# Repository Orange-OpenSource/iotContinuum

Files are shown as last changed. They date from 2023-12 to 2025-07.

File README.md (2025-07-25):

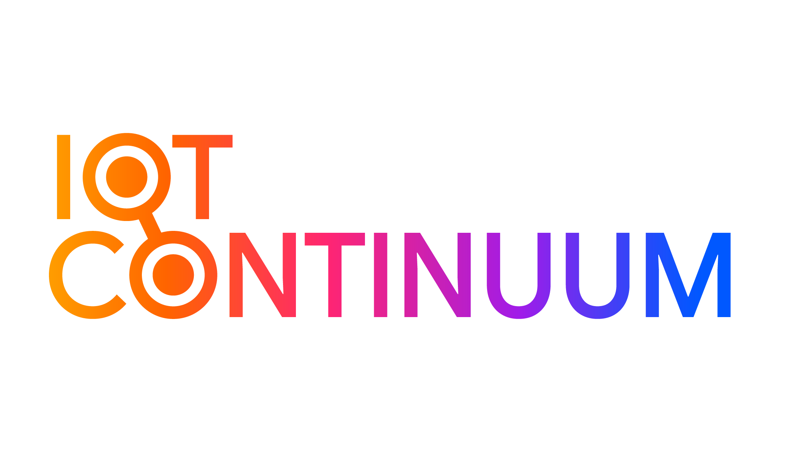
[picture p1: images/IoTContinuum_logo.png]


# IoT Continuum Development Kit




<picture>
 <source media="(prefers-color-scheme: dark)" srcset="images/devkit_general-white.png">
 <source media="(prefers-color-scheme: light)" srcset="images/devkit_general-black.png">
 IoT Continuum Dev Kit
</picture>

## Why IoT Continuum

With IoT Continuum, gain in efficiency by capitalizing on everything that has been achieved in your project's previous development cycles. Thus, the components and the design used from the start-up phase (PoC – Proof of Concept) are scalable and compatible with the industrial deployment phase. A new design will therefore no longer be necessary either during the next phase of Proof Of Value (convincing) or in the final phase of deployment and industrial scale-up.

There are two models of Development Kit. 

One is based on an HL7812 LTE-M/NB-IoT cellular connectivity module and the next is based on an RC7620 LTE-Cat 1 module. Both of these modules are from SEMTECH.
This development kit is provided by IoT Continuum to developers who are willing to start from scratch with a development kit approved by IoT Continuum.

Read more on [IoT Continuum Website](https://iotjourney.orange.com/fr-FR/iotcontinuum)

## List of available Devkits. 

•	DEVKIT HL7812
All documentation and source code for the HL7812 Devkit are available from the IoT Continuum [HL7812 Devkit link](DevKit-HL7812/README.md).

•	DEVKIT RC7620
For the RC7620-based DevKit, the components are available from the IoT Continuum [RC7620 Devkit link](DevKit-RC7620).

# License

The content of this repository is provided by Orange SA under the [MIT license](/LICENSE).

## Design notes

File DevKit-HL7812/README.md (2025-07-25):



# IoT Continuum Development Kit




<picture>
 <source media="(prefers-color-scheme: dark)" srcset="images/DevKit_face1-black.jpg">
 <source media="(prefers-color-scheme: light)" srcset="images/DevKit_face1-white.jpg">
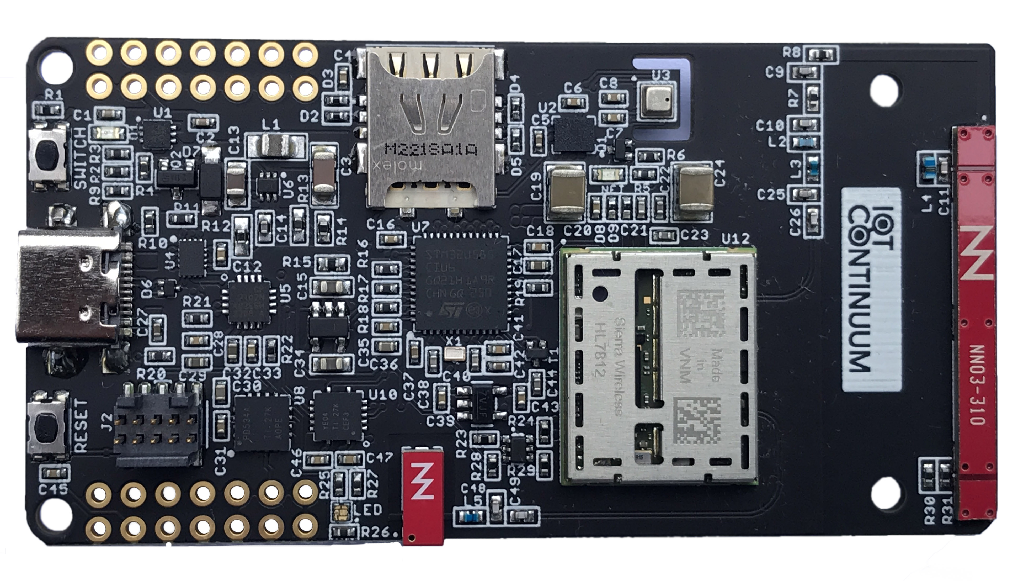
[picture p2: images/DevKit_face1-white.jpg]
IoT Continuum Dev Kit
 
</picture>

## Arduino IDE or STM32 Cube IDE?

2 Getting Started experiences are provided: one using the Arduino IDE (simpler) and the other one using the STM32 Cube IDE (recommended for proper engineering).

If you are discovering this development kit and are not familiar with STM32 Cube environment, we recommend you to [get started with the Arduino IDE](Arduino/README.md). Otherwise, the [STM32 Cube IDE](STM32Cube/) is the recommended way, especially because of its debug capabilities that are not available on Arduino environment.

## Specifications

<picture>
 <source media="(prefers-color-scheme: dark)" srcset="images/DevKit_face1-black-annotated.png">
 <source media="(prefers-color-scheme: light)" srcset="images/DevKit_face1-white-annotated.png">
 IoT Continuum Dev Kit
</picture>

|  |  |
| --- | --- |
| **Microcontroller** | STM32U585CIU6 (STM32U5 series)  |
| Architecture | Ultra-low-power ARM Cortex-M33 32bits with FPU, DSP, MPU |
| Flash Memory | 2MBytes |
| SRAM | 786 KB |
| Clock Speed | 160 MHz |
| Compatibility | Arduino, STM32 |
|  |  |
| **Board** size | 72.66 x 38.1 mm |
| Operating Voltage | 3.3V |
| I/O Pins | 24 |
| Analog Output Pin | 12-bit DAC |
| External Interrupts | Available on all pins |
| DC Current per I/O pin | 5 mA |
| Power | 5V USB power and/or 3.7 LiPo battery |
| Charging | Charge controller, up to 500mA charge current with battery meter |
|  |  |
| **Sensors** |  |
| BME280 | Humidity, Pressure, Temperature sensors |
| LSM6DSOX | Accelerometer, Gyroscope |
| LED | RGB LED |
|  |  |
| **Connectivity** |  |
| Cellular Module | Sierra Wireless HL7812 |
| Cellular | LTE-M, 2G |
| Positioning | GNSS |
| USB | USB-C Port |

## Pinout

### Outer PINs

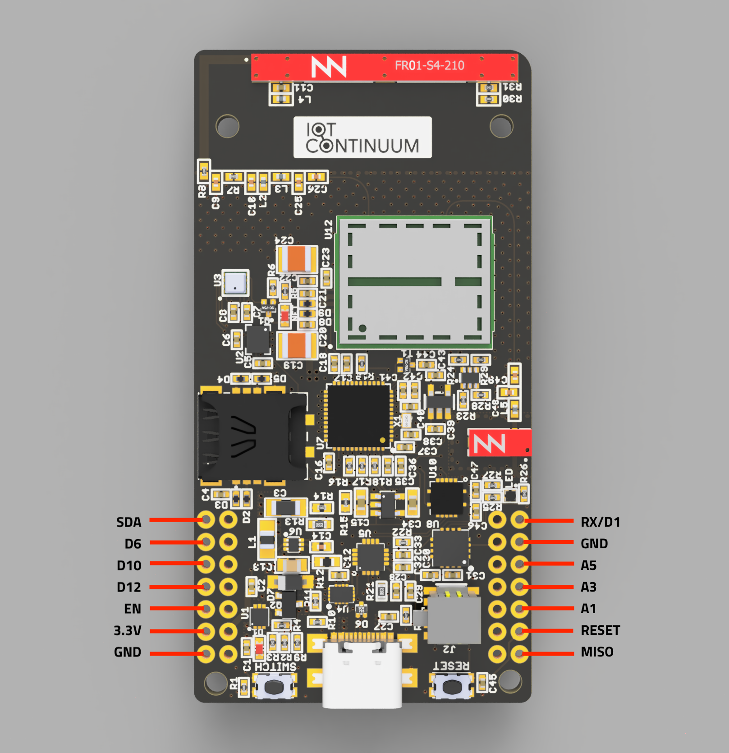
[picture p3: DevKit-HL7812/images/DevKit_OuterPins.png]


| I/O Pins | Arduino | STM32U585 |
| --- | --- | --- |
| 13 | IO13 | GPIO6 Expander |
| 12 | D12 | PB13 |
| 11 | D11 | PA11 |
| 10 | D10 | PA8 |
| 9 | D9 | PB15 |
| 6 | D6 | PB14 |
| 5 | D5 | PB10 |
| 4 | IO4 | GPIO1 Expander |
| SCL | D17 | PB6 |
| SDA | D18 | PB7 |
| RX/D1 | D1 | PA3 |
| TX/D0 | D0 | PA2 |
| A0 | A0/D2 | PA0 |
| A1 | A1/D3 | PA1 |
| A2 | A2/D4 | PA6 |
| A3 | A3/D7 | PB0 |
| A4 | A4/D8 | PB1 |
| A5 | A5/D13 | PB2 |
| SCK | D14 | PB3 |
| MISO | D15 | PB4 |
| MOSI | D16 | PB5 |

### Inner PINs

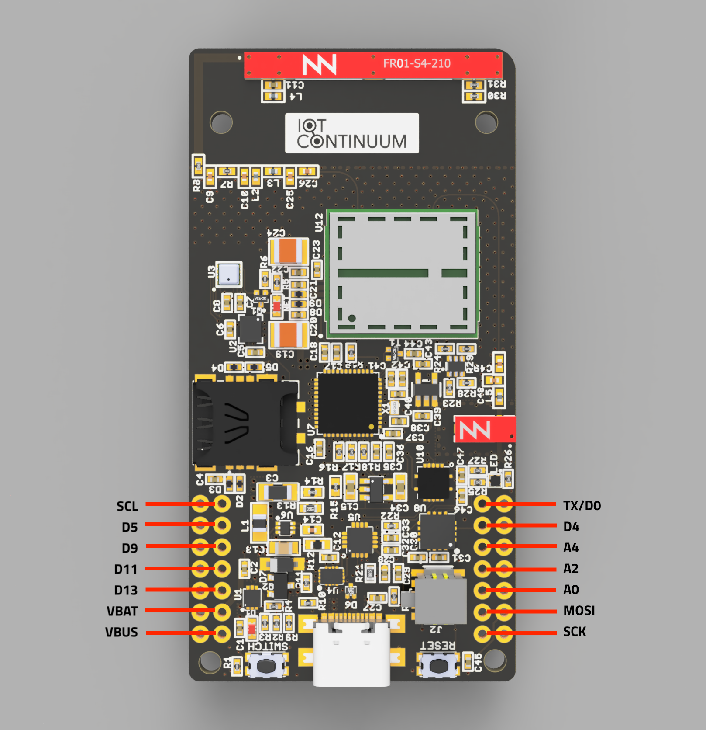
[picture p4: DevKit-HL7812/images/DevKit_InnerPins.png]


| I/O Pins | Arduino | STM32U585 | Comment |
| --- | --- | --- | --- |
| BAT_LEVEL | BAT_LEVEL | PA4 | Battery level |
| USB_UART_RX | PIN_SERIAL_RX | PA5 | RX to USB |
| USB_UART_TX | PIN_SERIAL_TX | PA7 | TX to USB |
| MODULE_TX | PIN_SERIAL3_TX | PA9 | TX to HL7812 |
| MODULE_RX | PIN_SERIAL3_RX | PA10 | RX to HL7812 |
| BUTTON | USER_BTN | PA12 | Push button status |
| SWDIO | NC | PA13 | J-TAG Programming |
| SWCLK | NC | PA14 | J-TAG Programming |
| WAKE_UP | WAKE_UP_HL7812 | PA15 | Module wake up on sleep |
| VGPIO | VGPIO | PC13 | Module state (active/on sleep) |
| SEL_MODE_UART | SWITCH_TO_HL7812 | PB8 | UART mode activation (STM32 or HL7812) |
| RESET MODULE | RESET_HL7812 | PB12 | Module Reset |
| INT2_ACCEL | INT_ACCEL | PB9 | LSM6DSOX interrupt state |
| LED RGB | RED_LED, GREEN_LED, BLUE_LED | NC | Led R=GPIO3, G=GPIO4, B=GPIO5 Expander |

# Development Environments

The IoT Continuum Development Kit is compatible with the following development environments:
* Arduino IDE: [Get started](Arduino/) -- recommended for a quick and easy start up
* STM32Cube IDE: [Get started](STM32Cube/) -- recommended for proper engineering (debug capabilities available)

# Firmware Upgrade

Check out the [Firmware Upgrade](Firmware_upgrade.md) section for upgrading the firmware of the various components of the Development Kit.

# Hardware Schematics

Hardware schematics are provided in [schematics](../schematics).

# License

The content of this repository is provided by Orange SA under the [MIT license](/LICENSE).

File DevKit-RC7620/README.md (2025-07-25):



# IoT Continuum Development Kit




<picture>
 <source media="(prefers-color-scheme: dark)" srcset="images/card-top-white.png">
 <source media="(prefers-color-scheme: light)" srcset="images/card-top-black.png">
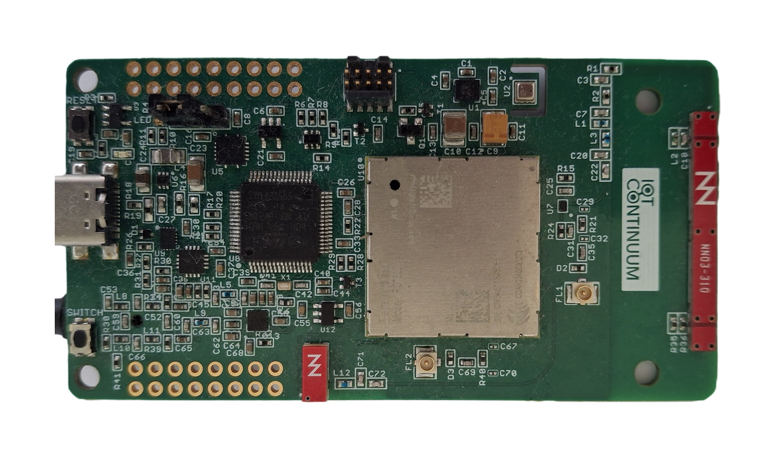
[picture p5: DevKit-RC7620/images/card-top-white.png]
 
</picture>

## Specifications

<picture>
 <source media="(prefers-color-scheme: dark)" srcset="images/card-legend-tb-white.png">
 <source media="(prefers-color-scheme: light)" srcset="images/card-legend-tb-black.png">
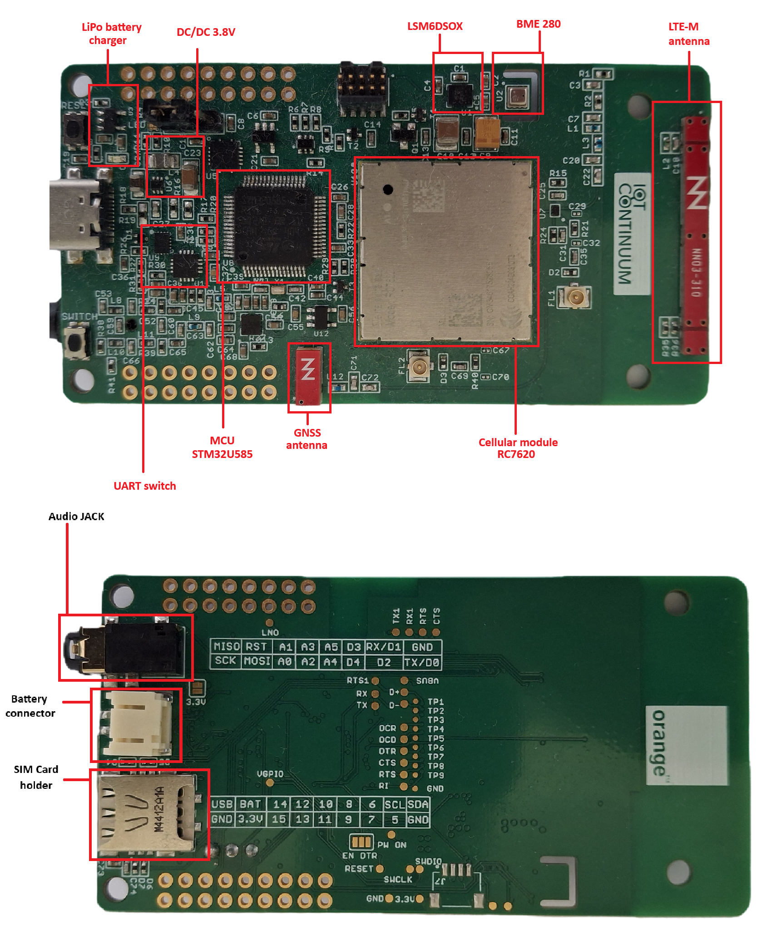
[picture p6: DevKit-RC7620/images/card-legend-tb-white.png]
 
</picture>

|  |  |
| --- | --- |
| **Microcontroller** | STM32U585RIT6 (STM32U5 series)  |
| Architecture | Ultra-low-power ARM Cortex-M33 32bits with FPU, DSP, MPU |
| Flash Memory | 2MBytes |
| SRAM | 786 KB |
| Clock Speed | 160 MHz |
| Compatibility | Arduino, STM32 |
|  |  |
| **Board** size | 83.25 x 43.54 mm |
| Operating Voltage | 3.3V |
| I/O Pins | 27 |
| Analog Output Pin | 12-bit DAC |
| External Interrupts | Available on all pins |
| DC Current per I/O pin | 5 mA |
| Power | 5V USB power and/or 3.7 LiPo battery |
| Charging | Charge controller, up to 500mA charge current with battery meter |
|  |  |
| **Sensors** |  |
| BME280 | Humidity, Pressure, Temperature sensors |
| LSM6DSOX | Accelerometer, Gyroscope |
| LED | RGB LED |
|  |  |
| **Connectivity** |  |
| Cellular Module | Semtech RC7620 |
| Cellular | 4G LTE Cat-1 3G and 2G fallback<br>VoLTE compatible |
| Positioning | GNSS |
| USB | USB-C Port |

## Pinout

### Outer PINs

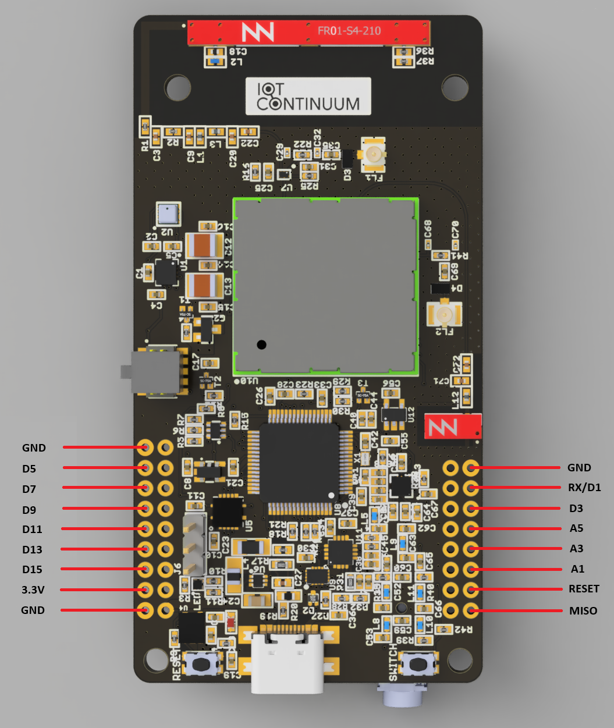
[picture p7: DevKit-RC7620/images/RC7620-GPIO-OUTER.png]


| I/O Pins | Arduino | STM32U585 |
| --- | --- | --- |
| 15 | D15 | PB8 |
| 14 | D14 | PA15 |
| 13 | D13 | PA12 |
| 12 | D12 | PB9 |
| 11 | D11 | PA8 |
| 10 | D10 | P11 |
| 9 | D9 | PB15 |
| 8 | D8 | PB10 |
| 7 | D7 | PB13 |
| 6 | D6| PB14 |
| 5 | D5 | PB12 |
| 4 | D4 | PB2 |
| 3 | D3 | PB1 |
| 2 | D2 | PB0 |
| RX/D1 | D1 | PA3 |
| TX/D0 | D0 |PA2 |
| SCL | D16 | PB6 |
| SDA | D17 | PB7 |
| A0 | A0 | PA0 |
| A1 | A1 | PA1 |
| A2 | A2 | PA4 |
| A3 | A3 | PA5 |
| A4 | A4 | PA6 |
| A5 | A5 | PA7 |
| SCK | D18 | PB3 |
| MISO | D19 | PB4|
| MOSI | D20 | PB5 |

### Inner PINs

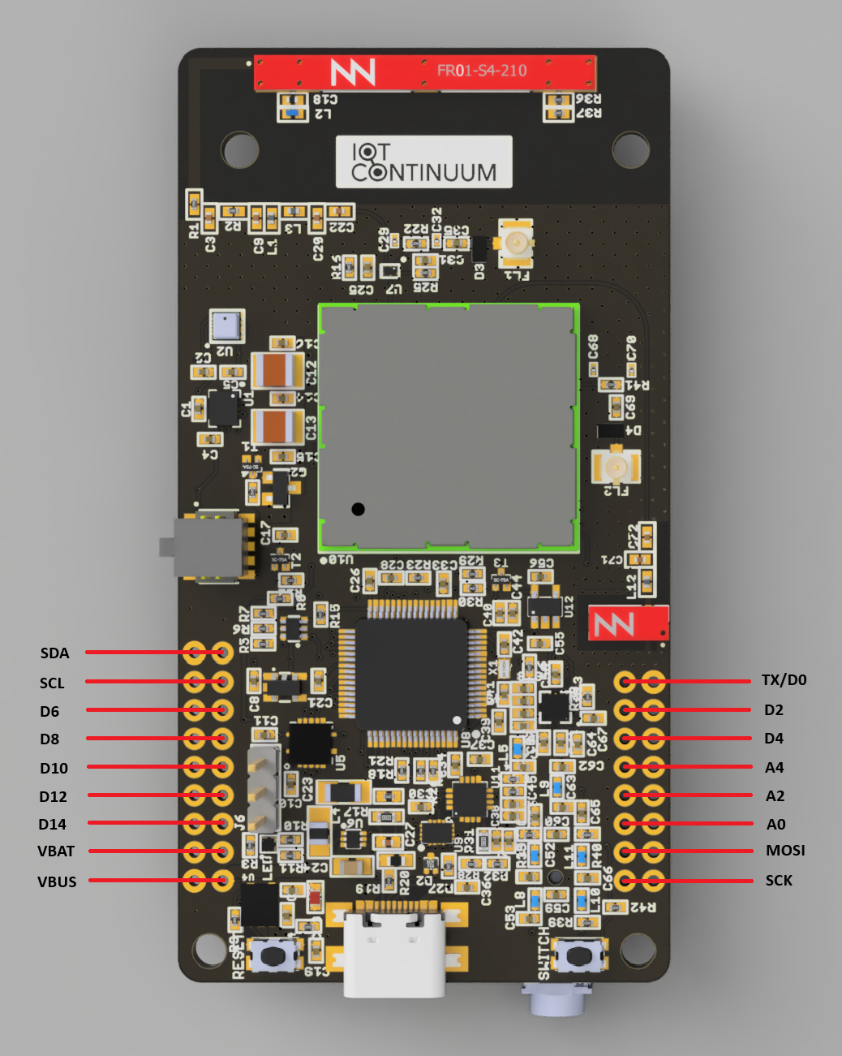
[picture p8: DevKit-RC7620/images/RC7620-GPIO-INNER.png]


| I/O Pins | Arduino | STM32U585 | Comment |
| --- | --- | --- | --- |
| BAT_LEVEL | BAT_LEVEL | PC3 | Battery level |
| USB_UART_RX | PIN_SERIAL_RX | PC11 | RX to USB |
| USB_UART_TX | PIN_SERIAL_TX | PC10 | TX to USB |
| MODULE_TX | PIN_SERIAL3_TX | PA9 | TX to HL7812 |
| MODULE_RX | PIN_SERIAL3_RX | PA10 | RX to HL7812 |
| BUTTON | USER_BTN | PC5 | Push button status |
| SWDIO | NC | PA13 | J-TAG Programming |
| SWCLK | NC | PA14 | J-TAG Programming |
| WAKE_UP | WAKE_UP_HL7812 | PD2 | Module wake up on sleep |
| VGPIO | VGPIO | PC13 | Module state (active/on sleep) |
| SEL_MODE_UART | SWITCH_TO_HL7812 | PC6 | UART mode activation (STM32 or HL7812) |
| RESET MODULE | RESET_HL7812 | PC9 | Module Reset |
| INT2_ACCEL | INT_ACCEL | PH1 | LSM6DSOX interrupt state |
| RF_CTRL | RF_CTRL | PC4 | Switch RF mode internal antenna=Low, uFL=High |
| RING_INDICATOR | RING_INDICATOR | PC8 | Ring indicator |
| POWER_MODULE | POWER_MODULE | PC7 | Power module off=Low, on=High |
| LED RGB | RED_LED | PC0 | Led Red of RGB LED |
| LED RGB | GREEN_LED | PC2 | Green Led of RGB LED |
| LED RGB | BLUE_LED | PC1 | Red Led of RGB LED |

# Development Environments

The IoT Continuum Development Kit is compatible with the following development environments:
* Arduino IDE: [Get started](Arduino/) -- recommended for a quick and easy start up
* STM32Cube IDE: [Get started](STM32Cube/) -- recommended for proper engineering (debug capabilities available)

# Firmware Upgrade

Check out the [Firmware Upgrade](Firmware_upgrade.md) section for upgrading the firmware of the various components of the Development Kit.

# Hardware Schematics

Hardware schematics are provided in [schematics](schematics).

# License

The content of this repository is provided by Orange SA under the [MIT license](/LICENSE).

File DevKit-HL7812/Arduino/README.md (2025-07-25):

# IoT Continuum

This page is part of the [IoT Continuum Dev Kit](/)

<picture>
 <source media="(prefers-color-scheme: dark)" srcset="../images/DevKit_face1-black.jpg">
 <source media="(prefers-color-scheme: light)" srcset="../images/DevKit_face1-white.jpg">
 IoT Continuum Dev Kit
</picture>

# Getting Started (Arduino IDE)

To run this getting started tutorial, you need the following hardware:
* 1 IoT Continuum Dev Kit
* 1 ST-LINK V3 Programmer (J-TAG)
* 1 Orange SIM card already activated and inserted in the SIM holder

## Arduino Environment Setup

This development environment is compatible with Windows, Mac & Linux.
If the Arduino IDE environment is not installed yet, install the latest version from [Arduino website](https://www.arduino.cc/en/software) -- would you encounter any issue with the latest version, note that we have succesfully tested the following versions: `1.8.19`, `2.1.1`, `2.2.1`

## Add support for STM32 in Arduino IDE

1. In the Arduino IDE, open the "Preferences" menu and add `https://github.com/stm32duino/BoardManagerFiles/raw/main/package_stmicroelectronics_index.json` to the "Additional boards manager URLs". Note: you may need to configure a proxy in the network tab to access Internet if you get a connection error at this point.

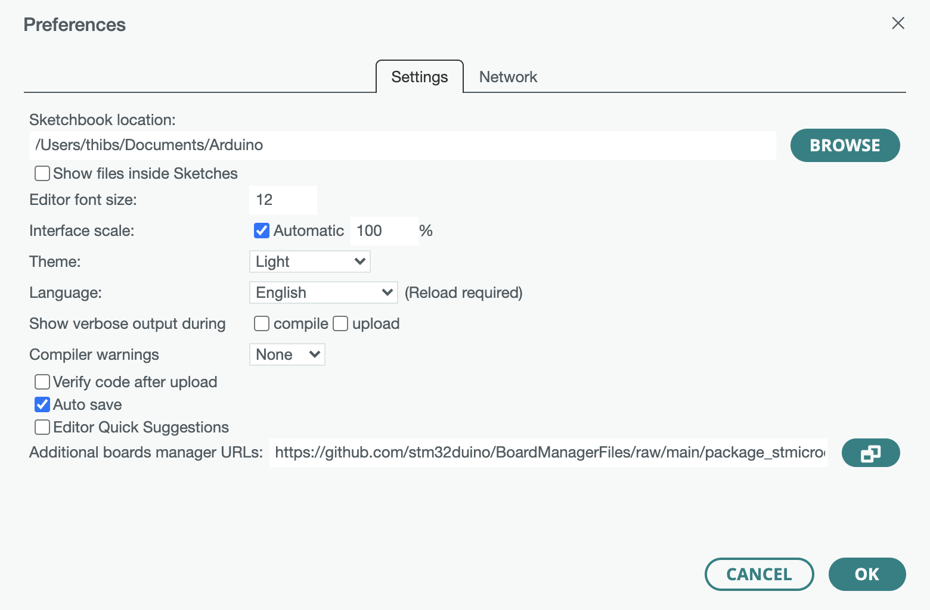
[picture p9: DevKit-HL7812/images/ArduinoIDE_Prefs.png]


2. In the "Tools" menu, select "Board" > "Boards Manager" submenu. Search for "STM32" using the search field at the top and click on ""STM32 by STMicroelectronics". Install the version `2.7.0`

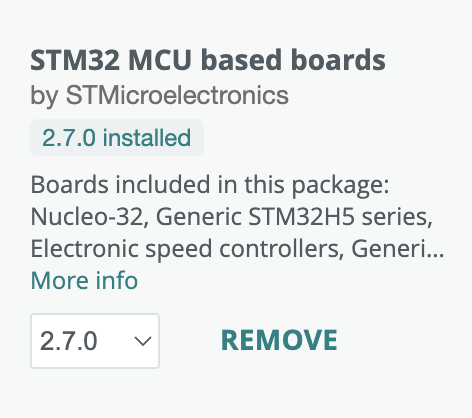
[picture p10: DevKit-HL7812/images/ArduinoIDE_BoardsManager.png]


## Select the STM32 hardware in Arduino IDE

For each new project opened in the Arduino IDE, you must select the board to use for compiling, and select the port the board is connected to to upload the program:
1. Make sure the board and the ST-LINK programmer are both connected to your computer with each a USB cable (use data cables, not power-only usb cables)
2. In the Arduino IDE, open the menu "Tools"
    1. In the submenu "Board" select the `STM32 MCU based board` and then `IoT continuum boards`
    2. In the submenu "Board part number" select `IoT continuum Dev Kit`
    3. Make sure that the “Upload method” is `STM32CubeProgrammer (SWD)`
    4. In the submenu "Port" select the Silicon Labs CP210x USB to UART (depending on your PC it may appear as "SLAB USB to UART"). If no such port appears, you may want to check that the USB port is showing up: look for "Silicon Labs CP210x USB to UART Bridge"
        * on Windows: open the Device Manager and look up in the "Port (COM & LPT)" section
        * on Mac and Linux: open a terminal and run `lsusb -v` command.
        * If it does not show up, install the driver from [here](https://www.silabs.com/developers/usb-to-uart-bridge-vcp-drivers?tab=downloads) and try again.
    5. Open the Serial Monitor and make sure the configuration is `115200 bauds`, `No Line Ending`

## Compile & Upload a first code

1. Unless STM32Cube environment is already installed on your development machine, you'll need to download the STM32CubeProgrammer first. Download it and install it from [here](https://www.st.com/en/development-tools/stm32cubeprog.html) using the default options -- Note: on MacOS, if the installer execution does nothing (bug), run it from the terminal with the command `./SetupSTM32CubeProgrammer-2.14.0.app/Contents/MacOs/SetupSTM32CubeProgrammer-2_14_0_macos` (the name of the file may change with a newer version)

3. With an empty project or using the [HelloWorld code sample](examples/HelloWorld), use the right arrow button in the Arduino IDE to compile and upload your program into the IoTContinuum Dev Kit.



You should get the following output:
```
-------------------------------------------------------------------
STM32CubeProgrammer v2.14.0
-------------------------------------------------------------------
ST-LINK SN : 001800363137511133333639 ST-LINK FW : V3J11M3
Board : STLINK-V3MINI
Voltage : 3.25V
SWD freq : 8000 KHz
Connect mode: Under Reset
Reset mode : Hardware reset
Device ID : 0x482
Revision ID : Rev X
Device name : STM32U575/STM32U585 Flash size : 2 MBytes
Device type : MCU
Device CPU : Cortex-M33
BL Version : 0x92
Debug in Low Power mode enabled
-------------------------------------------------------------------
Choose flashing speed for Cortex M33 series.(default speed=Reliable)
-------------------------------------------------------------------
Memory Programming ...
Opening and parsing file: Test_devkit.ino.bin
File
Size Address
: HelloWorld.ino.bin : 39.65 KB
: 0x08000000
Erasing memory corresponding to segment 0:
Erasing internal memory sectors [0 4] Download in Progress:
File download complete
Time elapsed during download operation: 00:00:00.425 RUNNING Program ...
Address: : 0x8000000
Application is running, Please Hold on...
Start operation achieved successfully
```

## Adding mandatory libraries to Arduino IDE

The following libraries must be installed in the Arduino IDE:
* The IoTcontinuum devkit library (which includes the following libs: PCA9534 GPIO Expander, HL7812, MQTT):
    1. Download [lib/iotcontinuum_devkit.zip](lib/iotcontinuum_devkit.zip) (sources are available in [src](src/))
    2. Open the menu "Sketch" > "Include Library" > "Add .ZIP Library" and select the .zip file downloaded
* BME280 humidity/pressure/temperature sensor: select and install the BME280 library by Tyler Glenn (3.0.0 or above) from the Arduino IDE library
* LSM6DSOX accelerometer/gyroscope sensor: select and install the LSM6DSOX library by SRA (2.3.3 or above) from the Arduino IDE library
* MQTT: select and install the MQTT library by Joel Gaehwiler (2.5.1 or above) from the Arduino IDE library

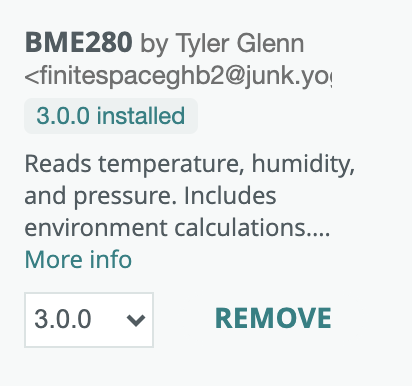
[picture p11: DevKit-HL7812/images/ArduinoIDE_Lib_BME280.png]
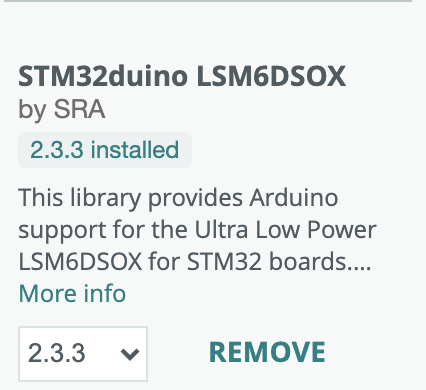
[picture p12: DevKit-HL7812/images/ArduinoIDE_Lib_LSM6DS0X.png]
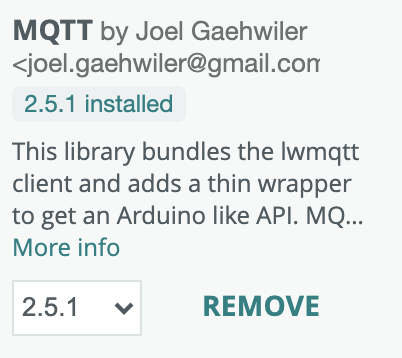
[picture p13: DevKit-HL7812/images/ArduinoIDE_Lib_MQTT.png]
 &nbsp;  &nbsp; 

## Code Samples

You are now ready to check out few code samples! We suggest that you start by the following examples:

1. [Hello World](examples/HelloWorld) -- always start with the simplest code possible: let's make a LED blink!
1. [Monitor onboard sensors](examples/Sensors) -- now, let's learn how to read all onboard sensors
1. [Send AT Commands to the HL7812 cellular module](examples/ATCommands_HL7812) -- let's learn how to communicate with the cellular module
1. [Send data to Orange Live Objects using MQTT on LTE-M cellular network](examples/LiveObjects)

If you made it until there, you are now ready to explore more code samples by yourself from the [examples folder](examples) -- Enjoy!

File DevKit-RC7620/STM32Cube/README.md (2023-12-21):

# IoT Continuum

This page is part of the [IoT Continuum Dev Kit](/)

> [!IMPORTANT]
> This section is under construction:
> Only the installation of the IDE is covered for now. In particular, **NO code examples are provided** for now.
> Stay tuned!

<picture>
 <source media="(prefers-color-scheme: dark)" srcset="/images/DevKit_face1-black.jpg">
 <source media="(prefers-color-scheme: light)" srcset="/images/DevKit_face1-white.jpg">
 IoT Continuum Dev Kit
</picture>

# Getting Started (STM32CubeIDE)

To run this getting started tutorial, you need the following hardware:
* 1 IoT Continuum Dev Kit
* 1 ST-LINK V3 Programmer (J-TAG)
* 1 Orange SIM card already activated and inserted in the SIM holder

## Install STM32CubeIDE

This development environment is compatible with Windows, Mac & Linux.
If the STM32CubeIDE environment is not installed yet, install the latest version from [ST website](https://www.st.com/en/development-tools/stm32cubeide.html)

## Project Setup

1. Launch STM32CubeIDE
2. Create a new STM32 Project: Menu "File" > "New" > "STM32 Project"
3. In the left panel, use the "Commercial Part Number" field and enter "STM32U585CIU6" in order the filter the list of boards on the bottom right

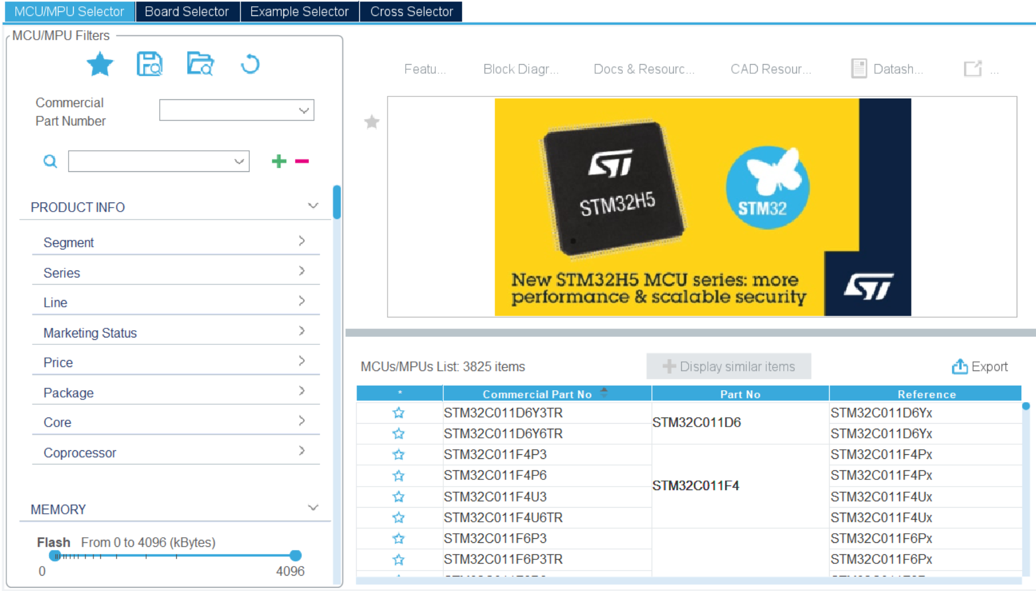
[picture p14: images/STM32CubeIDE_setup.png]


5. Then, select the STM32U585CIU6 board in the list (bottom right panel), and click on the "Next" button
6. Give a name to your project like "HelloWorld" and then click on "Finish"

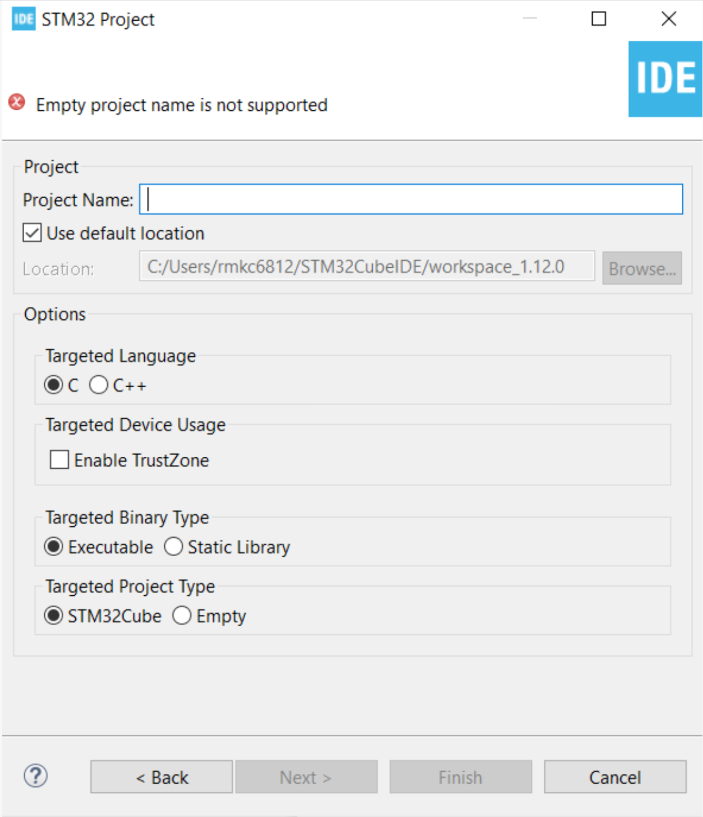
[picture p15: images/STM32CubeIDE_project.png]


## Hardware Setup

STM32Cube provides a graphical user interface to help with setting up the microcontroller and its peripherals from the main window of the IDE, and generate the code: use the menu on the left to activate and setup each different feature.

Open "System Core" then "ICACHE" and click the "Memory address remap" 

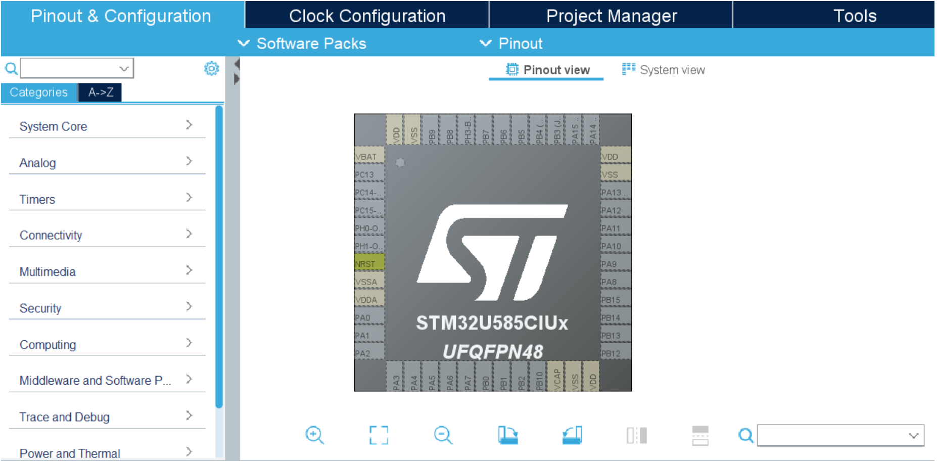
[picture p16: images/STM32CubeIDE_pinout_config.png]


Before using the code generation, you need to log in "My ST" profile or create a new account from the "My ST" upper menu (last one on the right).

To generate the code, just save the configuration with `Ctrl-S` or from the menu: "File" > "Save"

**Note**: STM32CubeIDE is based on EclipseIDE engine which allows different "perspectives" (aka layouts/views). When generating the code, the IDE suggests to switch to the code perspective. Accept it. You will always be able to change perspective using the top right corner icons.

## Code writing

Open the generated `Core/Src/main.c` file. Note the comments `USER CODE BEGIN...` and `USER CODE END...` and take care to add your code in between those tags so that if you change the configuration and regenerate the code, your code will stay safe.

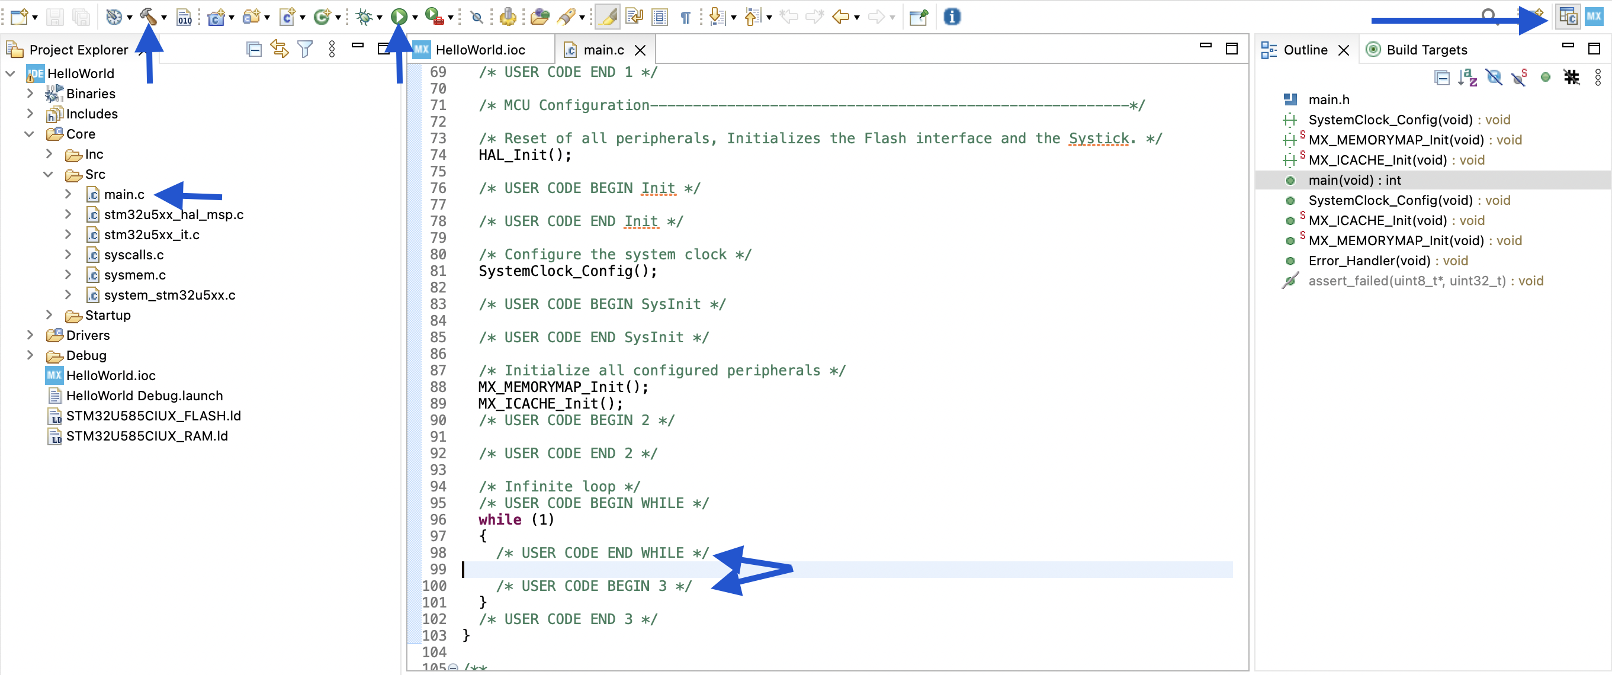
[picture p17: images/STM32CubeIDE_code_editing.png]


## Compilation and upload

1. To build your code, use the hammer button ("Build")
2. Make sure the board and the ST-LINK programmer are both connected to your computer with each a USB cable (use data cables, not power-only usb cables). In case of doubt, you can check that both `Silicon Laboratories, Inc. CP2102N USB to UART Bridge Controller` and `STMicroelectronics STLINK-V3` are showing up on the USB:
  * on Windows: open the Device Manager and look in the USB section
  * on Mac and Linux: open a terminal and run `lsusb -v` command.
  * If it does not show up, install the driver from [here](https://www.silabs.com/developers/usb-to-uart-bridge-vcp-drivers?tab=downloads) and try again. 
3. Upload your program onto the device and run it using the arrow button ("Run")

## Learn more about STM32CubeIDE

To learn more about the STM32CubeIDE features, we recommend you to check out these [how-to & tutorial videos](https://wiki.st.com/stm32mcu/wiki/CubeIDE:Introduction_to_STM32CubeIDE#Videos_related_to_STM32CubeIDE)

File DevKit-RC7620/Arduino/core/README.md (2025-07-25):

## How to install Arduino IoT Continuum Core

After installing stm32duino, place the U575R(G-I)T_U585RIT folder in the packages\framework-arduinoststm32\variants\STM32U5xx directory. Answer "overwrite files" if the directory already exists.

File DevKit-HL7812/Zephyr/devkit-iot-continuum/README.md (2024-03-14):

# DevKit Iot continuum Application

This repository contains a DevKit Iot continuum example application and the devkit_iot_continuum BSP. The main purpose of this
repository is to serve as a reference on how to structure Zephyr-based applications on DevKit Iot continuum board.

## Getting Started

Before getting started, make sure you have a proper Zephyr development environment. 
WARNING : During the zephyr starting guide, you may experienced some issues:

    - Take care if your OS is windows to be in the "Windows" -> "install globally" section during the chapter "Get Zephyr and install Python dependencie"
    - For Chocolatey installation, we recommend to use Windows powershell prompt with admin rights.
    - Globally, even is they tell you that you can go to non-admin cmd prompt, stay in admin cmd prompt.
    - While installing python dependencies, you can face problem with "west". in that case, you may uninstall and install again.

Follow the official [Zephyr Getting Started Guide] (https://docs.zephyrproject.org/latest/getting_started/index.html) for your OS until you reach the chapter "Build the Blinky Sample".

In order to check that you have working environnement, you can use the board "nucleo_u575zi_q" for the "<your-board-name>" in the chapter "Build the Blinky Sample" of the zephyr getting started guide.

### Initialization

Create a folder which will be your workspace (for example : ``my-workspace``).

WARNING: 

    - For the following command (west init), please make sure to have your github credentials.
    - You can either use https or ssh connetion for cloning the repositorie.

The first step is to initialize the workspace folder (``my-workspace``) where
the ``devkit_iot_continuum`` application and all Zephyr modules will be cloned. Open a cmd prompt in ``my-workspace`` folder and run the following
command:

```shell or command prompt
# initialize my-workspace for the devkit_iot_continuum application (main branch)
cd ..
west init -m https://github.com/lacroix-group/Orange-Zephyr-devkit.git --mr main my-workspace
# update Zephyr modules
cd my-workspace
cd devkit-iot-continuum
west update
```
### STM32Cube programmer installation

In order to flash devkit_iot_continuum board, we recommend to use STM32CubeProgrammer.
You can find STM32CubeProgrammer software on STM32 website [here](https://www.st.com/en/development-tools/stm32cubeprog.html)

### Building and running

To build the application, run the following command:

```shell
cd <my-workspace>/devkit-iot-continuum/demo_devkit_iot_continuum/<demo>
west build -b devkit_iot_continuum -p
```

Before running, you have to :

    (1) : Connect USB-C cable between devkit_iot_continuum board and your computer.

    (2) : Connect STLINK/V2 device on the board(connector J2) and your computer. (you have have to install [STLINK/V2 device driver](https://www.st.com/en/development-tools/stsw-link009.html))

    (3) : Insert a SIM Card into the device (only for Modem demo or it will failled).

Once you have built the application, run the following command to flash it :

```shell
west flash
```
In case of an error with STM32CubeProgrammer, you may want to add STM32_Programmer_CLI to your PATH.

In order to see logs, you have to install USB Uart driver [install link](https://www.silabs.com/developers/usb-to-uart-bridge-vcp-drivers) and a UART communication programm like TeraTerm or Minicom.

Once the board is flashed, use one of the previous UART Communication program and listen to the COM port called (Silicon Labs CP210x USB to UART Bridge) with a baudrate of 115200.

Reset the board to see the log from the beggining.

In case of succesfull manipulation, you should see something like this with the devkit_iot_continuum demo application:
```shell
[00:00:00.004,000] <inf> pca953x: pca953x@38 init ok
[00:00:00.005,000] <inf> modem_hl7812: Modem Run
[00:00:00.015,000] <inf> modem_hl7812: Modem Reset
[00:00:00.065,000] <inf> modem_hl7812: Sleep State: UNINITIALIZED
[00:00:00.065,000] <inf> modem_hl7812: Network State: 0 NOT_REGISTERED
[00:00:00.065,000] <inf> modem_hl7812: Startup State: UNKNOWN
[00:00:00.065,000] <inf> modem_hl7812: Modem Run
[00:00:05.580,000] <inf> modem_hl7812: Network State: 2 SEARCHING
[00:00:06.199,000] <inf> modem_hl7812: Startup State: READY
[00:00:06.199,000] <inf> modem_hl7812: Sleep State: AWAKE
[00:00:06.199,000] <inf> modem_hl7812: Modem booted!
[00:00:07.355,000] <inf> modem_hl7812: Revision: HL7812.5.4.10.0
[00:00:07.358,000] <inf> modem_hl7812: +KSRAT: 0 (0:CAT-M1, 1:NB-IoT and 2:GSM)
[00:00:07.378,000] <inf> modem_hl7812: Current band configuration: 0000 00000000 00080818
[00:00:07.383,000] <inf> modem_hl7812: Bottom band mismatch, want 0808189f got 00080818
[00:00:07.430,000] <inf> modem_hl7812: Current band configuration: 0000 00000000 0808189f
[00:00:14.148,000] <inf> modem_hl7812: Network State: 2 SEARCHING
[00:00:14.839,000] <inf> modem_hl7812: Startup State: READY
[00:00:14.839,000] <inf> modem_hl7812: Sleep State: AWAKE
[00:00:14.840,000] <inf> modem_hl7812: Modem booted!
[00:00:15.167,000] <inf> modem_hl7812: Manufacturer: Sierra Wireless
[00:00:15.220,000] <inf> modem_hl7812: Model: HL7812
[00:00:15.273,000] <inf> modem_hl7812: IMEI: 351144440344308
[00:00:15.277,000] <inf> modem_hl7812: Serial #: AN3021324101B1
[00:00:15.354,000] <inf> modem_hl7812: ICCID: 89330123107805289340
[00:00:15.407,000] <inf> modem_hl7812: IMSI: 208012402781283
[00:00:15.640,000] <inf> modem_hl7812: Network State: 2 SEARCHING
[00:00:15.664,000] <inf> modem_hl7812: Modem ready!
[00:00:15.669,000] <inf> LSM6DSO: Initialize device lsm6dso@6a
[00:00:15.670,000] <inf> LSM6DSO: chip id 0x6c
*** Booting Zephyr OS build zephyr-v3.4.0-1907-g168de28b40a4 ***
[00:00:15.675,000] <dbg> demo_devkit:
[00:00:15.675,000] <dbg> demo_devkit: **************************************
[00:00:15.675,000] <dbg> demo_devkit: ***** DevKit Iot Continuuum Demo *****
[00:00:15.675,000] <dbg> demo_devkit: **************************************

[00:00:15.676,000] <dbg> demo_devkit: Led example

[00:00:15.676,000] <dbg> demo_devkit: -> Red LED for 3 seconds
[00:00:16.143,000] <inf> modem_hl7812: Operator: 0
[00:00:18.677,000] <dbg> demo_devkit: -> Green LED for 3 seconds
[00:00:21.677,000] <dbg> demo_devkit: -> Blue LED for 3 seconds

[00:00:24.678,000] <dbg> demo_devkit: BME280 example

[00:00:24.688,000] <dbg> demo_devkit:  Fetch BME280 n°1
[00:00:24.688,000] <dbg> demo_devkit:  Temperature BME280 305
[00:00:24.688,000] <dbg> demo_devkit:  Pression BME280 1016
[00:00:24.688,000] <dbg> demo_devkit:  Humidity BME280 27

[00:00:26.699,000] <dbg> demo_devkit:  Fetch BME280 n°2
[00:00:26.699,000] <dbg> demo_devkit:  Temperature BME280 305
[00:00:26.699,000] <dbg> demo_devkit:  Pression BME280 1016
[00:00:26.699,000] <dbg> demo_devkit:  Humidity BME280 27

[00:00:28.710,000] <dbg> demo_devkit:  Fetch BME280 n°3
[00:00:28.710,000] <dbg> demo_devkit:  Temperature BME280 305
[00:00:28.710,000] <dbg> demo_devkit:  Pression BME280 1016
[00:00:28.710,000] <dbg> demo_devkit:  Humidity BME280 27

[00:00:30.720,000] <dbg> demo_devkit:  Fetch BME280 n°4
[00:00:30.720,000] <dbg> demo_devkit:  Temperature BME280 305
[00:00:30.720,000] <dbg> demo_devkit:  Pression BME280 1016
[00:00:30.720,000] <dbg> demo_devkit:  Humidity BME280 26

[00:00:32.731,000] <dbg> demo_devkit:  Fetch BME280 n°5
[00:00:32.731,000] <dbg> demo_devkit:  Temperature BME280 306
[00:00:32.731,000] <dbg> demo_devkit:  Pression BME280 1016
[00:00:32.731,000] <dbg> demo_devkit:  Humidity BME280 26

[00:00:34.731,000] <dbg> demo_devkit: LSM6DSO example

[00:00:34.734,000] <dbg> demo_devkit:  Fetch LSM6DSO n°1
[00:00:34.734,000] <dbg> demo_devkit:  Acceleration X:2763, Acceleration Y:7102 , Acceleration Z:6578
[00:00:34.734,000] <dbg> demo_devkit:  Rotation X:2, Rotation Y:-5 , Rotation Z:-1

[00:00:36.734,000] <dbg> demo_devkit:  Fetch LSM6DSO n°2
[00:00:36.734,000] <dbg> demo_devkit:  Acceleration X:2768, Acceleration Y:7135 , Acceleration Z:6525
[00:00:36.734,000] <dbg> demo_devkit:  Rotation X:3, Rotation Y:-6 , Rotation Z:-1

[00:00:38.735,000] <dbg> demo_devkit:  Fetch LSM6DSO n°3
[00:00:38.735,000] <dbg> demo_devkit:  Acceleration X:2768, Acceleration Y:7142 , Acceleration Z:6528
[00:00:38.735,000] <dbg> demo_devkit:  Rotation X:3, Rotation Y:-6 , Rotation Z:-1

[00:00:40.736,000] <dbg> demo_devkit:  Fetch LSM6DSO n°4
[00:00:40.736,000] <dbg> demo_devkit:  Acceleration X:2771, Acceleration Y:7140 , Acceleration Z:6524
[00:00:40.736,000] <dbg> demo_devkit:  Rotation X:4, Rotation Y:-6 , Rotation Z:-1

[00:00:42.737,000] <dbg> demo_devkit:  Fetch LSM6DSO n°5
[00:00:42.737,000] <dbg> demo_devkit:  Acceleration X:2771, Acceleration Y:7138 , Acceleration Z:6530
[00:00:42.737,000] <dbg> demo_devkit:  Rotation X:3, Rotation Y:-6 , Rotation Z:-1

[00:00:44.737,000] <dbg> demo_devkit: Modem example

[00:00:45.125,000] <dbg> bsp_modem_sierra: Writing APN: OK
[00:00:45.125,000] <dbg> bsp_modem_sierra: Initialization of Sierra LTE Module HL7812 success
[00:01:00.126,000] <dbg> demo_devkit: Modem try to connect
[00:01:00.126,000] <dbg> bsp_modem_sierra: Waiting Connection of Sierra LTE Module HL7812
[00:01:15.126,000] <dbg> demo_devkit: Modem try to connect
[00:01:15.126,000] <dbg> bsp_modem_sierra: Waiting Connection of Sierra LTE Module HL7812
[00:01:30.126,000] <dbg> demo_devkit: Modem try to connect
[00:01:30.126,000] <dbg> bsp_modem_sierra: Waiting Connection of Sierra LTE Module HL7812
[00:01:33.207,000] <inf> modem_hl7812: Network State: 0 NOT_REGISTERED
[00:01:33.216,000] <inf> modem_hl7812: Network State: 2 SEARCHING
[00:01:33.961,000] <inf> modem_hl7812: Operator: 0,0,"Orange F",7
[00:01:33.965,000] <inf> modem_hl7812: Network State: 1 HOME_NETWORK
[00:01:34.470,000] <inf> modem_hl7812: Operator: 0,0,"Orange F",7
[00:01:45.126,000] <dbg> demo_devkit: Modem try to connect
[00:01:45.126,000] <dbg> bsp_modem_sierra: Connected to HOME NETWORK
[00:01:45.183,000] <dbg> bsp_modem_sierra: Set HTTP config: OK
[00:01:45.183,000] <dbg> bsp_modem_sierra: HTTP Connection of Sierra LTE Module HL7812 success
[00:01:45.841,000] <inf> modem_hl7812: Received message:  200 OK
[00:01:50.448,000] <dbg> bsp_modem_sierra: Get data success
```

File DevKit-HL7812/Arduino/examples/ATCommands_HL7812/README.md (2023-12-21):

# IoT Continuum

This page is part of the [IoT Continuum Dev Kit](/) / [Arduino](/Arduino) section

<picture>
 <source media="(prefers-color-scheme: dark)" srcset="/images/DevKit_face1-black.jpg">
 <source media="(prefers-color-scheme: light)" srcset="/images/DevKit_face1-white.jpg">
 IoT Continuum Dev Kit
</picture>

# Send AT Commands to the HL7812 cellular module

[This sample code](ATCommands_HL7812.ino) reads AT command inputs from the Arduino IDE's Serial Monitor, sends it to the HL7812, read the response back and display it in the Serial Monitor.

You can use this program as a convenient AT command console to the HL7812 from your Arduino IDE.

AT Commands documentation for HL7812 can be found [here](https://source.sierrawireless.com/resources/airprime/software/hl78xx_at_commands_interface_guide/).

Here are few useful commands you may want to test:
* `ATI3` (gives back the firmware version of the HL7812 module)
* `AT+CCID` (gives back the ICCID)
* `AT+CGSN=1` (gives back the EMEI of the module)
* `AT+CREG?` (gives back the registration status to the cellular network)
* `AT+CSQ` (gives back the quality of the cellular signal)
* ...

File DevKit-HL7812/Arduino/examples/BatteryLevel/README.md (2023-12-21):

# IoT Continuum

This page is part of the [IoT Continuum Dev Kit](/) / [Arduino](/Arduino) section

<picture>
 <source media="(prefers-color-scheme: dark)" srcset="/images/DevKit_face1-black.jpg">
 <source media="(prefers-color-scheme: light)" srcset="/images/DevKit_face1-white.jpg">
 IoT Continuum Dev Kit
</picture>

# Monitor the battery level

[This sample code](BatteryLevel.ino) reads the battery level and displays it in the Serial Monitor. You can use the Arduino IDE's Serial Ploter too to graph the result.

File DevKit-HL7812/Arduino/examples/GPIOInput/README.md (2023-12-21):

# IoT Continuum

This page is part of the [IoT Continuum Dev Kit](/) / [Arduino](/Arduino) section

<picture>
 <source media="(prefers-color-scheme: dark)" srcset="/images/DevKit_face1-black.jpg">
 <source media="(prefers-color-scheme: light)" srcset="/images/DevKit_face1-white.jpg">
 IoT Continuum Dev Kit
</picture>

# Controling GPIOs managed by the GPIO Expander

[This sample code](GPIOInput.ino) shows you how to control GPIOs 4 and 13 which are managed by the GPIO expander PCA9534

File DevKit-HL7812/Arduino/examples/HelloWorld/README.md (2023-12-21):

# IoT Continuum

This page is part of the [IoT Continuum Dev Kit](/) / [Arduino](/Arduino) section

<picture>
 <source media="(prefers-color-scheme: dark)" srcset="/images/DevKit_face1-black.jpg">
 <source media="(prefers-color-scheme: light)" srcset="/images/DevKit_face1-white.jpg">
 IoT Continuum Dev Kit
</picture>

# Arduino HelloWorld code sample

This simple code displays "Hello World" in the Serial Monitor of the Arduino IDE, and repeatedly blinks the LED in red.
Make sure you have followed the [Getting Started](/Arduino) instructions first before running this code sample.

```c
#include <Wire.h>
#include "PCA9534.h"

PCA9534 gpio;

void setup() { 
  Serial.begin(115200);
  gpio.begin();
  Wire.begin();
  gpio.pinMode(GPIO_PIN_LED_RED, OUTPUT);
  delay(2000);
  Serial.println("Hello world");
}

void loop() {
  // put your main code here, to run repeatedly:
  gpio.digitalWrite(GPIO_PIN_LED_RED, LOW); // LED On
  delay(500);
  gpio.digitalWrite(GPIO_PIN_LED_RED, HIGH); // LED Off
  delay(500);
}
```

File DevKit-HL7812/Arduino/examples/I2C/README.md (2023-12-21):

# IoT Continuum

This page is part of the [IoT Continuum Dev Kit](/) / [Arduino](/Arduino) section

<picture>
 <source media="(prefers-color-scheme: dark)" srcset="/images/DevKit_face1-black.jpg">
 <source media="(prefers-color-scheme: light)" srcset="/images/DevKit_face1-white.jpg">
 IoT Continuum Dev Kit
</picture>

# I2C Scan

[This sample code](I2C.ino) performs a scan of all I2C devices onboard or connected to the board

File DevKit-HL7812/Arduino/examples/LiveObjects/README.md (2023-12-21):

# IoT Continuum

This page is part of the [IoT Continuum Dev Kit](/) / [Arduino](/Arduino) section

<picture>
 <source media="(prefers-color-scheme: dark)" srcset="/images/DevKit_face1-black.jpg">
 <source media="(prefers-color-scheme: light)" srcset="/images/DevKit_face1-white.jpg">
 IoT Continuum Dev Kit
</picture>

# LiveObjects MQTT

[This sample code](LiveObjects.ino) shows how to send sensors data using MQTT protocol with the HL7812 to LiveObjects servers.
NOTE: LiveObjects credentials must be replaced in [ConfigLiveObjects.h](ConfigLiveObjects.h) file first:

Replace the term "KeyBox" in the following strings with your device name on LiveObject:
```c
#define DEVICE_NAME             "KeyBox"
#define STREAM_ID_CONFIG        "urn:lo:nsid:KeyBoxConfig"
#define STREAM_ID_DATA          "urn:lo:nsid:KeyBoxData"
#define STREAM_ID_EVENT         "urn:lo:nsid:KeyBoxEvent"
```
and put your LiveObjects API key in:
```c
#define MQTT_PASSWORD           "<liveobjects key>"
```

All done! Connect to [Live Objects](https://liveobjects.orange-business.com/) to access your data feed:
 
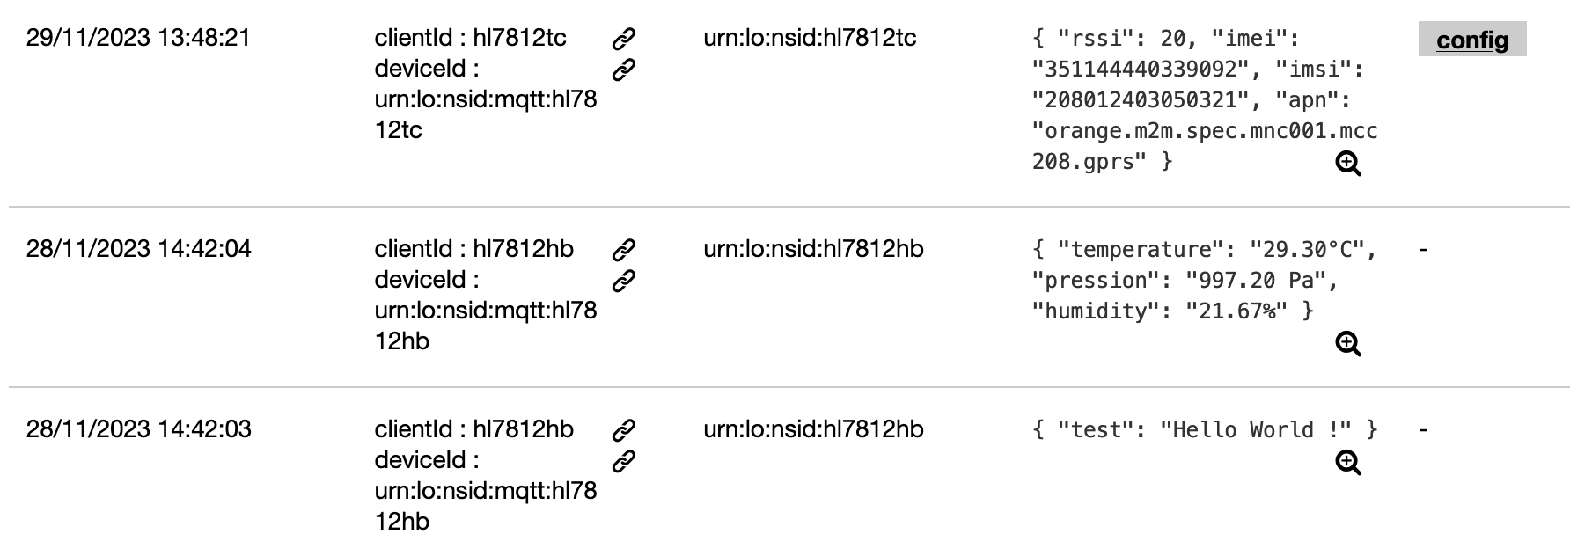
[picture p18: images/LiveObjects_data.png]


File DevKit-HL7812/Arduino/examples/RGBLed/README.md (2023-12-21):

# IoT Continuum

This page is part of the [IoT Continuum Dev Kit](/) / [Arduino](/Arduino) section

<picture>
 <source media="(prefers-color-scheme: dark)" srcset="/images/DevKit_face1-black.jpg">
 <source media="(prefers-color-scheme: light)" srcset="/images/DevKit_face1-white.jpg">
 IoT Continuum Dev Kit
</picture>

# RGB LED

[This sample code](RGBLed.ino) shows how to control the RGB LED which is managed by the PCA9534 GPIO expander

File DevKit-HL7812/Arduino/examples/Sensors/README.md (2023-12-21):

# IoT Continuum

This page is part of the [IoT Continuum Dev Kit](/) / [Arduino](/Arduino) section

<picture>
 <source media="(prefers-color-scheme: dark)" srcset="/images/DevKit_face1-black.jpg">
 <source media="(prefers-color-scheme: light)" srcset="/images/DevKit_face1-white.jpg">
 IoT Continuum Dev Kit
</picture>

# Read onboard sensors data and plot them in the Serial Plotter

This [code sample](Sensors.ino) reads the following sensors and sends them to the Serial Monitor in the Arduino IDE in a format that is plottable with the Serial Plotter of the Arduino IDE:
* From BME280 (I2C): temperature, humidity, sensor
* From LSM6DSOX (I2C): Accelerometer, Gyroscope

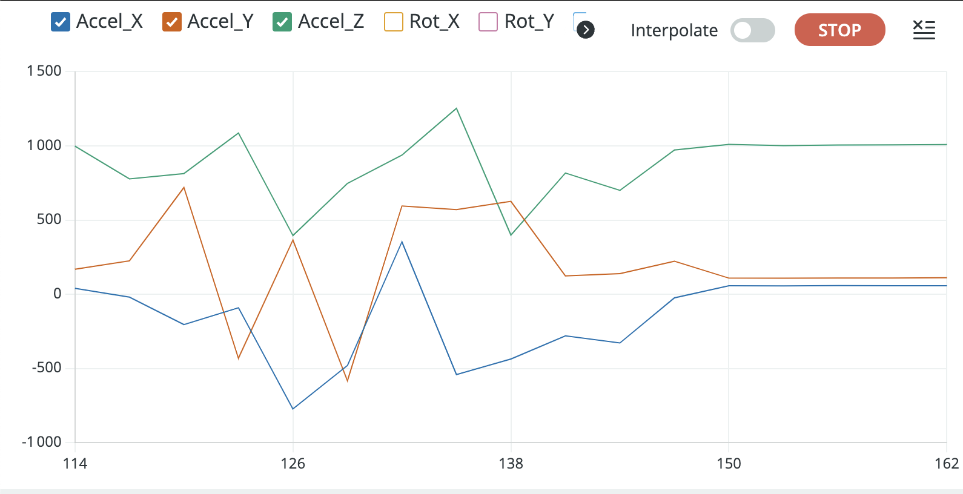
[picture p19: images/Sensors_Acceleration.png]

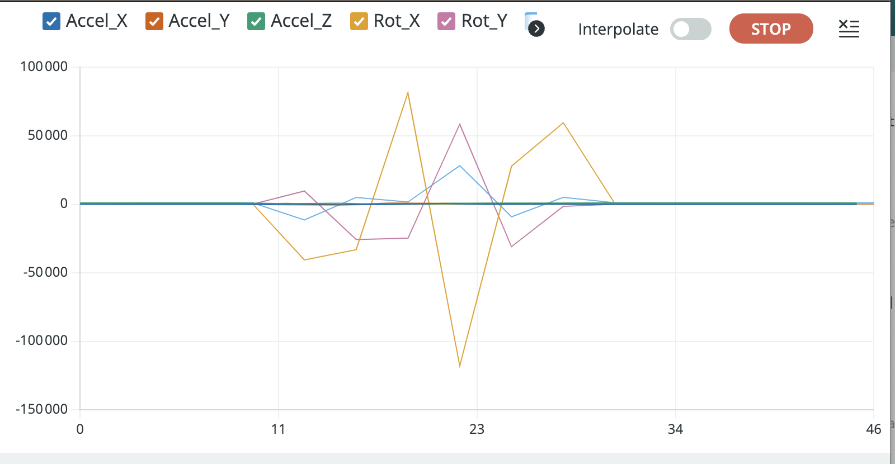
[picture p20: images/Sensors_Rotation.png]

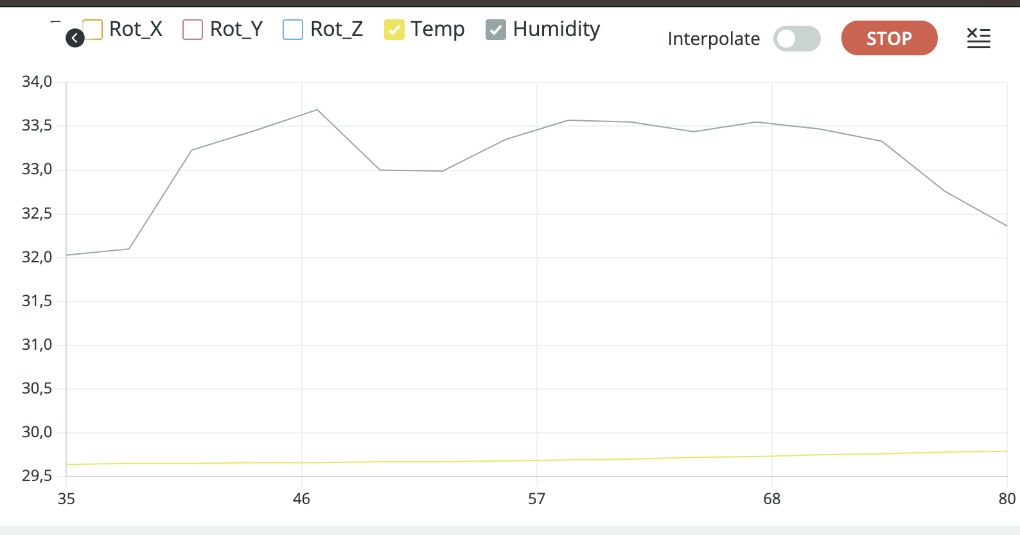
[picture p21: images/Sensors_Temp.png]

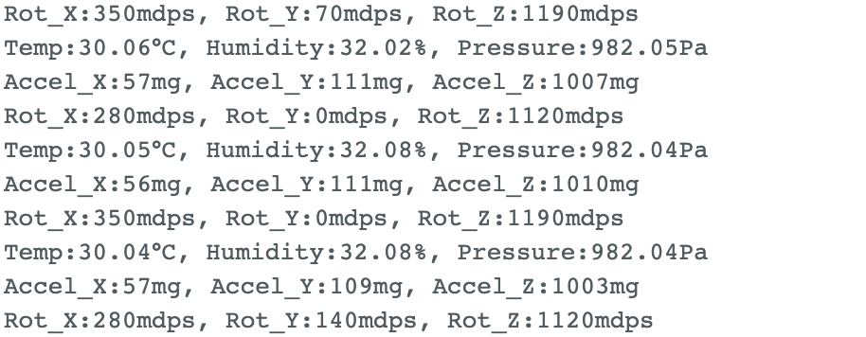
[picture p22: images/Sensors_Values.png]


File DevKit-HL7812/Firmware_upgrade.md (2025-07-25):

# IoT Continuum

This page is part of the [IoT Continuum Dev Kit](/)

<picture>
 <source media="(prefers-color-scheme: dark)" srcset="images/DevKit_face1-black.jpg">
 <source media="(prefers-color-scheme: light)" srcset="images/DevKit_face1-white.jpg">
 IoT Continuum Dev Kit
</picture>

# Firmware Upgrade

This section contains the firmware upgrade procedures for the various components of the development kit.
You may want to ensure your firmware is up to date before proceeding with the Getting Started instructions.

## Sierra Wireless HL7812 module

This devkit has been validated with the HL7812 firmware `5.4.12.1`.
The firmware can be downloaded from [Sierra Wireless Source website](https://source.sierrawireless.com/resources/airprime/software/hl781x-and-hl7845-firmware/hl781x-and-hl7845-firmware-5,-d-,4,-d-,12,-d-,1/#sthash.fwWxnRTe.adE3QaLa.dpbs)

Note: In the following steps we'll detail the procedure for Windows, but Sierra Wireless provides a way to do it on Linux too.

1. Click on "download" as shown below to download the file named `HL7812.5.4.12.1.exe`:

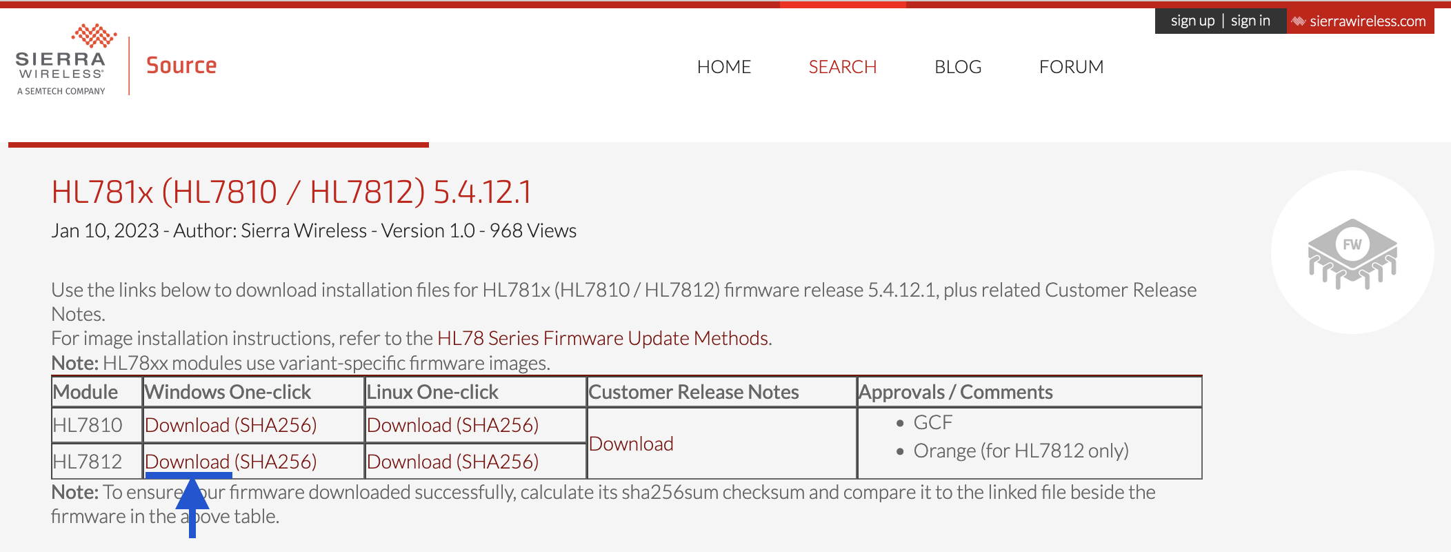
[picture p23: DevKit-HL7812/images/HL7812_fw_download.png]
firmware download website


2. Connect the devkit to your Windows PC using a USB data cable.

3. Open the Windows Device Manager, and look for the Silicon Labs CP210x USB to UART showing up in the "Port (COM & LPT)" section. If it does not show up, install the driver from [here](https://www.silabs.com/developers/usb-to-uart-bridge-vcp-drivers?tab=downloads) and try again.

4. Create a `HL78xx_download.ini` in `C:\Users\[...]\AppData\Roaming` directory with the following text (you may need to "display hidden files" in the explorer to see the `AppData` directory within the user directory) :
```
[Download]
Port=
ComBaud=115200
```
*Note*: the Port number must be the one showing up in Windows Device Manager at the previous step.

4. Launch `HL7812.5.4.12.1.exe` and wait for the execution to finish

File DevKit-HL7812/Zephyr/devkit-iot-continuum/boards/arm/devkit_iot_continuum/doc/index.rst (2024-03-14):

.. _devkit_iotcontinuum_board:

Orange Iot Continuum DevKit
###########################

Overview
********
If you want to develop your own IoT project, you will soon be able to do so with the help of our Continuum IoT development kit
that we are currently finalising. This kit is based on a STMicroelectronics STM32U585 microcontroller, a Sierra Wireless HL7812
connectivity module, a gyroscope, an accelerometer, a temperature sensor, a humidity sensor and a pressure sensor.

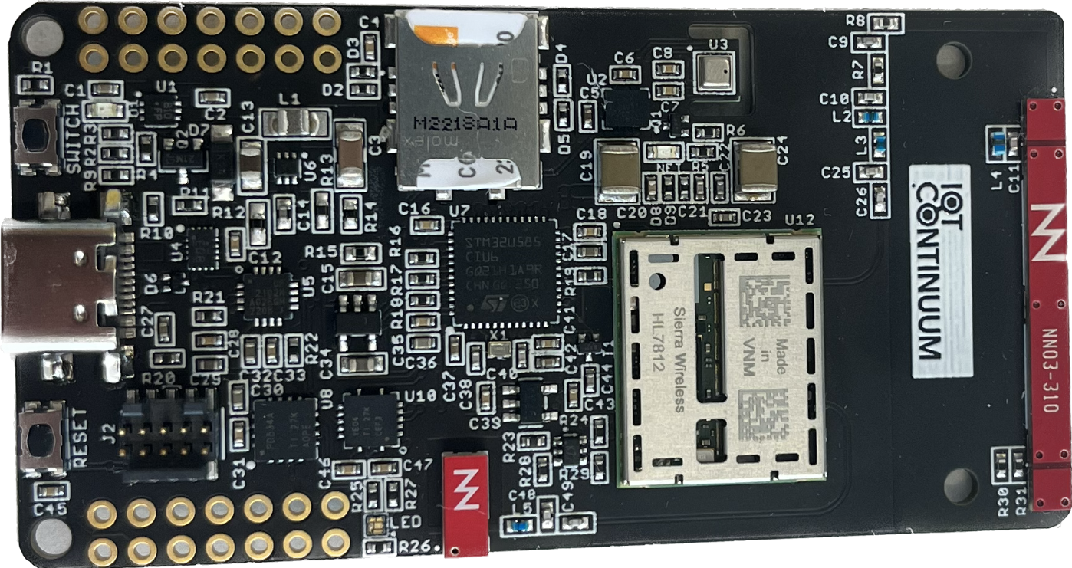
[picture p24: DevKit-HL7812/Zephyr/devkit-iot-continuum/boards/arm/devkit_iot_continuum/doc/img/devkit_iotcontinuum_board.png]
Continuum IoT development kit

   
More information about IoT Continuum can be found at the `IoT Continuum website`_.

Hardware
********
Iot Continuum DevKit provides the following hardware components:

- STM32U585 microcontroller in QFN48 package (2 Mbyte of flash and 786 Kbytes of RAM)
 
- Flexible board power supply:
 
  - USB VBUS or external battery source (3,7/4,2 V Li-Poly battery)
  - Power management access point
 
- A gpio expension device (PCA9534) with three user LEDs:

  - One red LED
  - One green LED
  - One blue LED

- SIM Card support

- One USB/UART Communication module (CP210)

- One UART switch which enable to switch between STM32U585 and HL7812 UART communication
 
- Wireless communication
 
  - LTE-M  (with Sierra HL7812 Modem)
  - GNSS   (with Sierra HL7812 Modem)
  - NB-IoT (with Sierra HL7812 Modem)
  
- Inertial measurement unit (IMU)
   
   - Acceleration (with LSM6DSO module)
   - Rotation (with LSM6DSO module)

- Environmental sensor measurement

   - Temperature (with BME280 module)
   - Pression (with BME280 module)
   - Humidity (with BME280 module)

- Two expension connectors with :

   - Free GPIO to use
   - One SPI free line
   - One COM free line

More information about STM32U585AI can be found here:

- `STM32U585 on www.st.com`_
- `STM32U585 reference manual`_

Supported Features
==================

The STM32U585 microcontroller of the board supports the following hardware features:

+-----------+------------+-------------------------------------+
| Interface | Controller | Driver/Component                    |
+===========+============+=====================================+
| NVIC      | on-chip    | nested vector interrupt controller  |
+-----------+------------+-------------------------------------+
| UART      | on-chip    | serial port-polling;                |
|           |            | serial port-interrupt               |
+-----------+------------+-------------------------------------+
| PINMUX    | on-chip    | pinmux                              |
+-----------+------------+-------------------------------------+
| GPIO      | on-chip    | gpio                                |
+-----------+------------+-------------------------------------+
| RNG       | on-chip    | True Random number generator        |
+-----------+------------+-------------------------------------+
| I2C       | on-chip    | i2c                                 |
+-----------+------------+-------------------------------------+
| SPI       | on-chip    | spi                                 |
+-----------+------------+-------------------------------------+
| DAC       | on-chip    | dac                                 |
+-----------+------------+-------------------------------------+
| ADC       | on-chip    | adc                                 |
+-----------+------------+-------------------------------------+
| WATCHDOG  | on-chip    | independent watchdog                |
+-----------+------------+-------------------------------------+
| USB       | on-chip    | usb_device                          |
+-----------+------------+-------------------------------------+
| BKP SRAM  | on-chip    | Backup SRAM                         |
+-----------+------------+-------------------------------------+
| PWM       | on-chip    | pwm                                 |
| die-temp  | on-chip    | die temperature sensor              |
+-----------+------------+-------------------------------------+
| AES       | on-chip    | crypto                              |
+-----------+------------+-------------------------------------+

The default configuration can be found in the defconfig file:
``boards/arm/devkit_iot_continuum/devkit_iot_continuum_defconfig``

Connections and IOs
===================

DevKit IOT C ontinuum board has 3 GPIO controllers (from A to C). These controllers are responsible for pin muxing, input/output, pull-up, etc.

Each of the GPIO pins can be configured by software as output (push-pull or open-drain), as
input (with or without pull-up or pull-down), or as peripheral alternate function. Most of the
GPIO pins are shared with digital or analog alternate functions. All GPIOs are high current
capable except for analog inputs.

Peripheral Mapping:
----------------------------------

- UART_1 (MODULE) TX/RX   : PA9/PA10 (UART between STM32U585 and HL7812)
- UART_3 (USB_UART) TX/RX : PA7/PA5 
- I2C1 SCL/SDA            : PB6/PB7 
- SPI1 SCK/MISO/MOSI      : PB3/PB4/PB5
- GPIO (SwitchCom)        : PB8 (Enable to switch USB UART output between STM32U585 UART and HL7812 UART)

Serial Port

DevKit IOT Continuum has 2 U(S)ARTs. The Zephyr console output is assigned to USART3. Default settings are 115200 8N1.

For mode details please refer to `STM32 Nucleo-64 board User Manual`_.

Programming and Debugging
*************************

Applications for the ``devkit_iot_continuum`` board configuration can be built and
flashed in the usual way.

Hello world zephyr application example can be build this way:

.. code-block:: bash

   $ west build -b devkit_iot_continuum ../zephyr/samples/hello_world -p 

And for the blinky example:

   .. code-block:: bash

   $ west build -b devkit_iot_continuum ../zephyr/samples/basic/blinky -p 

Flashing
========

Flashing an application to DevKit IOT Continuum board
-----------------------------------------------------

Board is configured to be flashed using west STM32CubeProgrammer runner. Installation of STM32CubeProgrammer is then required to flash the board.

Alternatively, openocd (provided in Zephyr SDK), JLink and pyocd can also be
used to flash and debug the board if west is told to use it as runner,
using ``-r openocd``

Here is an example for the blinky sample zephyr application.

   .. code-block:: bash

   $ west build -b devkit_iot_continuum ../zephyr/samples/basic/blinky -p
   $ west flash 

You will see the LED blinking every second.

Debugging
=========

Default flasher for this board is openocd. It could be used in the usual way (see zephyr documentation)

References
**********

.. target-notes::

.. _IoT Continuum website:
   https://iotjourney.orange.com/en/iotcontinuum

.. _STM32U585 on www.st.com:
   https://www.st.com/en/microcontrollers-microprocessors/stm32u575-585.html

.. _STM32U585 reference manual:
   https://www.st.com/resource/en/reference_manual/rm0456-stm32u575585-armbased-32bit-mcus-stmicroelectronics.pdf

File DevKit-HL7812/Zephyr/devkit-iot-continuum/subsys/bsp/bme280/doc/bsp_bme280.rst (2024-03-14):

.. _iot_continuum_bsp_bme280:

BSP BME280
##########

Overview
========

The **[BSP_BME280]** item provides a simple way to use BME280 module.

API Documentation
=================

.. doxygenfile:: inc/bsp_bme280.h
   :project: orange_iot

The **[BSP_BME280]** goal is to control the BME280 sensor.

It allows to:

* Initialize BME280 module

   It initializes the BME280 sensors.
   It is mandatory to use the API and need to be call first.

   .. code-block:: c

      void BSP_BME280_Init(void)

* Get temperature values (in 0.1 degC) from the BME280 module

   .. code-block:: c

      void BSP_BME280_GetTemperature(int32_t *o_pi32_Temperature_degC)

* Get pression value (in mBar or hPa) from BME280 module

   .. code-block:: c

      void BSP_BME280_GetPression(int32_t *o_pi32_Pression_mBar)

* Get humidity value (percentage) from BME280 module

   .. code-block:: c

      void BSP_BME280_GetHumidity(int32_t *o_pi32_Humidity)

* Deinitialize BME280 module

   .. code-block:: c

      void BSP_BME280_Deinit(void)

You can also remove debug log by setting ``CONFIG_BSP_BME280_LOG_LEVEL_DBG=n``

Shell commands
==============

Activate ``CONFIG_BSP_BME280_SHELL`` to enable the bsp_bme280_shell which proposes the following commands:

* help

   Shows all possible commands.

   Usage: bsp_bme280 help

   Example:

   .. code-block:: bash

      uart:~$ bsp_bme280 help
      bsp_bme280 - bsp_bme280 commands
      Subcommands:
      init              :Initialize BME280 module

      get_temperature  :Get temperature value (in 0.1degC) from BME280 module

      deinit            :Deinitialize BME280 module
      uart:~$

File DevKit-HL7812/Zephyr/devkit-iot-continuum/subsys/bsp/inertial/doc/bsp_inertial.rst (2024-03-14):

.. _devkit_iot_continuum_bsp_inertial:

BSP Inertial
############

Overview
========

The **[BSP_INERTIAL]** item provides a simple way to use LSM6DSO inertial module.

API Documentation
=================

.. doxygenfile:: inc/bsp_inertial.h
   :project: devkit_iot_continuum

The **[BSP_INERTIAL]** goal is to control the LSM6DSO inertial sensor.

It allows to:

* Initialize LSM6DSO inertial module

   It initializes the LSM6DSO inertial sensor.
   It is mandatory to use the API and need to be call first.

   .. code-block:: c

      BSP_ret_e BSP_INERTIAL_Init(void);

* Get acceleration values (in mm/s^2)  on the 3 axis from the LSM6DSO inertial module

   .. code-block:: c

      BSP_ret_e BSP_INERTIAL_GetAcceleration(int32_t *o_pi32_X, int32_t *o_pi32_Y, int32_t *o_pi32_Z)

* Get rotation values (in mrad/s) on the 3 axis from the LSM6DSO inertial module

   .. code-block:: c

      BSP_ret_e BSP_INERTIAL_GetGyroscope(int32_t *o_pi32_X, int32_t *o_pi32_Y, int32_t *o_pi32_Z)

* Deinitialize LSM6DSO inertial module

   .. code-block:: c

      BSP_ret_e BSP_INERTIAL_Deinit(void);

You can also remove debug log by setting ``CONFIG_BSP_INERTIAL_LOG_LEVEL_DBG=n``

Shell commands
==============

Activate ``CONFIG_BSP_INERTIAL_SHELL`` to enable the bsp_inertial_shell which proposes the following commands:

* help

   Shows all possible commands.

   Usage: bsp_inertial help

   Example:

   .. code-block:: bash

      uart:~$ bsp_inertial help
      bsp_inertial - bsp_inertial commands
      Subcommands:
      init              :Initialize LSM6DSO inertial module

      get_acceleration  :Get acceleration values (in mm/s^2) from the accelerometer
                           of LSM6DSO

      get_gyroscope     :Get rotation values (in mrad/s) from the gyroscope of
                           LSM6DSO

      deinit            :Deinitialize LSM6DSO inertial module
      uart:~$

* init

   Example:

   .. code-block:: bash

      uart:~$ bsp_inertial init
      SUCCESS: Inertial module LSM6DSO Init
      uart:~$

* get_acceleration

   Example:

   .. code-block:: bash

      uart:~$ bsp_inertial  get_acceleration
      SUCCESS: Acceleration: X = -7554 mm/s^2, Y = 1170 mm/s^2, Z = 6433 mm/s^2
      uart:~$

* get_gyroscope

   Example:

   .. code-block:: bash

      uart:~$ bsp_inertial  get_gyroscope
      SUCCESS: Rotation: X = 15 mrad/s^2, Y = 7 mrad/s^2, Z = -12 mrad/s^2
      uart:~$

* deinit

   Example:

   .. code-block:: bash

      uart:~$ bsp_inertial deinit
      SUCCESS: Inertial module LSM6DSO Deinit
      uart:~$

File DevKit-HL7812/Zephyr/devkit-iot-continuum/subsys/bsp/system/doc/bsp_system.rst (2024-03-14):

.. _devkit_iot_continuum_bsp_system:

BSP System
##########

Overview
========

The **[BSP_SYSTEM]** item provides a simple way to propose system services.

API Documentation
=================

.. doxygenfile:: inc/bsp_system.h
   :project: devkit_iot_continuum

The **[BSP_SYSTEM]** goal is to control the system (get uptime or reboot the system).

It allows to:

* Get uptime in seconds

   .. code-block:: c

      BSP_Ret_e BSP_SYSTEM_GetUptimeMSec(void);

* Get uptime in milliseconds

   .. code-block:: c

      BSP_Ret_e BSP_SYSTEM_GetUptimeMs(void);

* Reboot system, do software reset

   .. code-block:: c

      BSP_Ret_e BSP_SYSTEM_Reboot();

You can also remove debug log by setting ``CONFIG_BSP_SYSTEM_LOG_LEVEL_DBG=n``

Shell commands
==============

Activate ``CONFIG_BSP_SYSTEM_SHELL`` to enable the bsp_system_shell which proposes following commands:

* help

   Shows all possible commands

   Usage: bsp_system help

   Example:

   .. code-block:: bash

      uart:~$ bsp_system help
      bsp_system - bsp_system commands
      Subcommands:
      uptime_sec  :Get Uptime in seconds

      uptime_ms   :Get Uptime in milliseconds

      reboot      :Do a software reset
                   bsp_system reboot <delay_ms>
      uart:~$

* uptime_sec

   Example:

   .. code-block:: bash

      uart:~$ bsp_system uptime_sec
      SUCCESS: uptime = 161 sec
      uart:~$

* uptime_ms

   Example:

   .. code-block:: bash

      uart:~$ bsp_system uptime_ms
      SUCCESS: uptime = 186557 ms
      uart:~$

* reboot

   Example:

   .. code-block:: bash

      uart:~$ bsp_system reboot 100
      Do a software reset in 100 ms
      *** Booting Zephyr OS build zephyr-v3.2.0-67-g95d7afeb1bbd  ***

Each command returns ``SUCCESS`` in case of a success or ``FAILED`` in case of a failure.

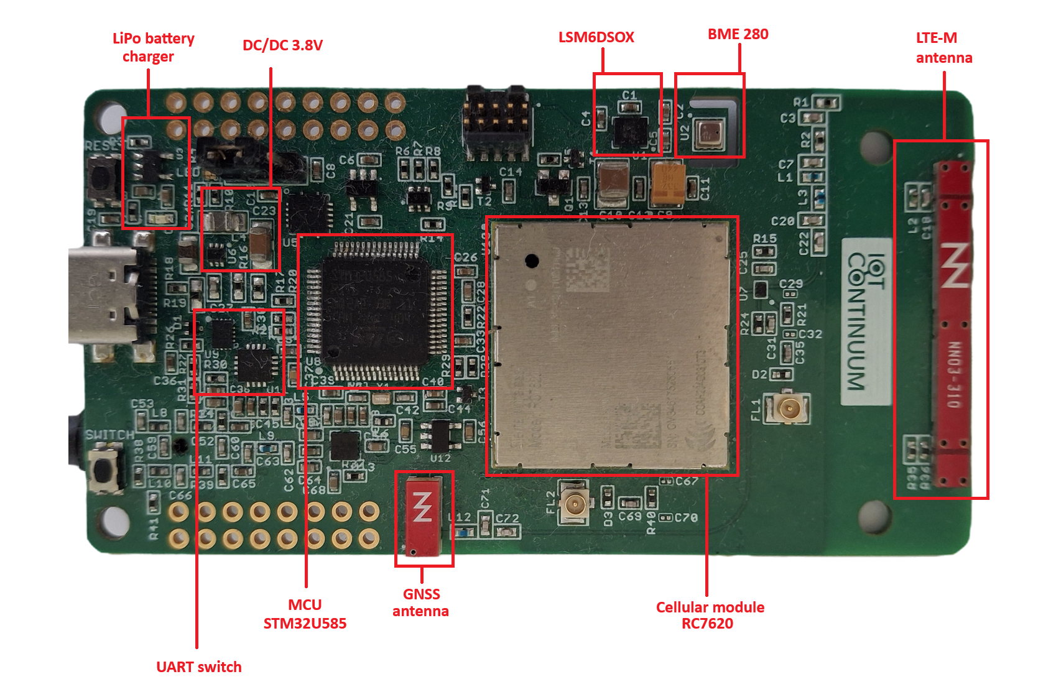
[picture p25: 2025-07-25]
DevKit-RC7620/images/card-legend-black.png

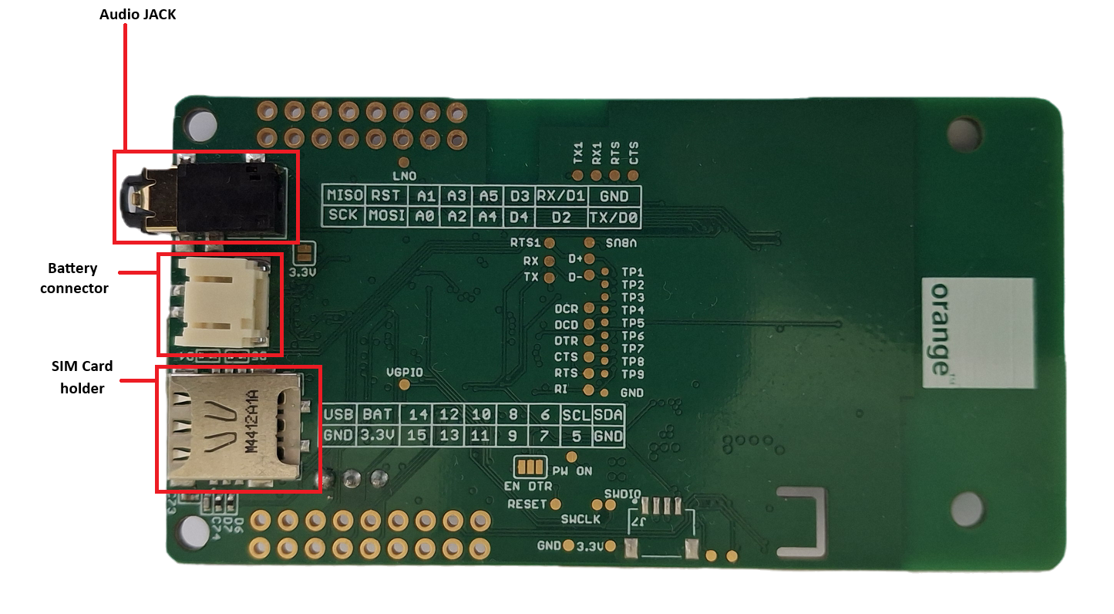
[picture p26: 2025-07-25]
DevKit-RC7620/images/card-legend-bottom-white.png

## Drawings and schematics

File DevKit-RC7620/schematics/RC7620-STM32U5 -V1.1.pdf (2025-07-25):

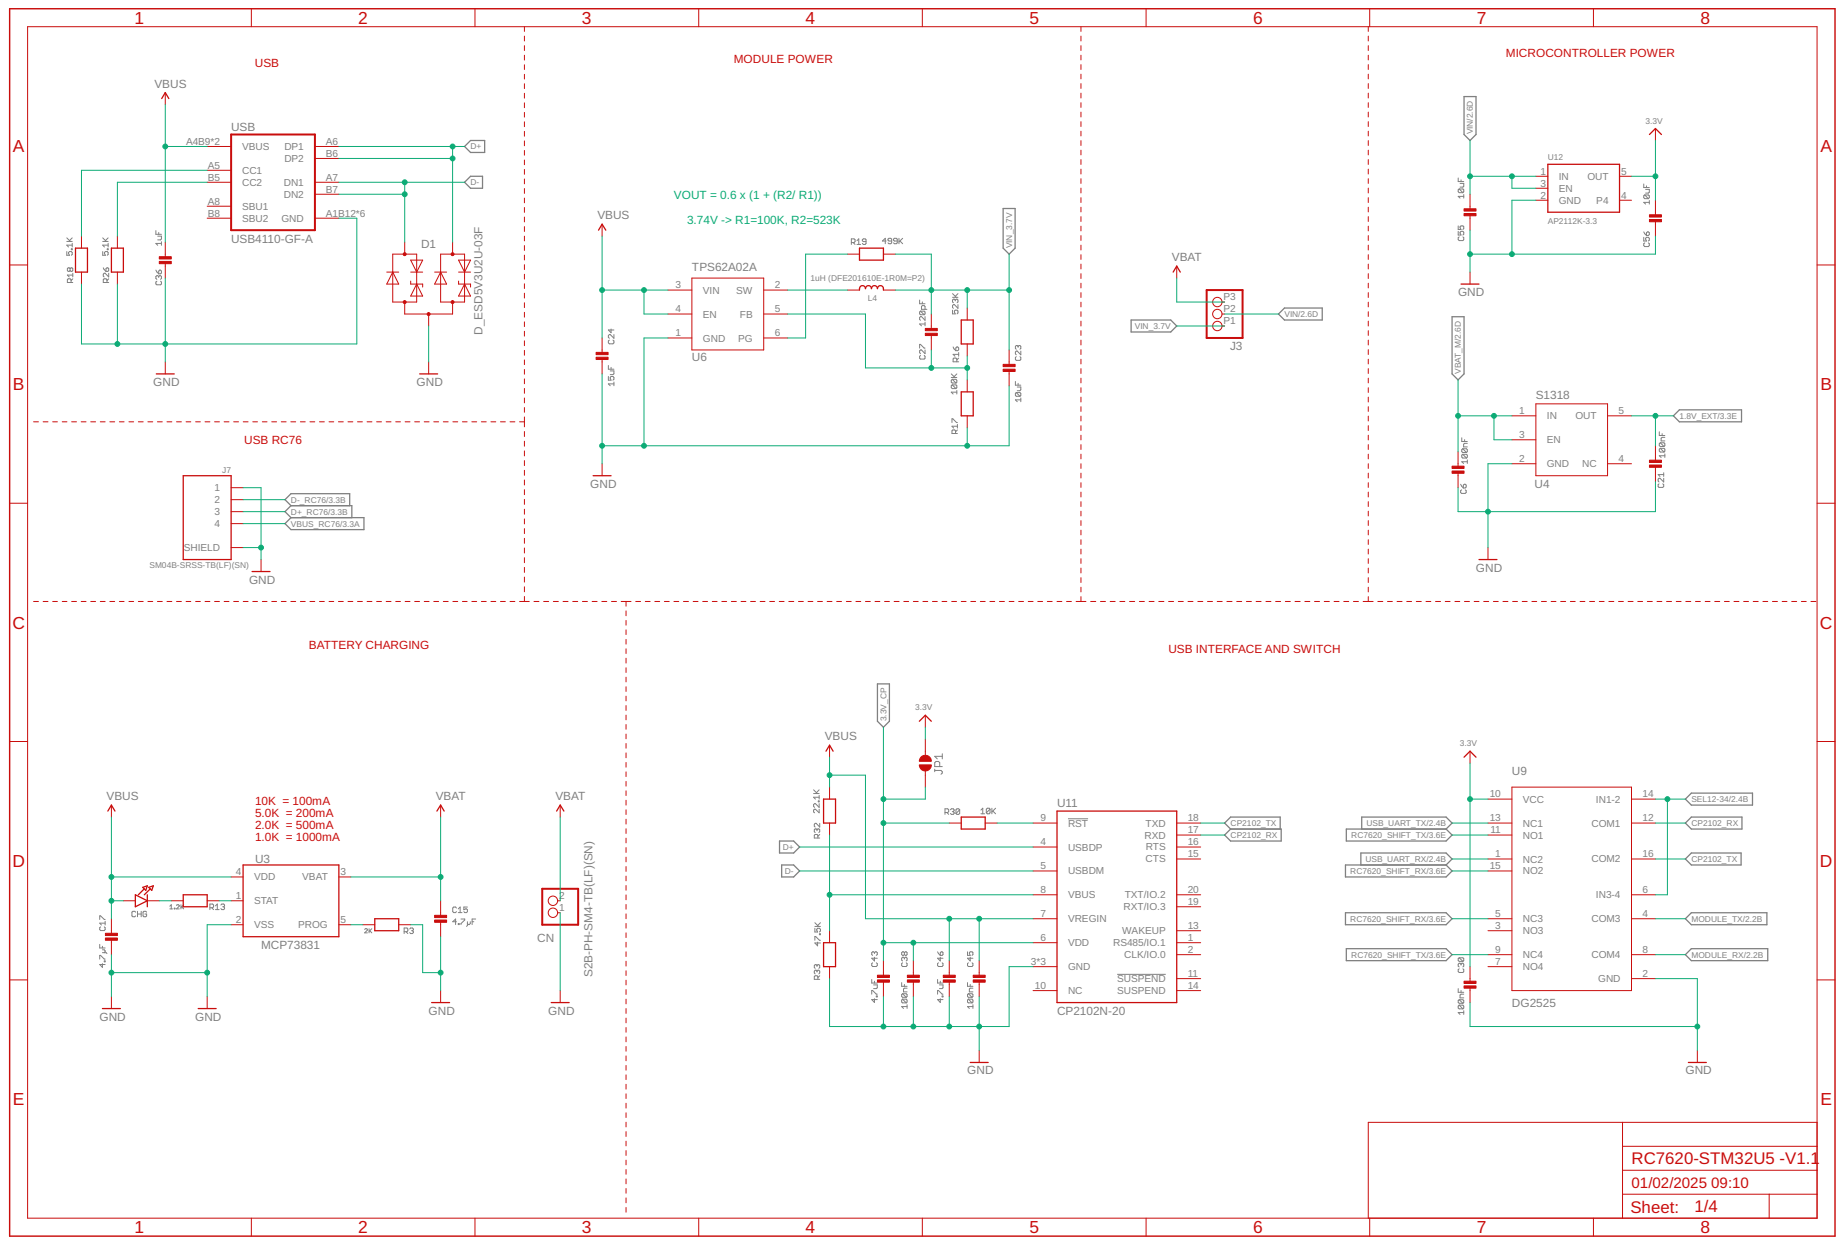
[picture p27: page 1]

SM04B-SRSS-TB(LF)(SN)

USB INTERFACE AND SWITCH

S2B-PH-SM4-TB(LF)(SN) GND

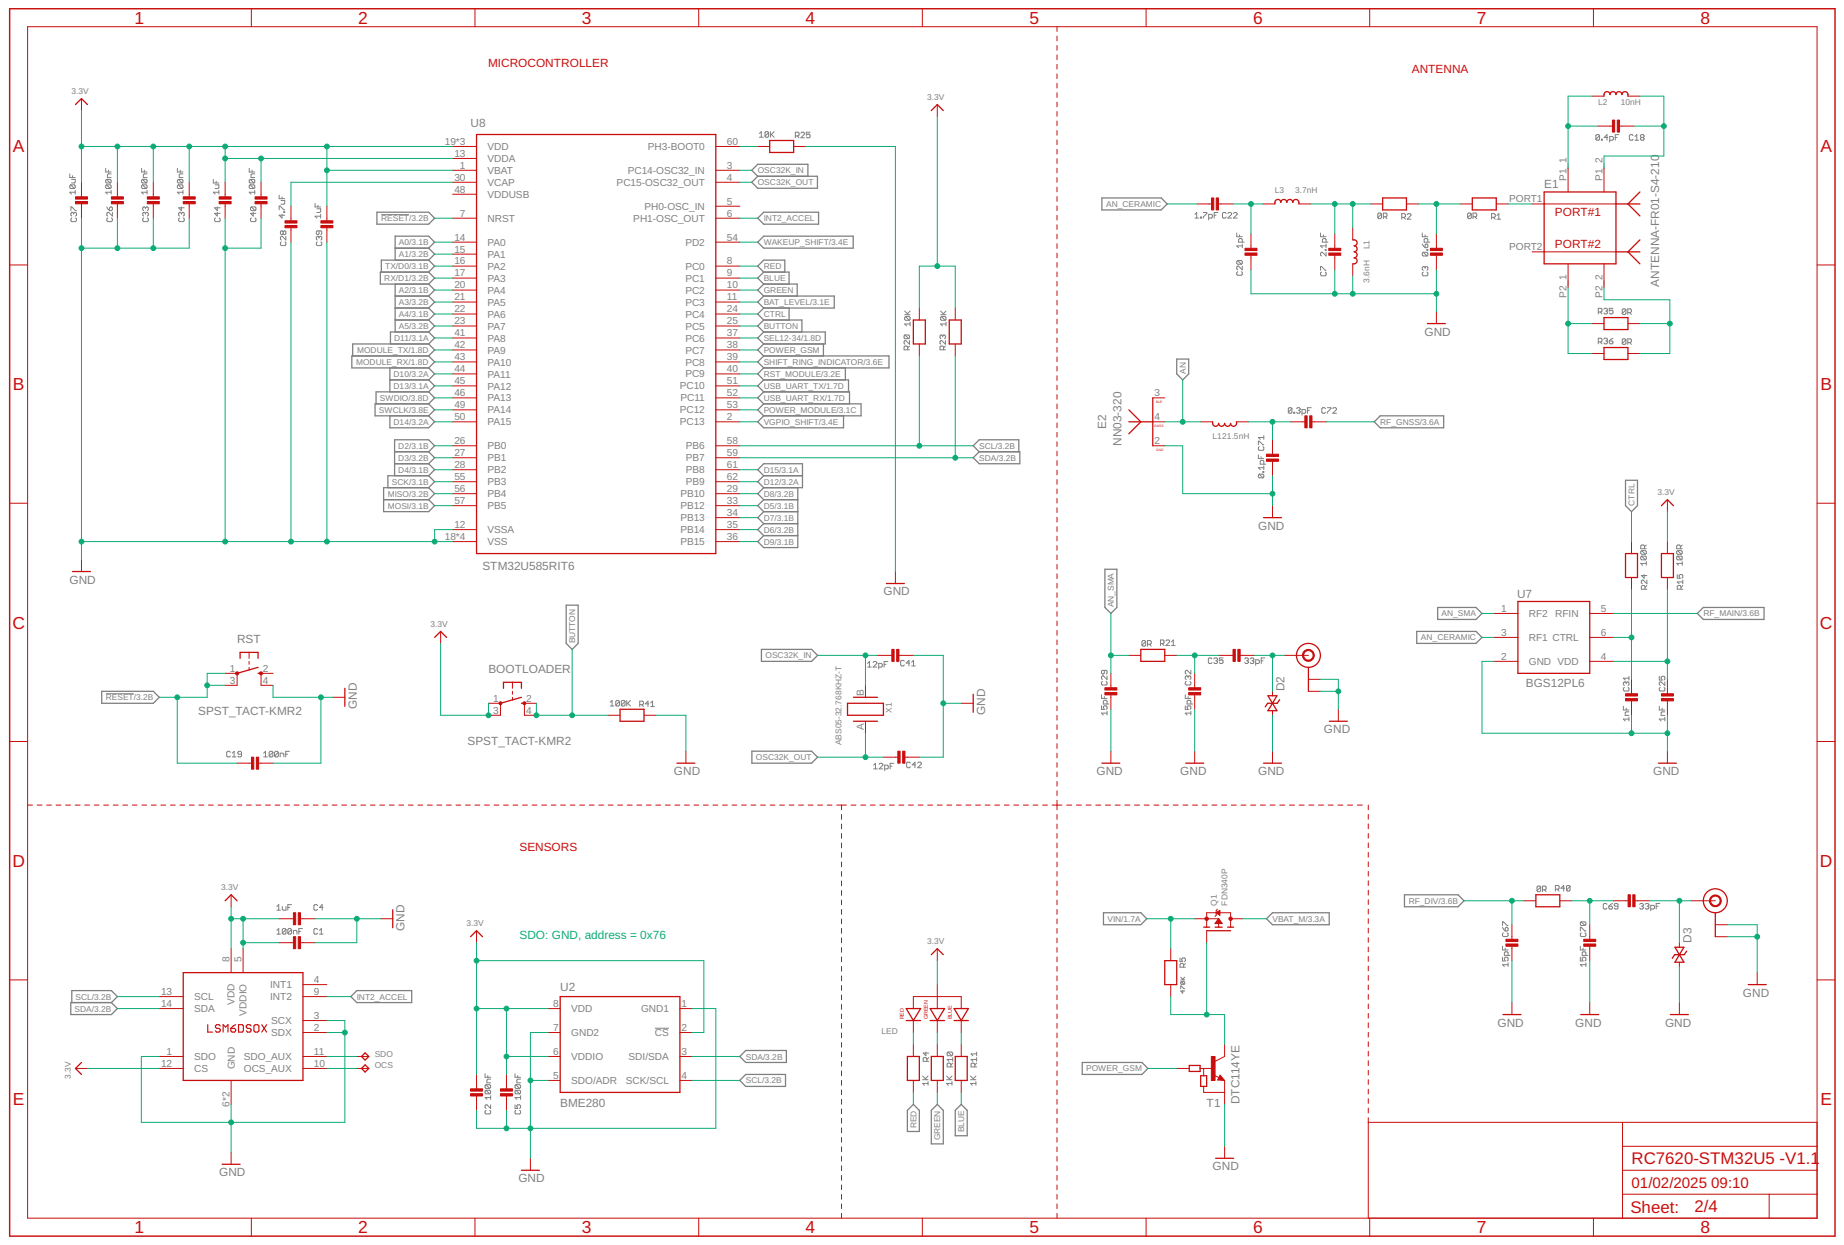
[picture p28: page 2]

13 | 3 PC15-OSC32_OUT
1 | OSC32K_IN
48 | | 4 PH0-OSC_IN 5 PH1-OSC_OUT

RESET/3.2B | | INT2_ACCEL

SWCLK/3.8E 49 | 53 PC11 POWER_MODULE/3.1C

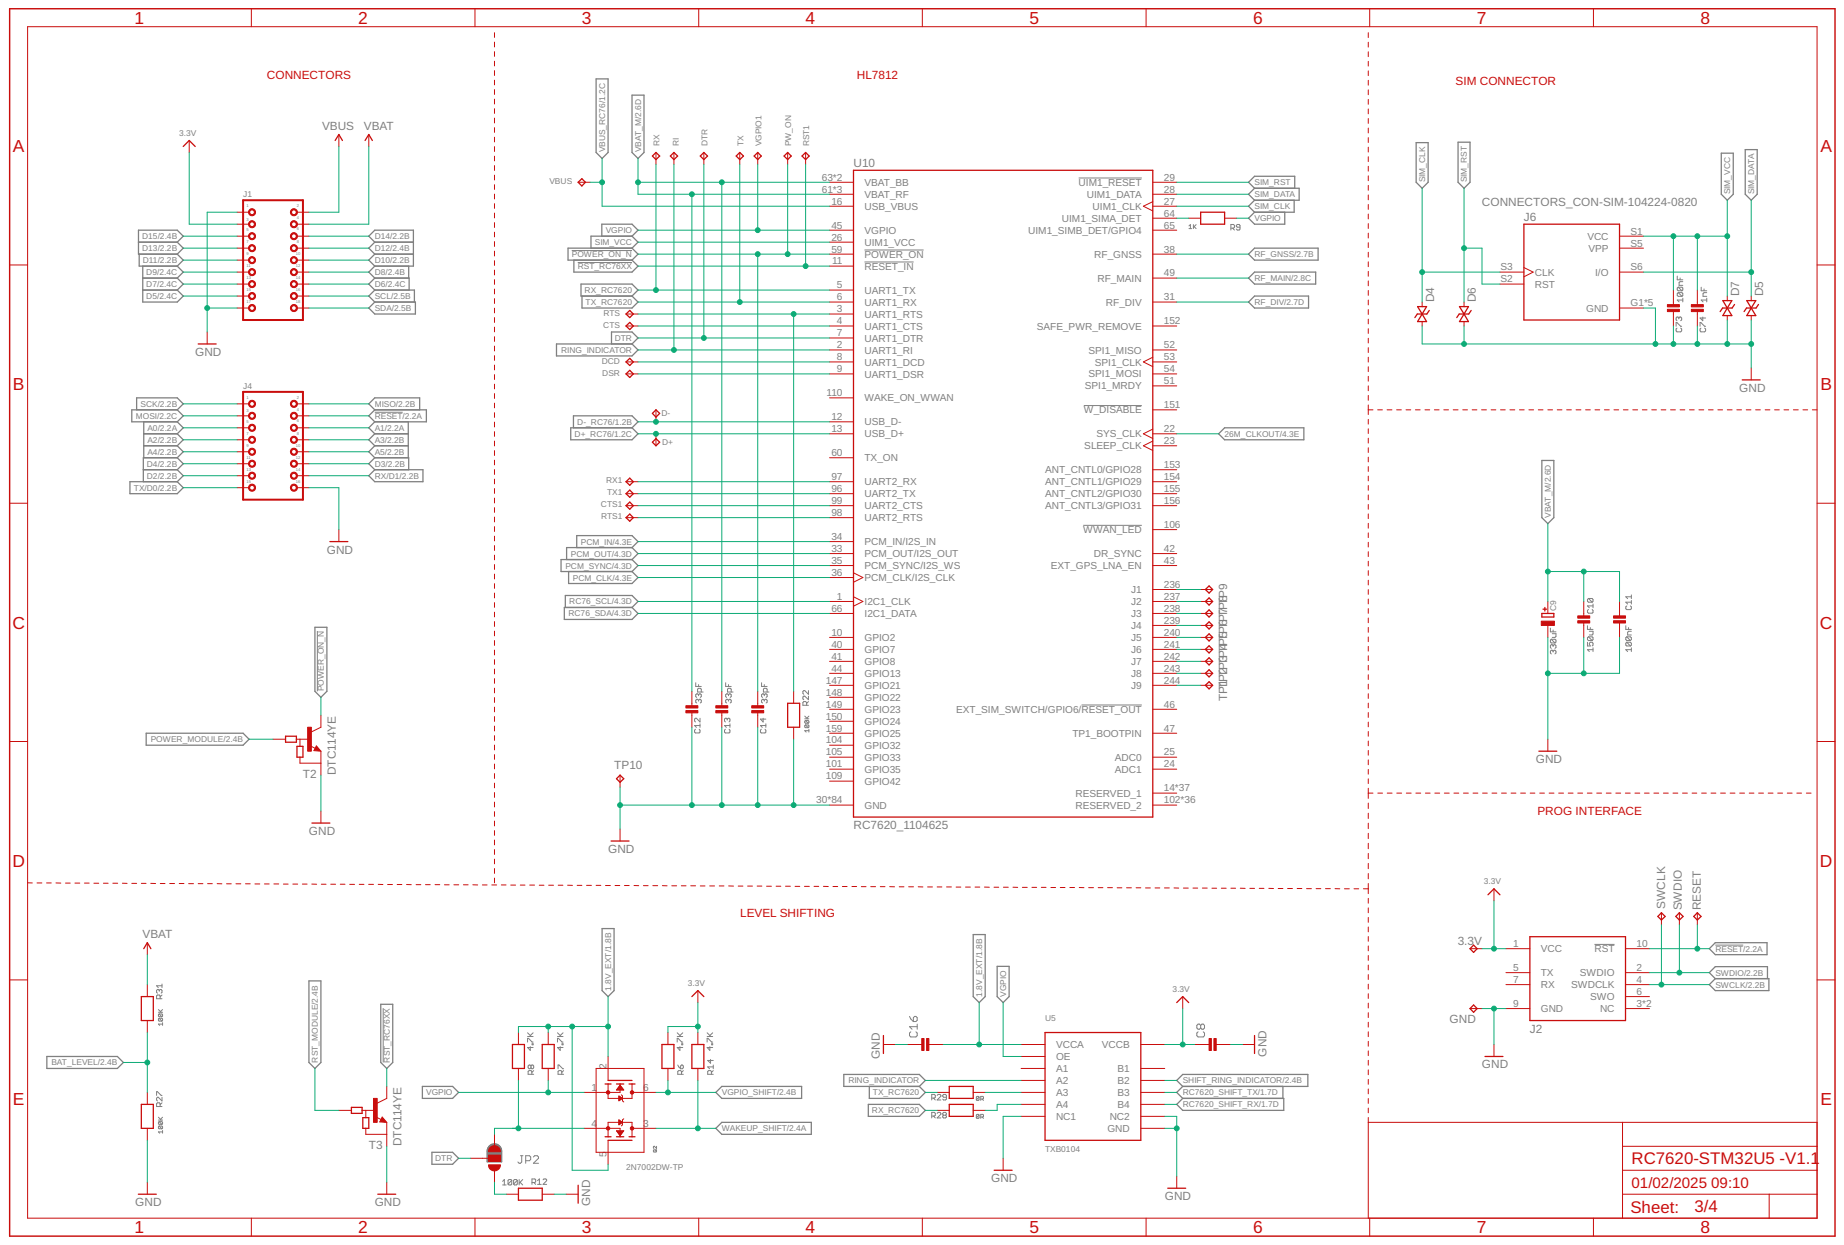
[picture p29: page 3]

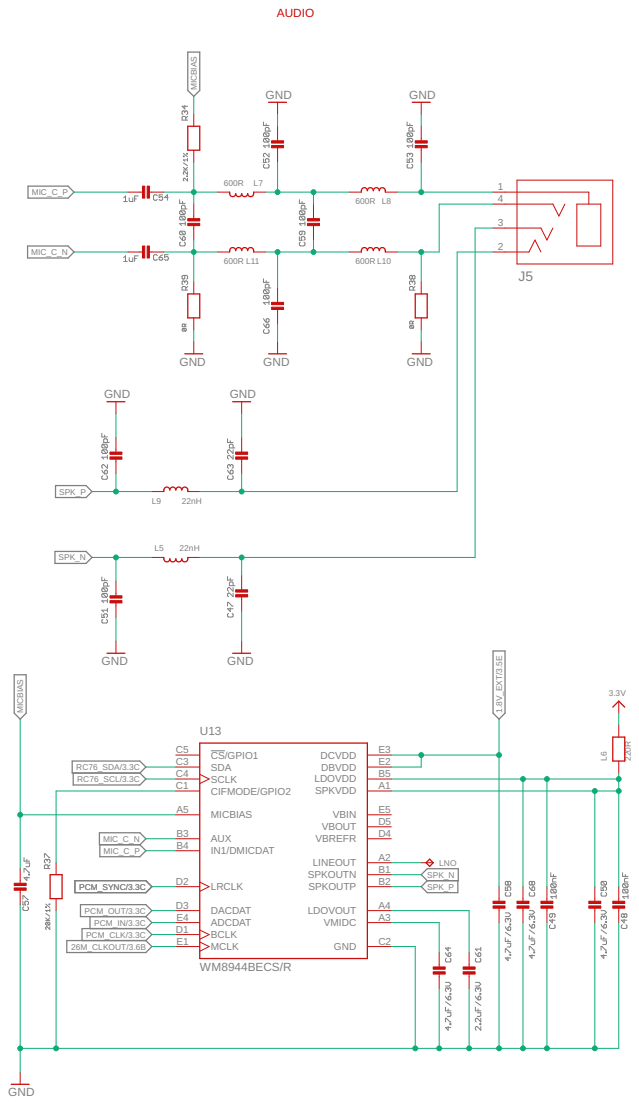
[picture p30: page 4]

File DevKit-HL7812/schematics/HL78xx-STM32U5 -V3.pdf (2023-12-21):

A

A

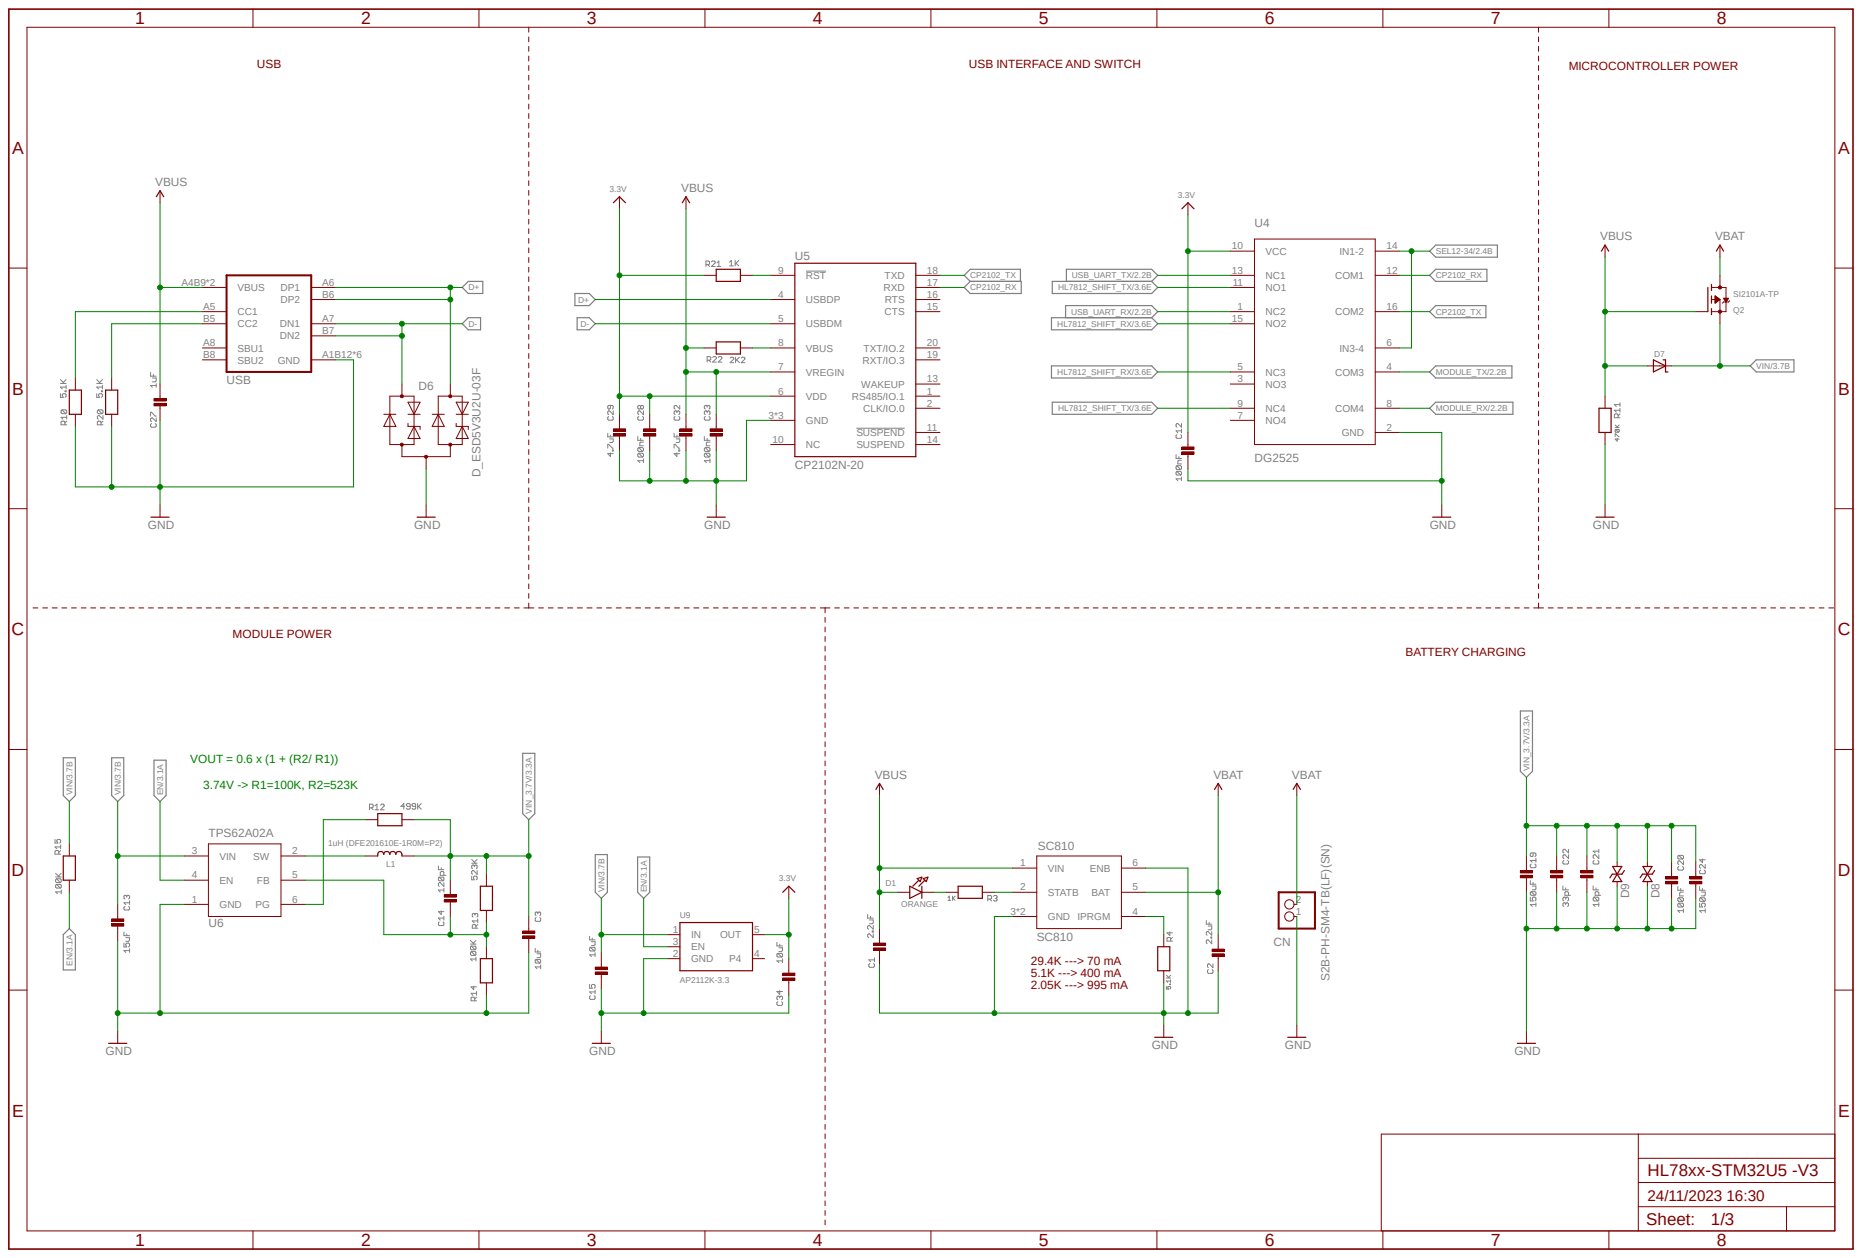
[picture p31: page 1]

A

A

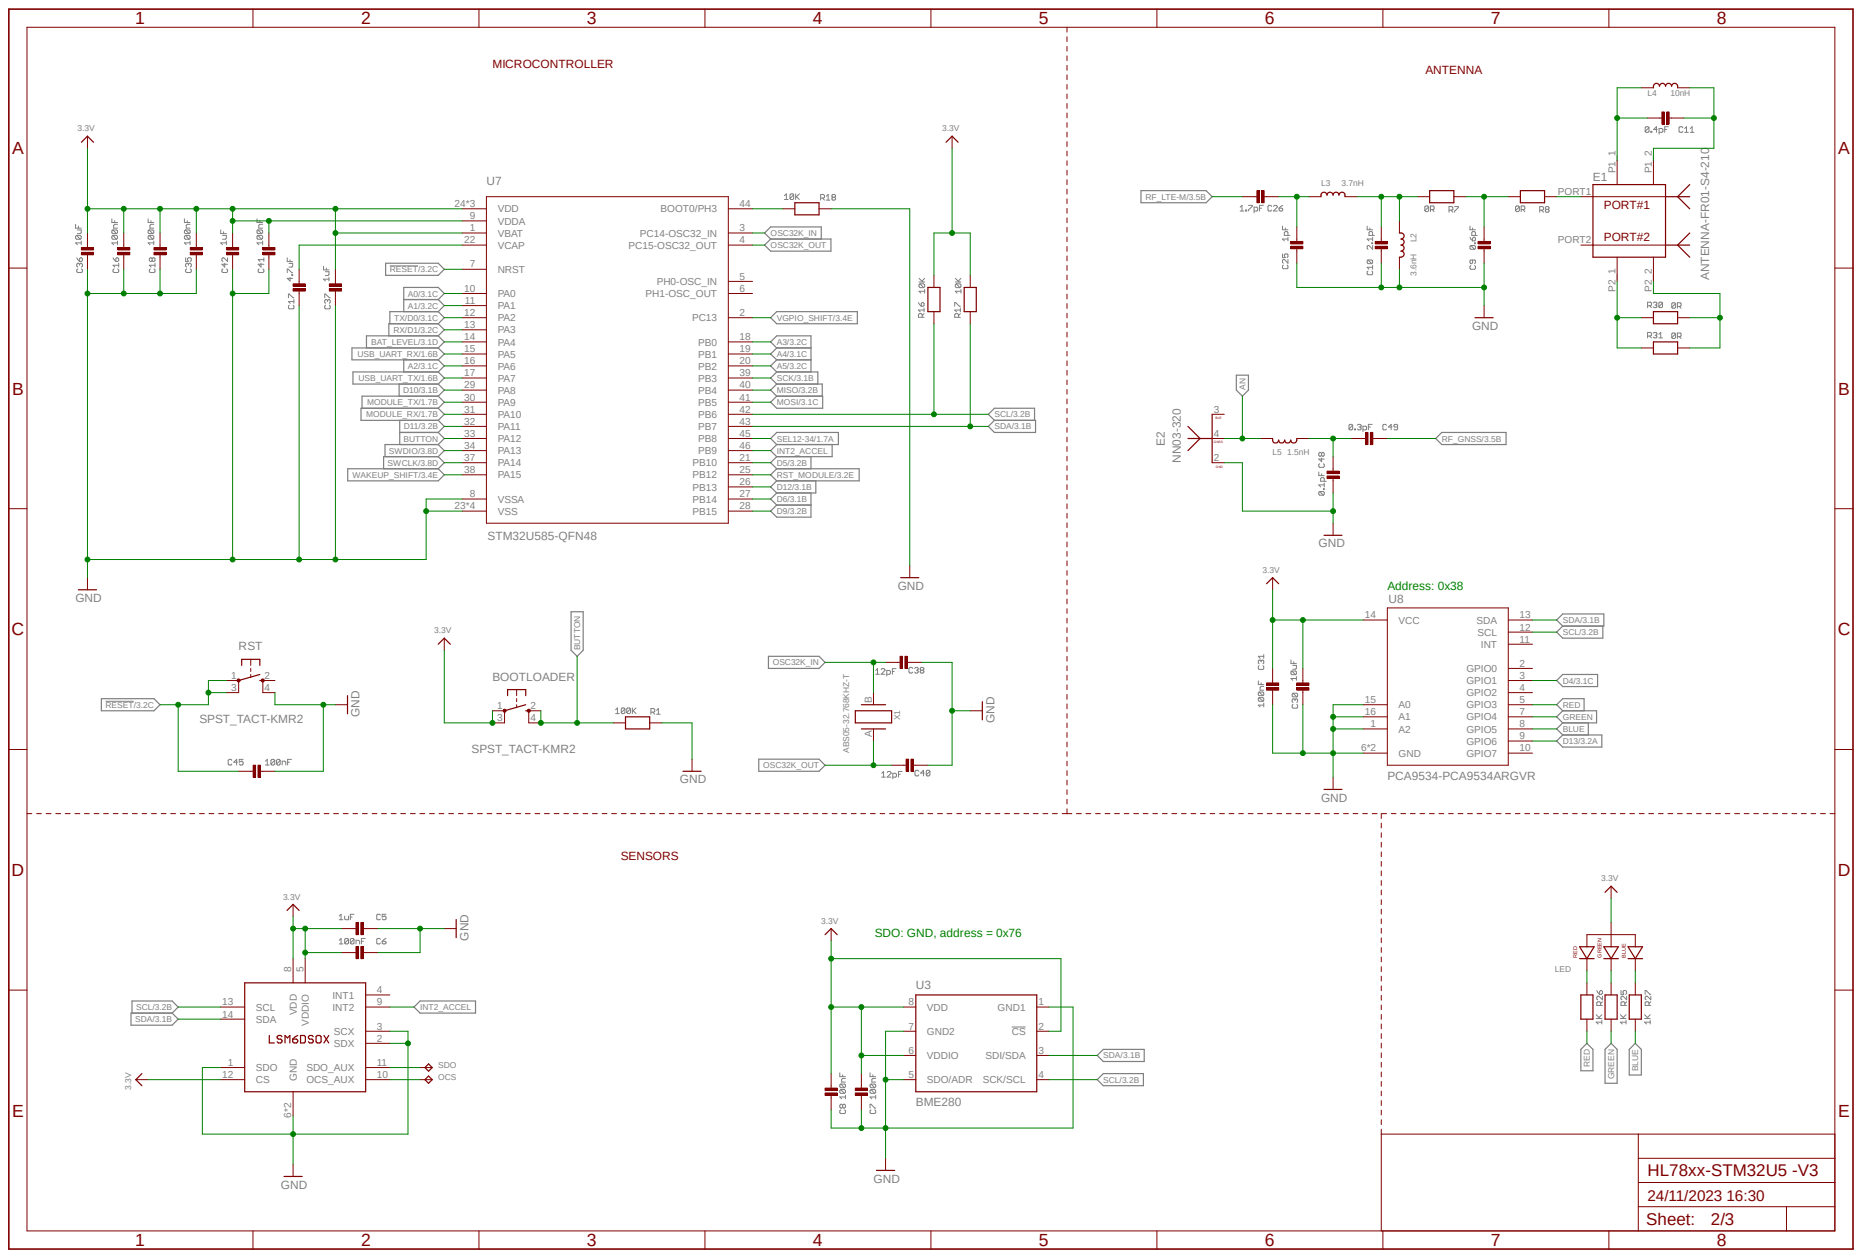
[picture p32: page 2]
STM32U585-QFN48; SPST_TACT-KMR2; GND; ABS⁰⁵⁻³².768KHZ⁻T; GND GND; GND 3.3V; PCA9534-PCA9534ARGVR; 3.3V NN⁰³⁻³²⁰; 1.5nH GND; ANTENNA⁻FR⁰¹⁻S⁴⁻²¹⁰; GND ³.6nH; 3.3V GND; GND 6*2; INT1; INT2; 9 OCS_AUX; 10 SCL 13; SCX; 3 SDA 14; SDO 1; SDO_AUX; 11 SDX; 2 VDD; 8 VDDIO; PC14-OSC32_IN; 3 PC15-OSC32_OUT; 4 VBAT 1; 43 NRST 7; VDDA 9; VDD 24*3; BOOT0/PH3; 44 PH1-OSC_OUT; 6 PH0-OSC_IN; 2 VSS 23*4; VSSA 8; VCAP 22; 3 4 RST; 4 BOOTLOADER; SDO OCS; GPIO0; 2 GPIO1; 3 GPIO2; 4 GPIO3; 5 GPIO4; 7 GPIO5; 8 GPIO6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

SDO: GND, address = 0x76

USB_VBUS C16 | RESET_IN_N C11 | GND CG1*20

A

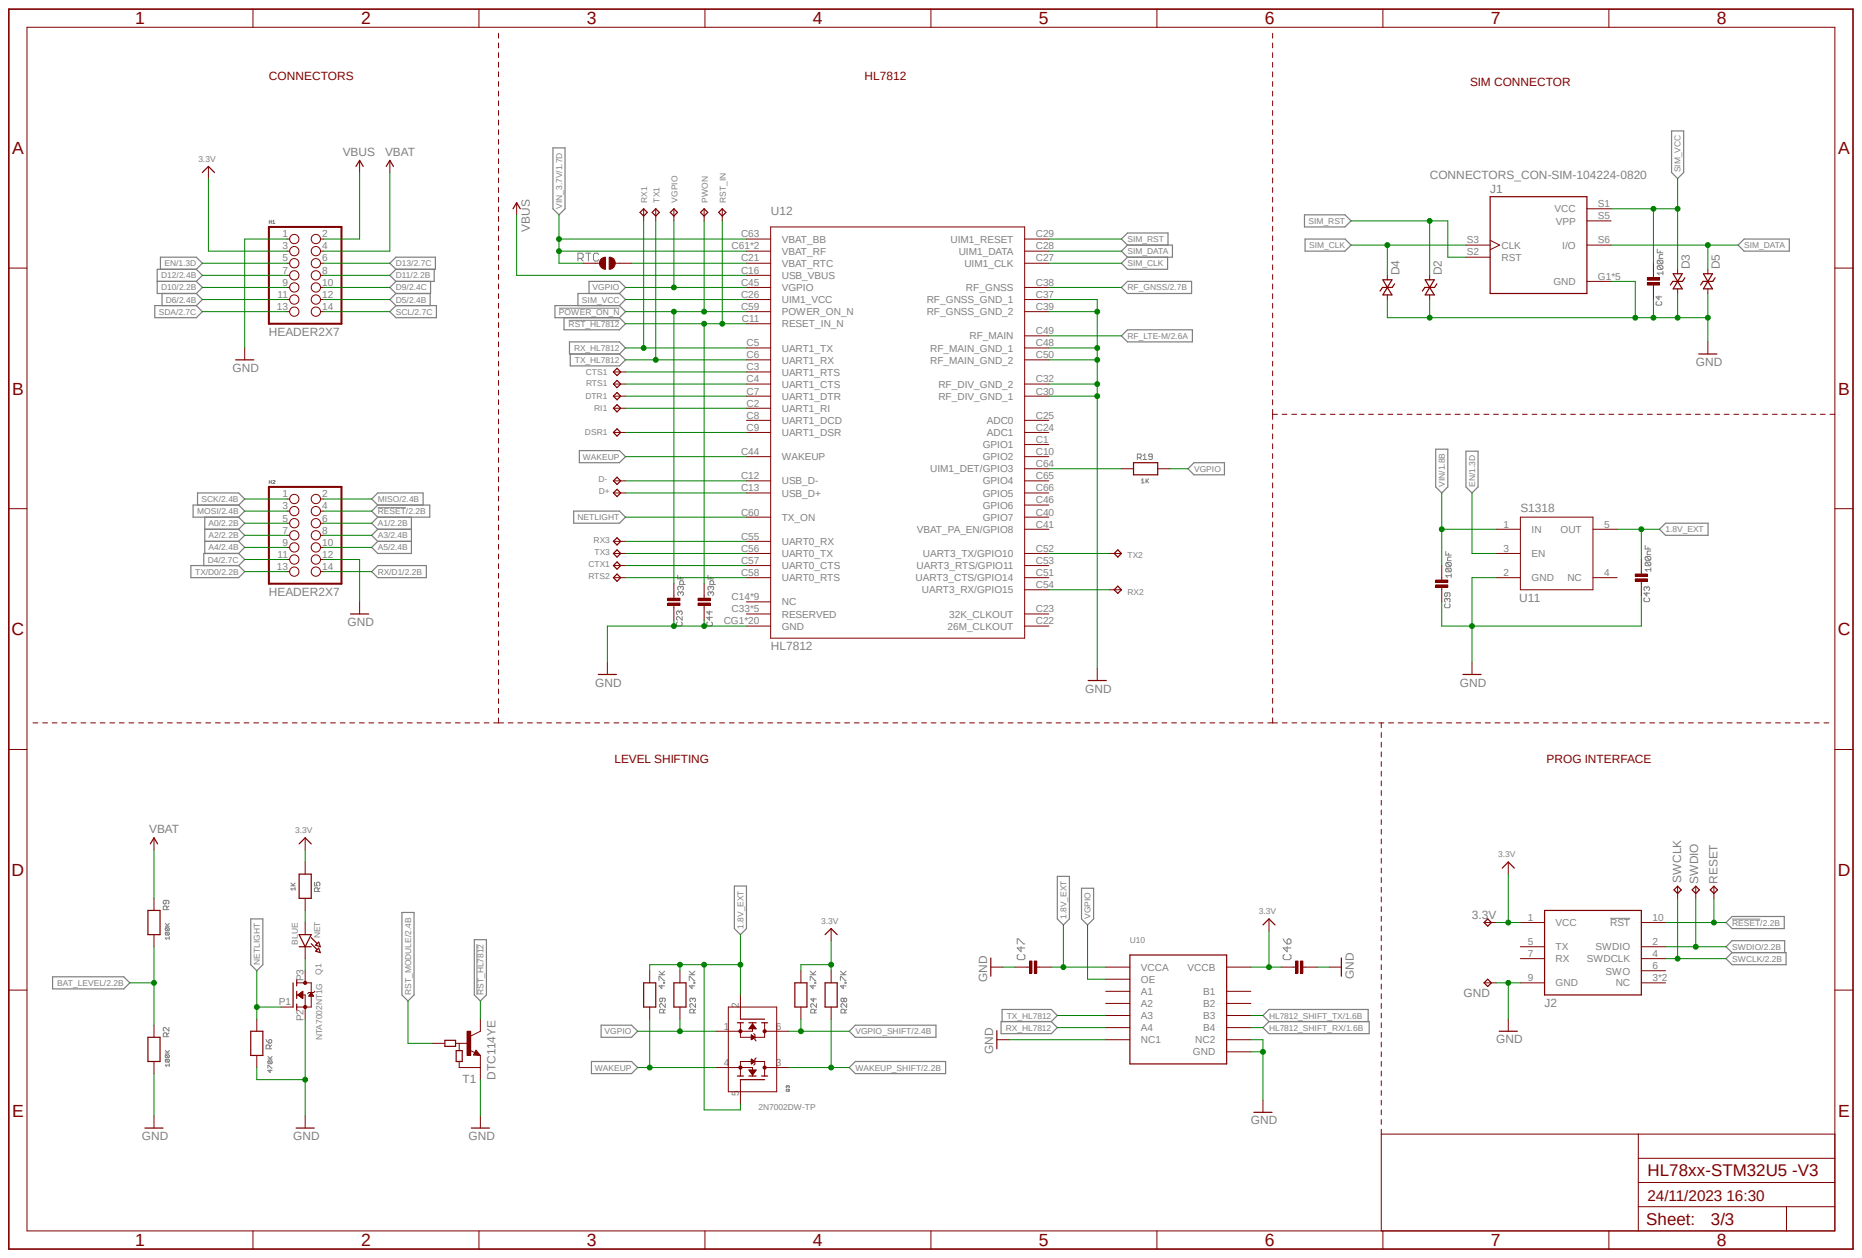
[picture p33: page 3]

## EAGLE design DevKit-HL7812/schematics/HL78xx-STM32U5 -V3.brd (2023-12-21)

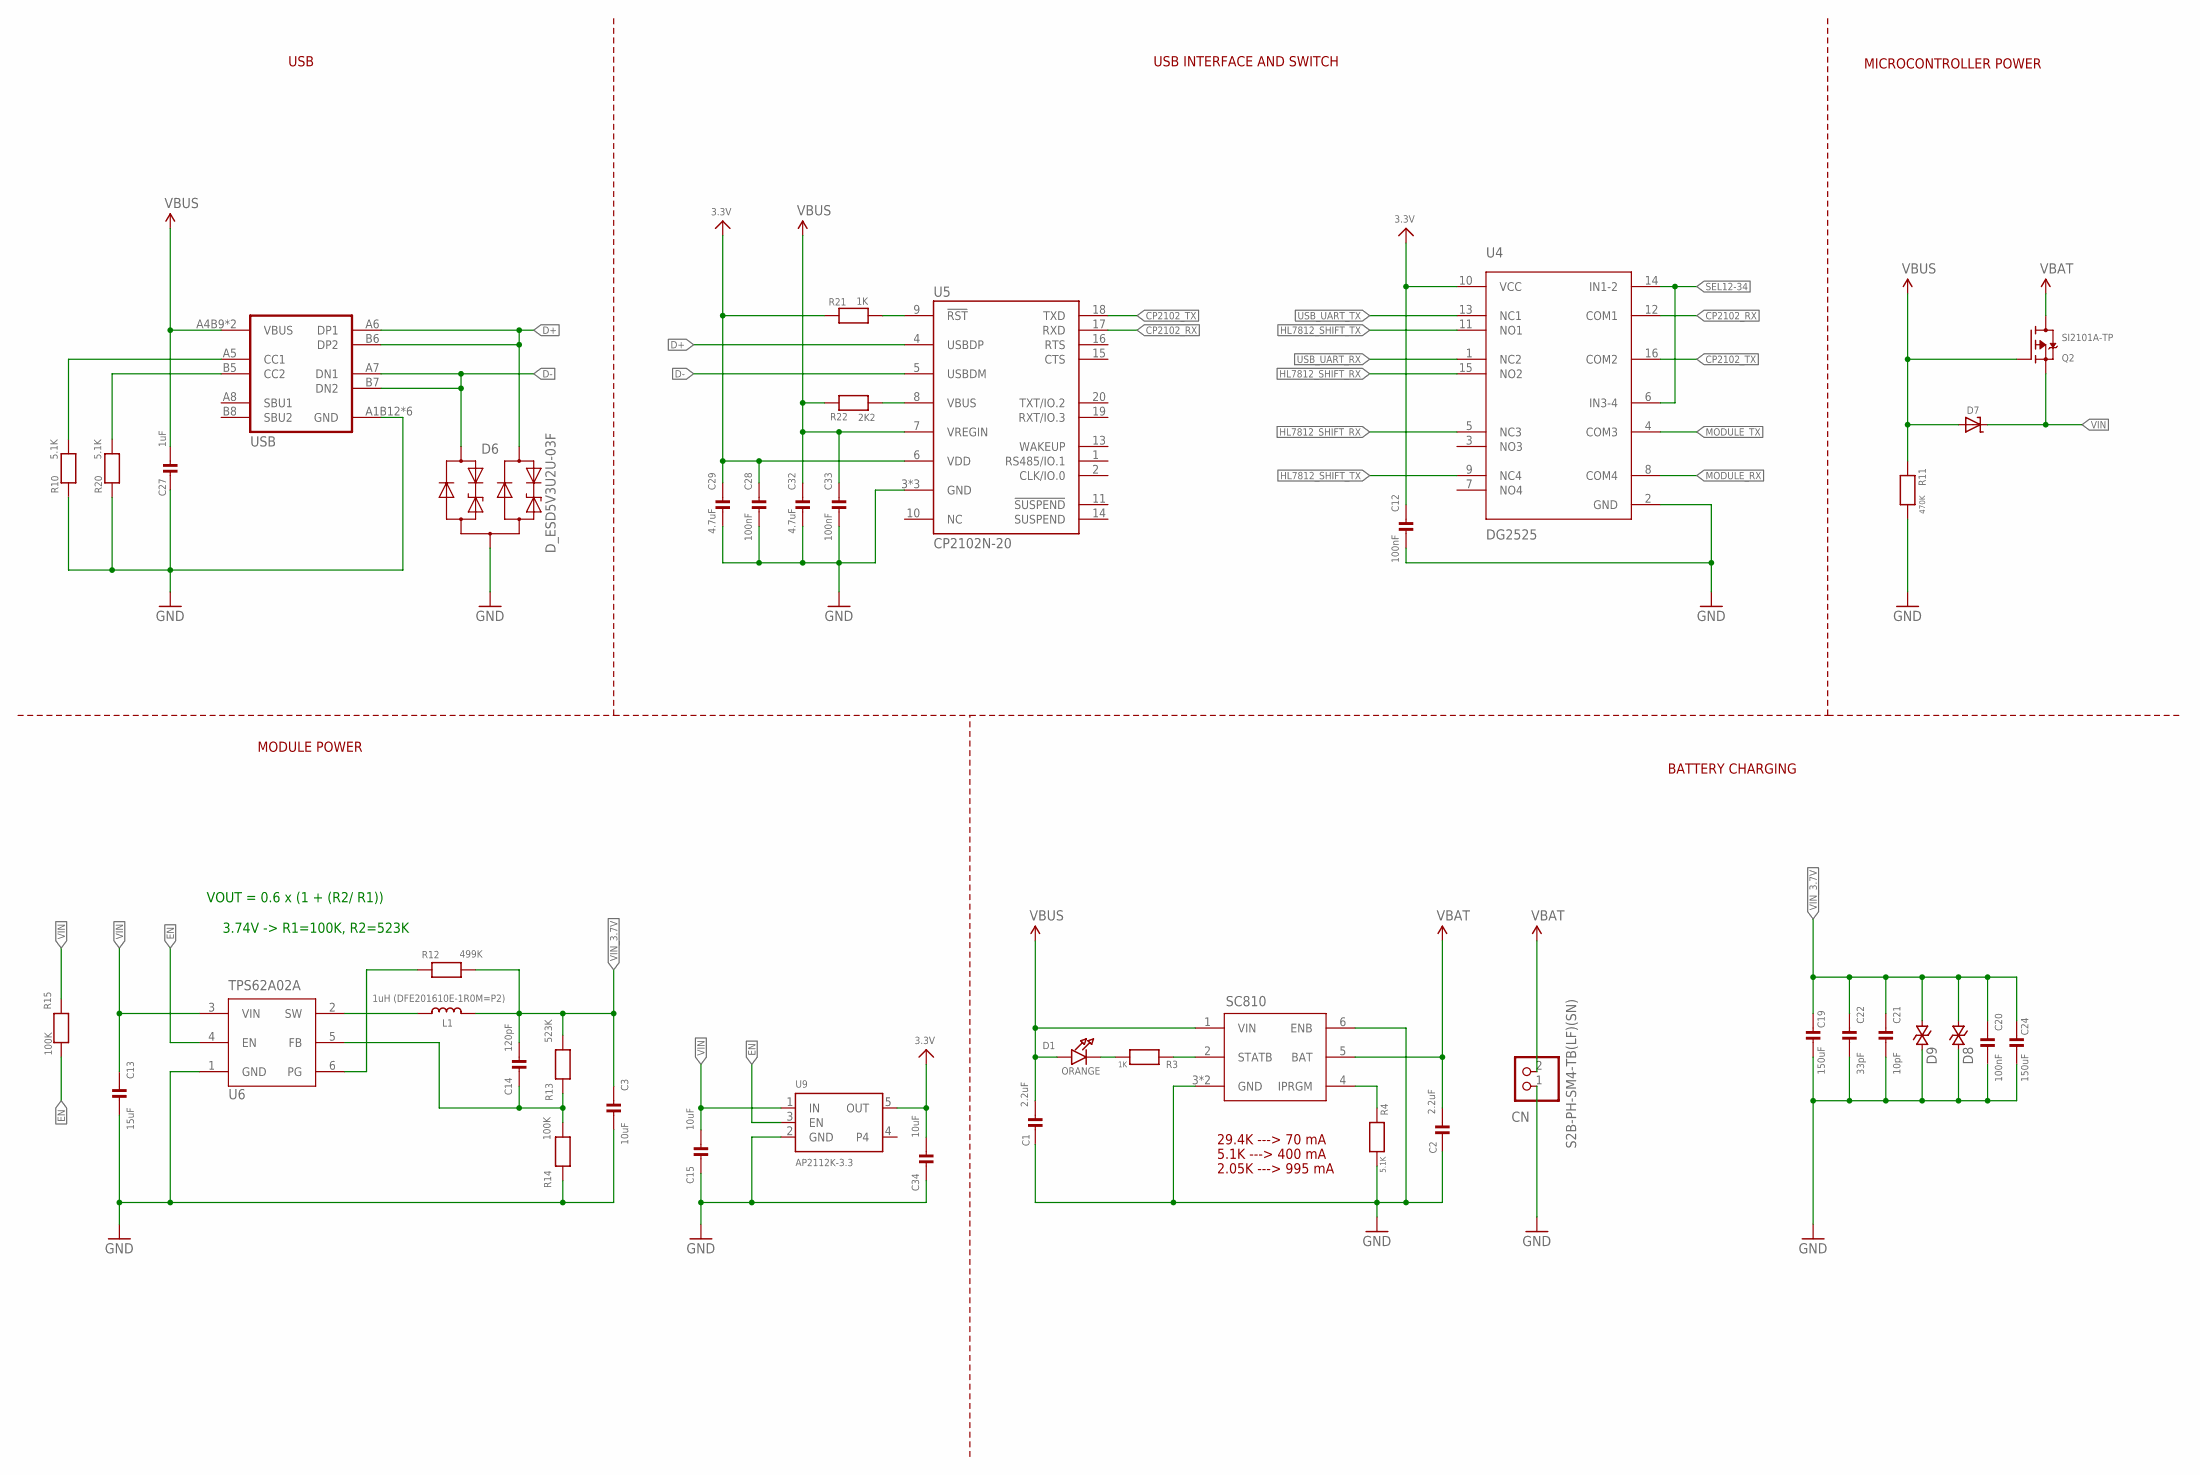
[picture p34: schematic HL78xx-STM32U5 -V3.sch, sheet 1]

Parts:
C1, C2: 2.2uF; _0402
C3: 10uF; 1206
C12, C20, C28, C33: 100nF; _0402
C13: 15uF; _0805
C14: 120pF; 0402
C15, C34: 10uF; 0603
C19, C24: 150uF; 1210-C
C21: 10pF; _0402
C22: 33pF; _0402
C27: 1uF; _0402
C29, C32: 4.7uF; _0402
CN: S2B-PH-SM4-TB(LF)(SN); JSTPH2
D1: ORANGE; CHIPLED_0603
D6: D_ESD5V3U2U-03F; SOT723
D7: DIODE-SCHOTTKYSOD-123; SOD-123
D8, D9: CGA0402MLC-05G; _0402_ESD
L1: 1uH (DFE201610E-1R0M=P2); 0806-IND
Q2: SI2101A-TP; SOT23-3
R3, R21: 1K; 0402-R
R4, R10, R20: 5.1K; 0402-R
R11: 470K; 0402-R
R12: 499K; 0603
R13: 523K; _0603-R
R14, R15: 100K; 0402
R22: 2K2; 0402-R
U1: SC810; MLPD-UT62X2
U4: DG2525; QFN-16L
U5: CP2102N-20; QFN20
U6: TPS62A02A; SOT-563
U9: AP2112K-3.3; SOT23-5@1
USB: USB-4110-CGT; USB4105-CGT

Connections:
3.3V: C12.1, C28.1, C29.1, C34.2, R21.2, U4.10 (VCC), U5.6 (VDD), U9.5 (OUT); also elsewhere on the board
CC1: R10.1, USB.A5 (CC1)
CC2: R20.1, USB.B5 (CC2)
CP2102_RX: U4.12 (COM1), U5.17 (RXD)
CP2102_TX: U4.16 (COM2), U5.18 (TXD)
D+: D6.2 (C2), U5.4 (USBDP), USB.A6 (DP1), USB.B6 (DP2)
D-: D6.1 (C1), U5.5 (USBDM), USB.A7 (DN1), USB.B7 (DN2)
EN: R15.2, U6.4 (EN), U9.3 (EN); also elsewhere on the board
GND: C1.1, C2.1, C3.2, C12.2, C13.2, C15.1, C19.2, C20.2, C21.2, C22.2, C24.2, C27.1, C28.2, C29.2, C32.2, C33.2, C34.1, CN.1, D6.3 (A), D8.1 (A), D9.1 (A), R4.1, R10.2, R11.1, R14.1, R20.2, U1.3 (GND), U1.6 (ENB), U1.THERMAL (GND), U4.2 (GND), U5.3 (GND), U5.12 (GND), U5.TP (GND), U6.1 (GND), U9.2 (GND), USB.A1B12 (GND), USB.B1A12 (GND), USB.N0 (GND), USB.N1 (GND), USB.N2 (GND), USB.N3 (GND); also elsewhere on the board
HL7812_SHIFT_RX: U4.5 (NC3), U4.15 (NO2); also elsewhere on the board
HL7812_SHIFT_TX: U4.9 (NC4), U4.11 (NO1); also elsewhere on the board
MODULE_RX: U4.8 (COM4); also elsewhere on the board
MODULE_TX: U4.4 (COM3); also elsewhere on the board
unnamed: D1.C, R3.1
unnamed: C14.1, R13.1, R14.2, U6.5 (FB)
unnamed: R12.1, U6.6 (PG)
unnamed: L1.1, U6.2 (SW)
unnamed: R22.1, U5.8 (VBUS)
unnamed: R3.2, U1.2 (STATB)
unnamed: R4.2, U1.4 (IPRGM)
NC: U5.10 (NC)
RESET: R21.1, U5.9 (!RST)
SEL12-34: U4.6 (IN3-4), U4.14 (IN1-2); also elsewhere on the board
USB_UART_RX: U4.1 (NC2); also elsewhere on the board
USB_UART_TX: U4.13 (NC1); also elsewhere on the board
VBAT: C2.2, CN.2, Q2.3 (D), U1.5 (BAT); also elsewhere on the board
VBUS: C1.2, C27.2, C32.1, C33.1, D1.A, D7.A, Q2.1 (G), R11.2, R22.2, U1.1 (VIN), U5.7 (VREGIN), USB.A4B9 (VBUS), USB.B4A9 (VBUS); also elsewhere on the board
VIN: C13.1, C15.2, D7.C, Q2.2 (S), R15.1, U6.3 (VIN), U9.1 (IN); also elsewhere on the board
VIN_3.7V: C3.1, C14.2, C19.1, C20.1, C21.1, C22.1, C24.1, D8.2 (C), D9.2 (C), L1.2, R12.2, R13.2; also elsewhere on the board

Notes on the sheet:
BATTERY CHARGING
MODULE POWER
USB
MICROCONTROLLER POWER
USB INTERFACE AND SWITCH
5.1K ---> 400 mA
29.4K ---> 70 mA
2.05K ---> 995 mA
VOUT = 0.6 x (1 + (R2/ R1)) 3.74V -> R1=100K, R2=523K

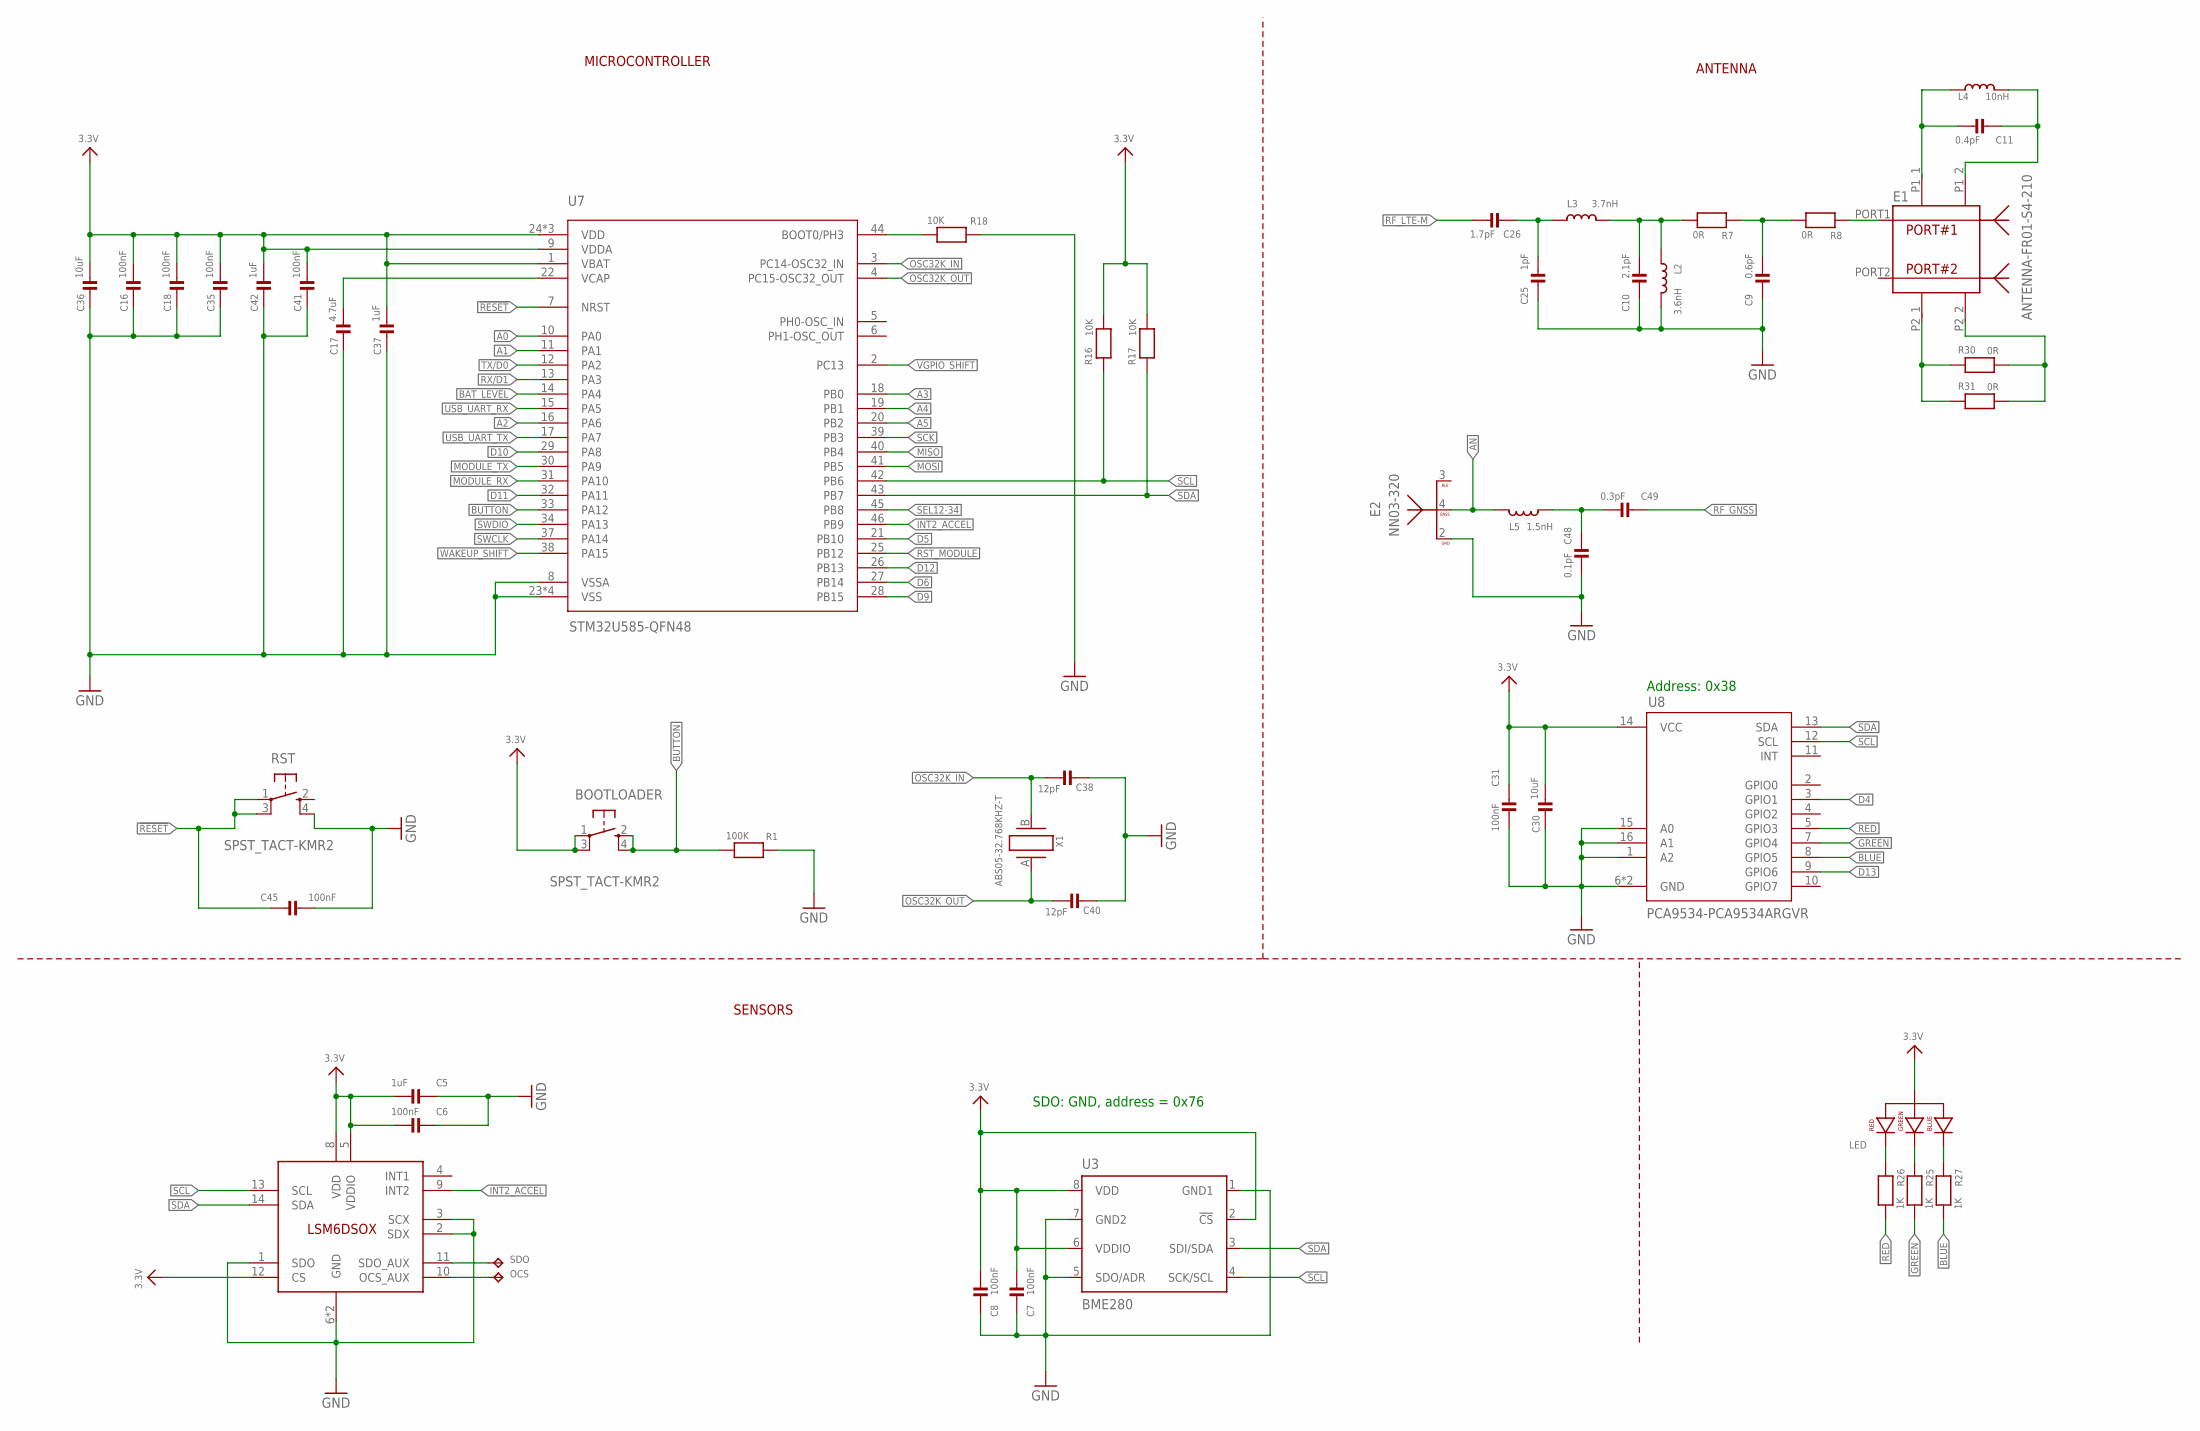
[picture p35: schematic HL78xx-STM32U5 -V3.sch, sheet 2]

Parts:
BOOTLOADER: SPST_TACT-KMR2; KMR2
C5, C37, C42: 1uF; _0402
C6, C7, C8, C16, C18, C31, C35, C41, C45: 100nF; _0402
C9: 0.6pF; C_1MMX1MM-IGNION
C10: 2.1pF; C_1MMX1MM-IGNION
C11: 0.4pF; C_1MMX0.75MM-IGNION
C17: 4.7uF; _0402
C25: 1pF; C_1MMX1MM-IGNION
C26: 1.7pF; C_1MMX1MM-IGNION
C30, C36: 10uF; _0402
C38, C40: 12pF; _0402
C48: 0.1pF; C_1MMX1MM-IGNION
C49: 0.3pF; C_1MMX1MM-IGNION
E1: ANTENNA-FR01-S4-210; XDCR_FR01-S4-210
E2: NN03-320; XCVR_NN03-320
L2: 3.6nH; L_1MMX1MM-IGNION
L3: 3.7nH; L_1MMX1MM-IGNION
L4: 10nH; L_1MMX0.75MM-IGNION
L5: 1.5nH; L_1MMX1MM-IGNION
LED: LED-RGB-ANODE-3.5X2.8-WURTH-150044M155260; LED-WURTH-150044M155260
OCS: TP-1SIDE-1P0; TP-1P0
R1: 100K; 0402-R
R7, R8: 0R; R_1MMX1MM-IGNION
R16, R17, R18: 10K; 0402-R
R25, R26, R27: 1K; 0402-R
R30, R31: 0R; R_1MMX0.75MM-IGNION
RST: SPST_TACT-KMR2; KMR2
SDO: TP-1SIDE-1P0; TP-1P0
U2: LSM6DSOX; LGA-14L
U3: BME280; BME280_LGA
U7: STM32U585-QFN48; TQFN48_7MM
U8: PCA9534-PCA9534ARGVR; QFN16-4X4MM
X1: ABS05-32.768KHZ-T; ABS05

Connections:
3.3V: BOOTLOADER.1, BOOTLOADER.3 (P1), C5.2, C6.2, C7.2, C8.2, C16.1, C18.1, C30.1, C31.1, C35.1, C36.1, C37.1, C41.1, C42.1, LED.1 (ANODE), R16.2, R17.2, U2.5 (VDDIO), U2.8 (VDD), U2.12 (CS), U3.2 (!CS), U3.6 (VDDIO), U3.8 (VDD), U7.1 (VBAT), U7.9 (VDDA), U7.24 (VDD), U7.36 (VDD), U7.48 (VDD), U8.14 (VCC); also elsewhere on the board
!RESET: C45.1, RST.1, RST.3 (P1), U7.7 (NRST); also elsewhere on the board
A0: U7.10 (PA0); also elsewhere on the board
A1: U7.11 (PA1); also elsewhere on the board
A2: U7.16 (PA6); also elsewhere on the board
A3: U7.18 (PB0); also elsewhere on the board
A4: U7.19 (PB1); also elsewhere on the board
A5: U7.20 (PB2); also elsewhere on the board
AN: E2.4 (FEED_GNSS), L5.1
BAT_LEVEL: U7.14 (PA4); also elsewhere on the board
BLUE: R27.2, U8.8 (GPIO5)
BOOT: R18.2, U7.44 (BOOT0/PH3)
BUTTON: BOOTLOADER.2 (S), BOOTLOADER.4 (S1), R1.2, U7.33 (PA12)
D4: U8.3 (GPIO1); also elsewhere on the board
D5: U7.21 (PB10); also elsewhere on the board
D6: U7.27 (PB14); also elsewhere on the board
D9: U7.28 (PB15); also elsewhere on the board
D10: U7.29 (PA8); also elsewhere on the board
D11: U7.32 (PA11); also elsewhere on the board
D12: U7.26 (PB13); also elsewhere on the board
D13: U8.9 (GPIO6); also elsewhere on the board
GND: C5.1, C6.1, C7.1, C8.1, C9.1, C10.1, C16.2, C17.2, C18.2, C25.1, C30.2, C31.2, C35.2, C36.2, C37.2, C38.2, C40.2, C41.2, C42.2, C45.2, C48.2, E2.2 (GROUND), L2.2, R1.1, R18.1, RST.4 (S1), U2.1 (SDO), U2.2 (SDX), U2.3 (SCX), U2.6 (GND), U2.7 (GND), U3.1 (GND1), U3.5 (SDO/ADR), U3.7 (GND2), U7.8 (VSSA), U7.23 (VSS), U7.35 (VSS), U7.47 (VSS), U7.THERMAL (VSS), U8.1 (A2), U8.6 (GND), U8.15 (A0), U8.16 (A1), U8.T (GND); also elsewhere on the board
GREEN: R25.2, U8.7 (GPIO4)
INT2_ACCEL: U2.9 (INT2), U7.46 (PB9)
MISO: U7.40 (PB4); also elsewhere on the board
MODULE_RX: U7.31 (PA10); also elsewhere on the board
MODULE_TX: U7.30 (PA9); also elsewhere on the board
MOSI: U7.41 (PB5); also elsewhere on the board
unnamed: C17.1, U7.22 (VCAP)
unnamed: LED.4 (BLUE_CATHODE), R27.1
unnamed: C48.1, C49.2, L5.2
unnamed: E1.PORT1 (PORT#1), R8.1
unnamed: C10.2, L2.1, L3.2, R7.2
unnamed: C9.2, R7.1, R8.2
unnamed: C25.2, C26.1, L3.1
unnamed: C11.2, E1.P1_1 (SECTION1_1), L4.1
unnamed: C11.1, E1.P1_2 (SECTION1_2), L4.2
unnamed: LED.3 (GREEN_CATHODE), R25.1
unnamed: E1.P2_1 (SECTION2_1), R30.1, R31.1
unnamed: LED.2 (RED_CATHODE), R26.1
unnamed: E1.P2_2 (SECTION2_2), R30.2, R31.2
OCS_AUX: OCS.TP, U2.10 (OCS_AUX)
OSC32K_IN: C38.1, U7.3 (PC14-OSC32_IN), X1.B (2)
OSC32K_OUT: C40.1, U7.4 (PC15-OSC32_OUT), X1.A (1)
RED: R26.2, U8.5 (GPIO3)
RF_GNSS: C49.1; also elsewhere on the board
RF_LTE-M: C26.2; also elsewhere on the board
RST_MODULE: U7.25 (PB12); also elsewhere on the board
RX/D1: U7.13 (PA3); also elsewhere on the board
SCK: U7.39 (PB3); also elsewhere on the board
SCL: R16.1, U2.13 (SCL), U3.4 (SCK/SCL), U7.42 (PB6), U8.12 (SCL); also elsewhere on the board
SDA: R17.1, U2.14 (SDA), U3.3 (SDI/SDA), U7.43 (PB7), U8.13 (SDA); also elsewhere on the board
SDO_AUX: SDO.TP, U2.11 (SDO_AUX)
SEL12-34: U7.45 (PB8); also elsewhere on the board
SWCLK: U7.37 (PA14); also elsewhere on the board
SWDIO: U7.34 (PA13); also elsewhere on the board
TX/D0: U7.12 (PA2); also elsewhere on the board
USB_UART_RX: U7.15 (PA5); also elsewhere on the board
USB_UART_TX: U7.17 (PA7); also elsewhere on the board
VGPIO_SHIFT: U7.2 (PC13); also elsewhere on the board
WAKEUP_SHIFT: U7.38 (PA15); also elsewhere on the board

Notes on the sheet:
MICROCONTROLLER
ANTENNA
SENSORS
Address: 0x38
SDO: GND, address = 0x76

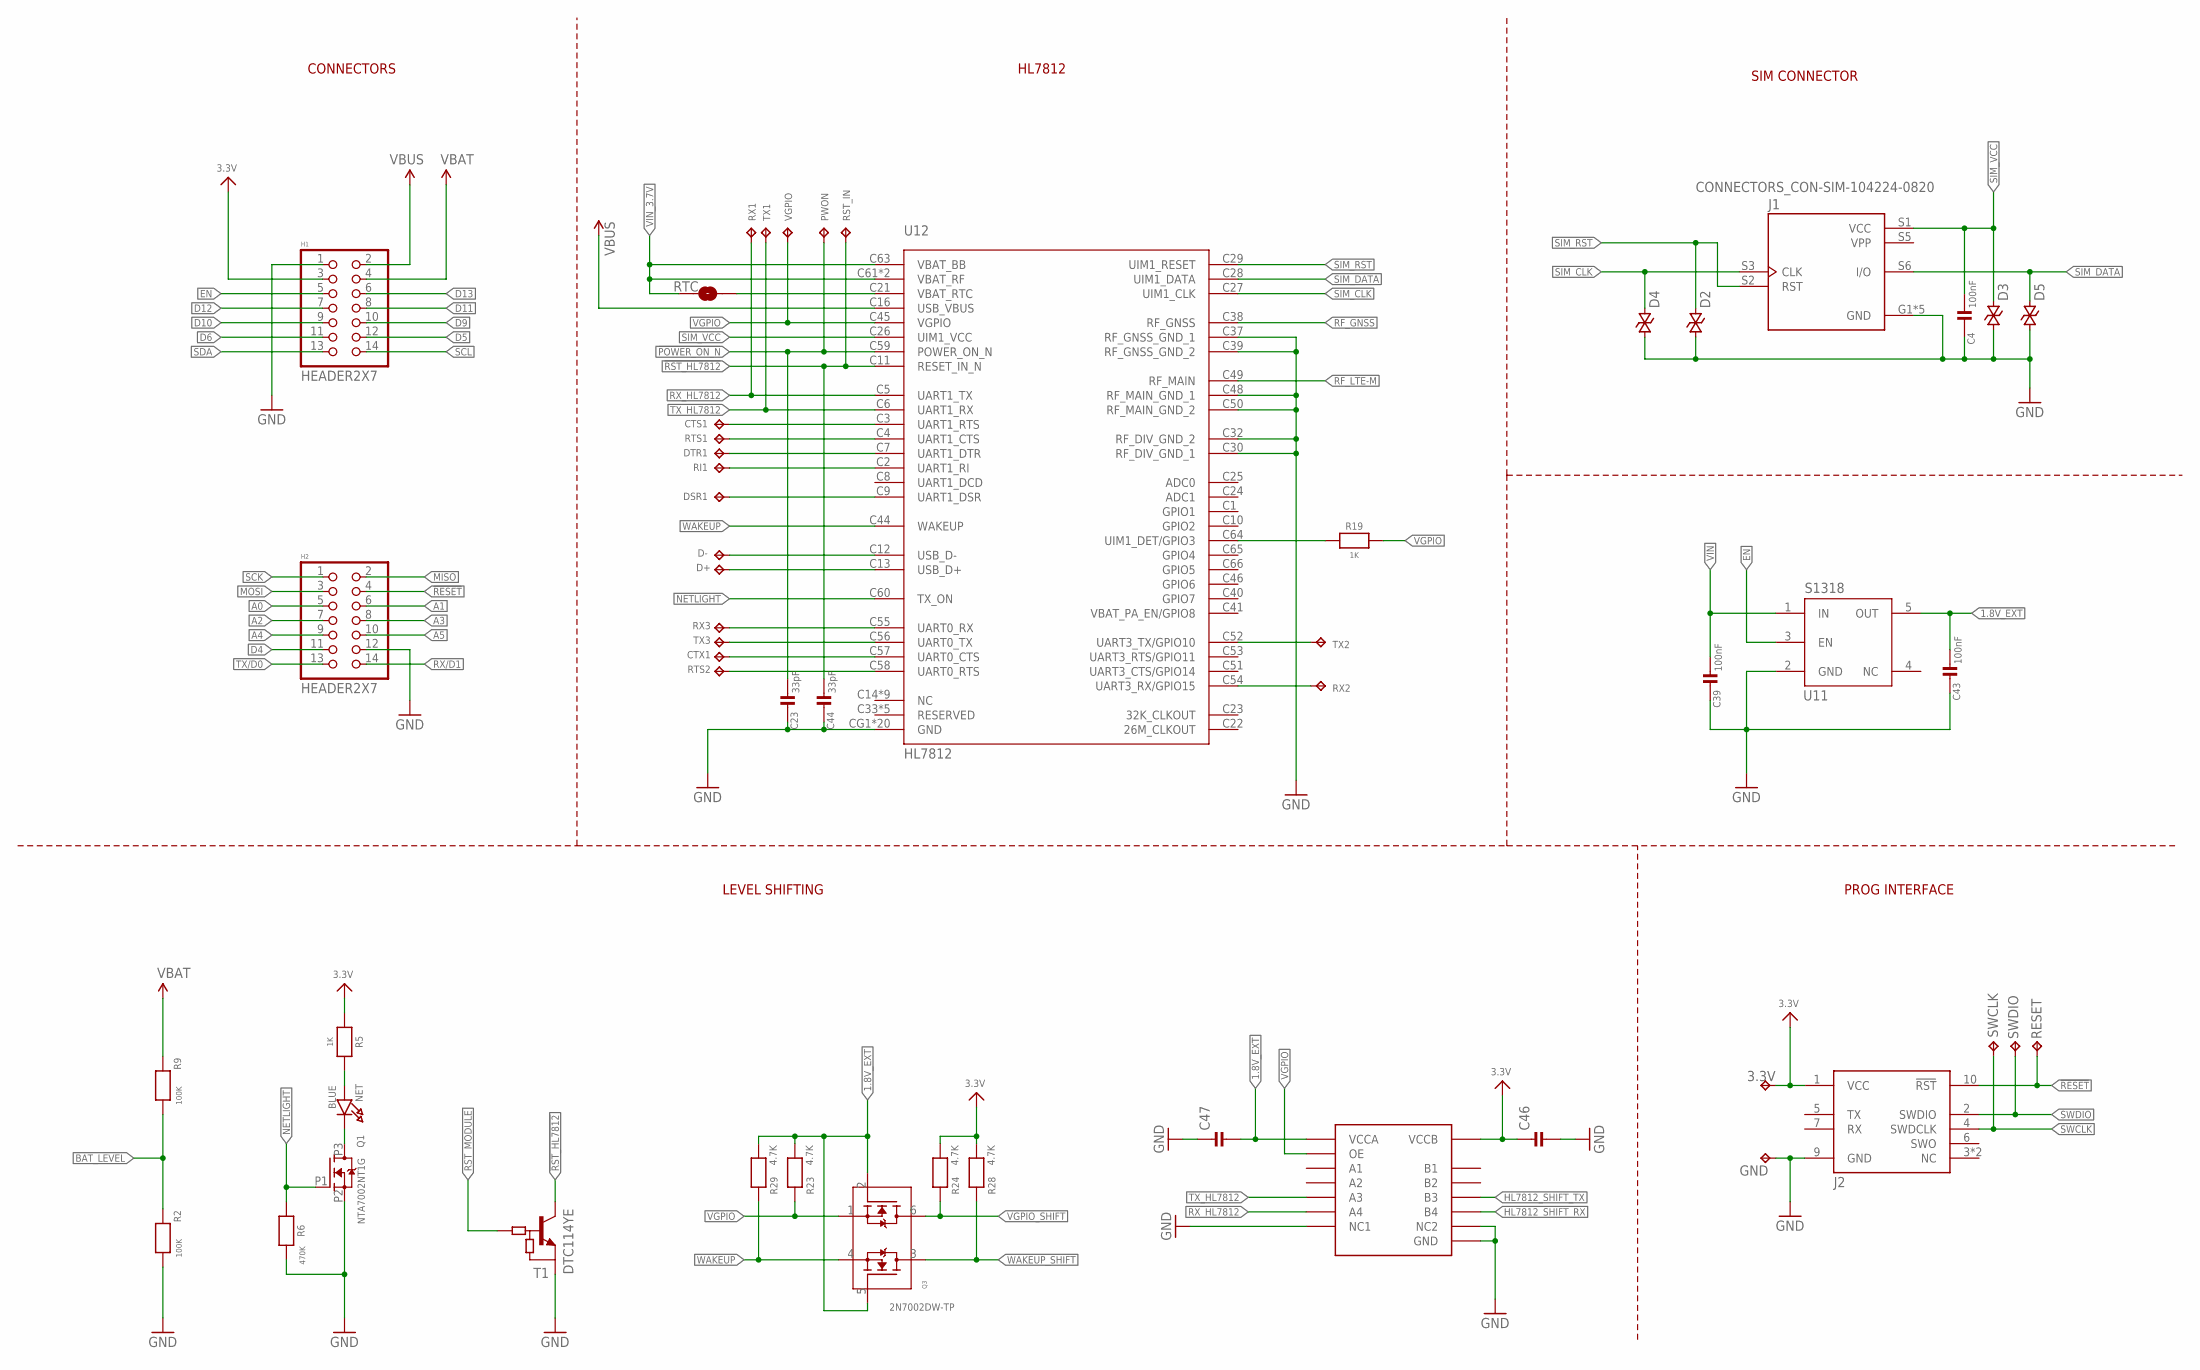
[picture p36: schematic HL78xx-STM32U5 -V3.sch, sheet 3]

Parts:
3.3V: TP-1SIDE-1P0; TP-1P0
C4, C39, C43, C46, C47: 100nF; _0402
C23, C44: 33pF; _0402
CTS1: TP-1SIDE-1P0; TP-1P0
CTX1: TP-1SIDE-1P0; TP-1P0
D2, D3, D4, D5: CGA0402MLC-05G; _0402_ESD
D+: TP-1SIDE-1P0; TP-1P0
D-: TP-1SIDE-1P0; TP-1P0
DSR1: TP-1SIDE-1P0; TP-1P0
DTR1: TP-1SIDE-1P0; TP-1P0
GND: TP-1SIDE-1P0; TP-1P0
H1, H2: HEADER2X7; 2X7-HEADER
J1: CONNECTORS_CON-SIM-104224-0820; CONNECTORS_MOLEX_104224-0820
J2: CON-FTSH-105-XX-X-DV; SAMTEC_FTSH-105-XX-X-DV
NET: BLUE; CHIPLED_0603
PWON: TP-1SIDE-1P0; TP-1P0
Q1: NTA7002NT1G; SC-75/SOT-416
Q3: 2N7002DW-TP; SOT363
R2, R9: 100K; 0402-R
R5, R19: 1K; 0402-R
R6: 470K; 0402-R
R23, R24, R28, R29: 4.7K; 0402-R
RESET: TP-1SIDE-1P0; TP-1P0
RI1: TP-1SIDE-1P0; TP-1P0
RST_IN: TP-1SIDE-1P0; TP-1P0
RTC: JUMPER-SMT_2_NC_PASTE_SILK; SMT-JUMPER_2_NC_PASTE_SILK
RTS1, RTS2: TP-1SIDE-1P0; TP-1P0
RX1, RX2, RX3: TP-1SIDE-1P0; TP-1P0
SWCLK: TP-1SIDE-1P0; TP-1P0
SWDIO: TP-1SIDE-1P0; TP-1P0
T1: DTC114YE; SC-75/SOT-416
TX1, TX2, TX3: TP-1SIDE-1P0; TP-1P0
U10: TXB0104; PVQFN-N14
U11: S1318; SOT23-5
U12: HL7812; HL781X
VGPIO: TP-1SIDE-1P0; TP-1P0

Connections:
1.8V_EXT: C43.1, C47.2, Q3.2 (G1), Q3.5 (G2), R23.2, R29.2, U10.1 (VCCA), U11.5 (OUT)
3.3V: 3.3V.TP, C46.1, H1.3, J2.1 (VCC), R5.1, R24.2, R28.2, U10.14 (VCCB); also elsewhere on the board
!POWER_ON_N: C23.1, PWON.TP, U12.C59 (POWER_ON_N)
!RESET: H2.4, J2.10 (!RST), RESET.TP; also elsewhere on the board
!RST_HL7812: C44.1, RST_IN.TP, T1.P3 (C), U12.C11 (RESET_IN_N)
A0: H2.5; also elsewhere on the board
A1: H2.6; also elsewhere on the board
A2: H2.7; also elsewhere on the board
A3: H2.8; also elsewhere on the board
A4: H2.9; also elsewhere on the board
A5: H2.10; also elsewhere on the board
BAT_LEVEL: R2.1, R9.2; also elsewhere on the board
CTS_HL7812: CTS1.TP, U12.C3 (UART1_RTS)
D4: H2.11; also elsewhere on the board
D5: H1.12; also elsewhere on the board
D6: H1.11; also elsewhere on the board
D9: H1.10; also elsewhere on the board
D10: H1.9; also elsewhere on the board
D11: H1.8; also elsewhere on the board
D12: H1.7; also elsewhere on the board
D13: H1.6; also elsewhere on the board
EN: H1.5, U11.3 (EN); also elsewhere on the board
GND: C4.2, C23.2, C39.2, C43.2, C44.2, C46.2, C47.1, D2.1 (A), D3.1 (A), D4.1 (A), D5.1 (A), GND.TP, H1.1, H2.12, J1.G1 (GND), J1.G2 (GND), J1.G3 (GND), J1.G4 (GND), J1.S4 (GND), J2.9 (GND), Q1.P2 (S), R2.2, R6.2, T1.P2 (E), U10.6 (NC1), U10.7 (GND), U10.9 (NC2), U10.GND, U11.2 (GND), U12.C30 (RF_DIV_GND_1), U12.C32 (RF_DIV_GND_2), U12.C37 (RF_GNSS_GND_1), U12.C39 (RF_GNSS_GND_2), U12.C48 (RF_MAIN_GND_1), U12.C50 (RF_MAIN_GND_2), U12.CG1 (GND), U12.CG2 (GND), U12.CG3 (GND), U12.CG4 (GND), U12.G1 (GND), U12.G2 (GND), U12.G3 (GND), U12.G4 (GND), U12.G5 (GND), U12.G6 (GND), U12.G7 (GND), U12.G8 (GND), U12.G9 (GND), U12.G10 (GND), U12.G11 (GND), U12.G12 (GND), U12.G13 (GND), U12.G14 (GND), U12.G15 (GND), U12.G16 (GND); also elsewhere on the board
HL7812_SHIFT_RX: U10.10 (B4); also elsewhere on the board
HL7812_SHIFT_TX: U10.11 (B3); also elsewhere on the board
HL_D+: D-.TP, U12.C12 (USB_D-)
HL_D-: D+.TP, U12.C13 (USB_D+)
MISO: H2.2; also elsewhere on the board
MOSI: H2.3; also elsewhere on the board
unnamed: NET.C, Q1.P3 (D)
unnamed: NET.A, R5.2
unnamed: RX2.TP, U12.C54 (UART3_RX/GPIO15)
unnamed: TX2.TP, U12.C52 (UART3_TX/GPIO10)
unnamed: RX3.TP, U12.C55 (UART0_RX)
unnamed: TX3.TP, U12.C56 (UART0_TX)
unnamed: CTX1.TP, U12.C57 (UART0_CTS)
unnamed: RTS2.TP, U12.C58 (UART0_RTS)
unnamed: RI1.TP, U12.C2 (UART1_RI)
unnamed: DTR1.TP, U12.C7 (UART1_DTR)
unnamed: DSR1.TP, U12.C9 (UART1_DSR)
unnamed: RTC.2, U12.C21 (VBAT_RTC)
NETLIGHT: Q1.P1 (G), R6.1, U12.C60 (TX_ON)
RF_GNSS: U12.C38 (RF_GNSS); also elsewhere on the board
RF_LTE-M: U12.C49 (RF_MAIN); also elsewhere on the board
RST_MODULE: T1.P1 (B); also elsewhere on the board
RTS_HL7812: RTS1.TP, U12.C4 (UART1_CTS)
RX/D1: H2.14; also elsewhere on the board
RX_HL7812: RX1.TP, U10.5 (A4), U12.C5 (UART1_TX)
SCK: H2.1; also elsewhere on the board
SCL: H1.14; also elsewhere on the board
SDA: H1.13; also elsewhere on the board
SIM_CLK: D4.2 (C), J1.S3 (CLK), U12.C27 (UIM1_CLK)
SIM_DATA: D5.2 (C), J1.S6 (I/O), U12.C28 (UIM1_DATA)
SIM_RST: D2.2 (C), J1.S2 (RST), U12.C29 (UIM1_RESET)
SIM_VCC: C4.1, D3.2 (C), J1.S1 (VCC), U12.C26 (UIM1_VCC)
SWCLK: J2.4 (SWDCLK), SWCLK.TP; also elsewhere on the board
SWDIO: J2.2 (SWDIO), SWDIO.TP; also elsewhere on the board
TX/D0: H2.13; also elsewhere on the board
TX_HL7812: TX1.TP, U10.4 (A3), U12.C6 (UART1_RX)
UIM1_DET: R19.1, U12.C64 (UIM1_DET/GPIO3)
VBAT: H1.4, R9.1; also elsewhere on the board
VBUS: H1.2, U12.C16 (USB_VBUS); also elsewhere on the board
VGPIO: Q3.1 (S1), R19.2, R23.1, U10.8 (OE), U12.C45 (VGPIO), VGPIO.TP
VGPIO_SHIFT: Q3.6 (D1), R24.1; also elsewhere on the board
VIN: C39.1, U11.1 (IN); also elsewhere on the board
VIN_3.7V: RTC.1, U12.C61 (VBAT_RF), U12.C62 (VBAT_RF), U12.C63 (VBAT_BB); also elsewhere on the board
VPP: J1.S5 (VPP)
WAKEUP: Q3.4 (S2), R29.1, U12.C44 (WAKEUP)
WAKEUP_SHIFT: Q3.3 (D2), R28.1; also elsewhere on the board

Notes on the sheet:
LEVEL SHIFTING
HL7812
CONNECTORS
SIM CONNECTOR
PROG INTERFACE

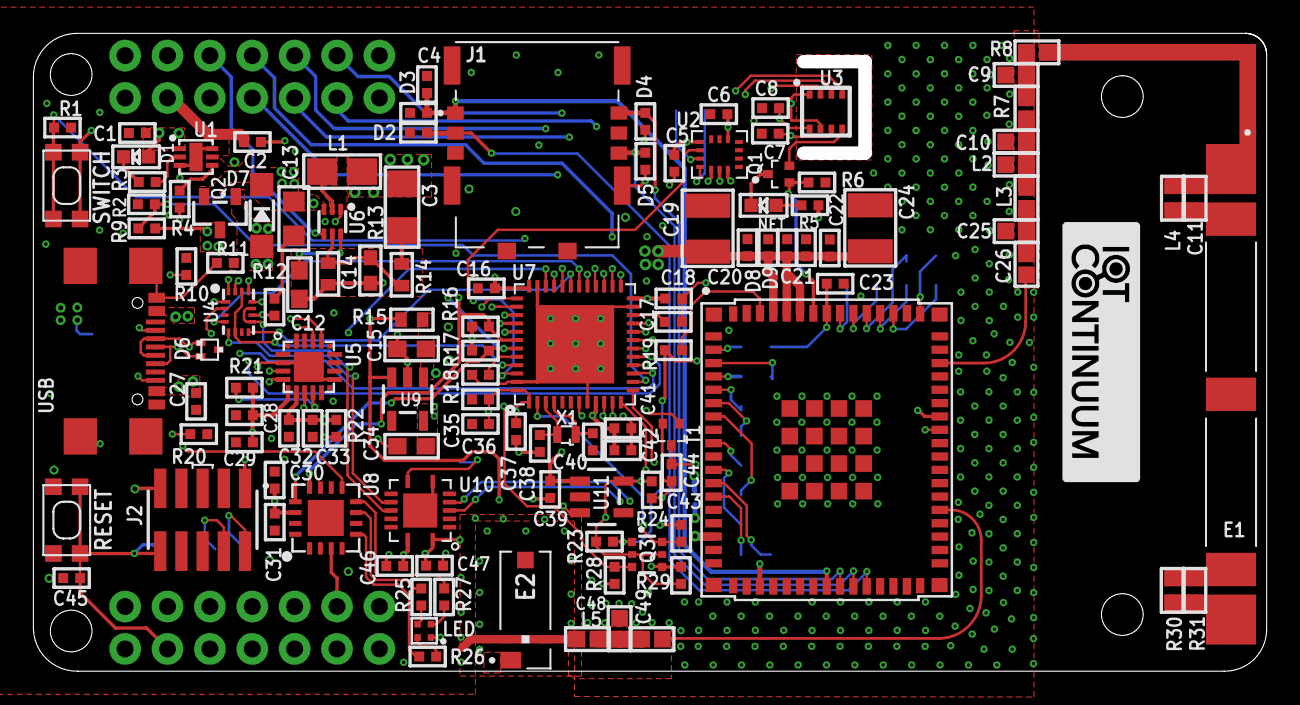
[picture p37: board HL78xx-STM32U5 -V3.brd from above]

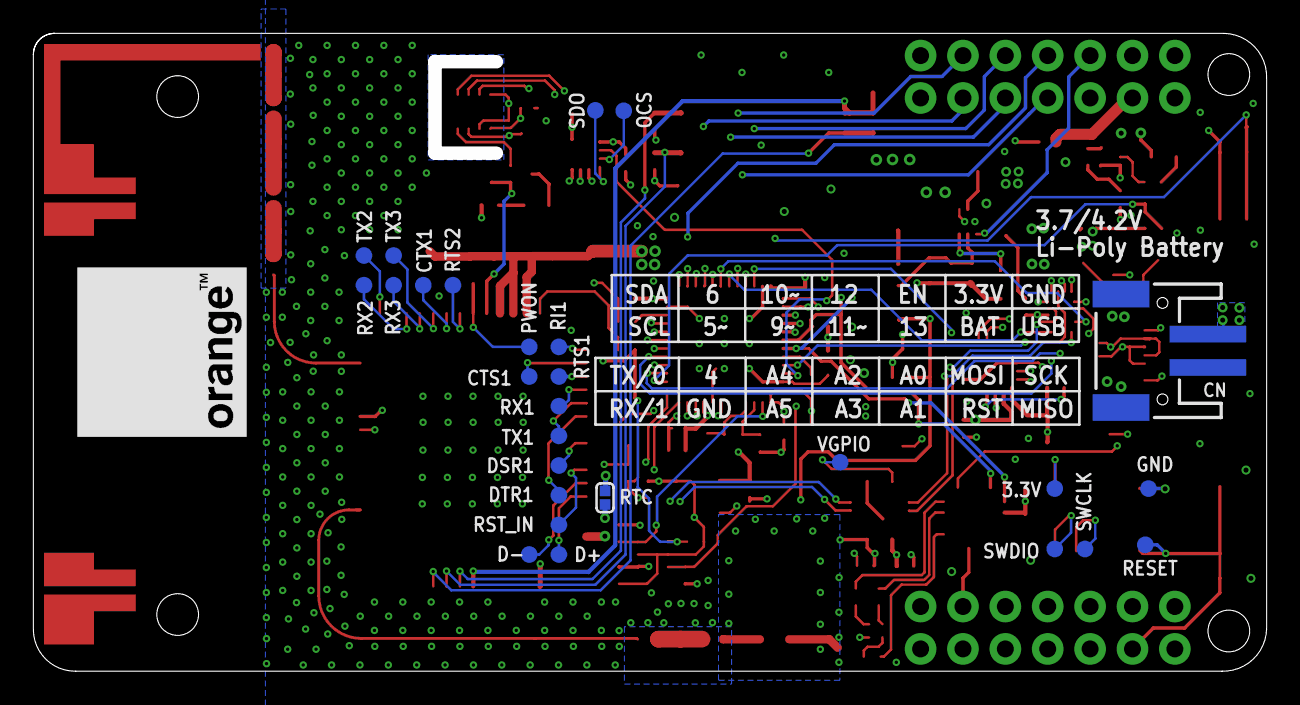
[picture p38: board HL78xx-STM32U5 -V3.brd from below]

Board: 6 copper layers, 73.9 x 38.2 mm, 149 parts (27 on the bottom side), 111 nets.

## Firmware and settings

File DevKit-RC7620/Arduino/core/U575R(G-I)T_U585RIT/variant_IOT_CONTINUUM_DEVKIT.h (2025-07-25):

/*
 *******************************************************************************
 * Copyright (c) 2020, STMicroelectronics
 * All rights reserved.
 *
 * This software component is licensed by ST under BSD 3-Clause license,
 * the "License"; You may not use this file except in compliance with the
 * License. You may obtain a copy of the License at:
 *                        opensource.org/licenses/BSD-3-Clause
 *
 *******************************************************************************
 */
#pragma once

/*----------------------------------------------------------------------------
 *        STM32 pins number
 *----------------------------------------------------------------------------*/
#define PA0                     PIN_A0
#define PA1                     PIN_A1
#define PA2                     PIN_A2
#define PA3                     PIN_A3
#define PA4                     PIN_A4
#define PA5                     PIN_A5
#define PA6                     PIN_A6
#define PA7                     PIN_A7
#define PA8                     8
#define PA9                     9
#define PA10                    10
#define PA11                    11
#define PA12                    12
#define PA13                    13
#define PA14                    14
#define PA15                    15
#define PB0                     PIN_A8
#define PB1                     PIN_A9
#define PB2                     PIN_A10
#define PB3                     19
#define PB4                     20
#define PB5                     21
#define PB6                     22
#define PB7                     23
#define PB8                     24
#define PB9                     25
#define PB10                    26
#define PB12                    27
#define PB13                    28
#define PB14                    29
#define PB15                    30
#define PC0                     PIN_A11
#define PC1                     PIN_A12
#define PC2                     PIN_A13
#define PC3                     PIN_A14
#define PC4                     PIN_A15
#define PC5                     PIN_A16
#define PC6                     37
#define PC7                     38
#define PC8                     39
#define PC9                     40
#define PC10                    41
#define PC11                    42
#define PC12                    43
#define PC13                    44
#define PC14                    45
#define PC15                    46
#define PD2                     47
#define PH0                     48
#define PH1                     49
#define PH3                     50

// Alternate pins number
#define PA0_ALT1                (PA0  | ALT1)
#define PA1_ALT1                (PA1  | ALT1)
#define PA1_ALT2                (PA1  | ALT2)
#define PA2_ALT1                (PA2  | ALT1)
#define PA2_ALT2                (PA2  | ALT2)
#define PA3_ALT1                (PA3  | ALT1)
#define PA3_ALT2                (PA3  | ALT2)
#define PA4_ALT1                (PA4  | ALT1)
#define PA5_ALT1                (PA5  | ALT1)
#define PA6_ALT1                (PA6  | ALT1)
#define PA7_ALT1                (PA7  | ALT1)
#define PA7_ALT2                (PA7  | ALT2)
#define PA7_ALT3                (PA7  | ALT3)
#define PA15_ALT1               (PA15 | ALT1)
#define PB0_ALT1                (PB0  | ALT1)
#define PB0_ALT2                (PB0  | ALT2)
#define PB1_ALT1                (PB1  | ALT1)
#define PB1_ALT2                (PB1  | ALT2)
#define PB3_ALT1                (PB3  | ALT1)
#define PB4_ALT1                (PB4  | ALT1)
#define PB5_ALT1                (PB5  | ALT1)
#define PB6_ALT1                (PB6  | ALT1)
#define PB7_ALT1                (PB7  | ALT1)
#define PB8_ALT1                (PB8  | ALT1)
#define PB9_ALT1                (PB9  | ALT1)
#define PB10_ALT1               (PB10 | ALT1)
#define PB13_ALT1               (PB13 | ALT1)
#define PB14_ALT1               (PB14 | ALT1)
#define PB14_ALT2               (PB14 | ALT2)
#define PB15_ALT1               (PB15 | ALT1)
#define PB15_ALT2               (PB15 | ALT2)
#define PC0_ALT1                (PC0  | ALT1)
#define PC1_ALT1                (PC1  | ALT1)
#define PC2_ALT1                (PC2  | ALT1)
#define PC3_ALT1                (PC3  | ALT1)
#define PC4_ALT1                (PC4  | ALT1)
#define PC5_ALT1                (PC5  | ALT1)
#define PC6_ALT1                (PC6  | ALT1)
#define PC7_ALT1                (PC7  | ALT1)
#define PC8_ALT1                (PC8  | ALT1)
#define PC9_ALT1                (PC9  | ALT1)
#define PC10_ALT1               (PC10 | ALT1)
#define PC11_ALT1               (PC11 | ALT1)

#define NUM_DIGITAL_PINS        51
#define NUM_ANALOG_INPUTS       17

// On-board LED pin number
#ifndef LED_BUILTIN
  #define LED_BUILTIN           PNUM_NOT_DEFINED
#endif

// On-board user button
#ifndef USER_BTN
  #define USER_BTN              PNUM_NOT_DEFINED
#endif

// SPI definitions
/*#ifndef PIN_SPI_SS
  #define PIN_SPI_SS            PA4
#endif
#ifndef PIN_SPI_SS1
  #define PIN_SPI_SS1           PA15
#endif
#ifndef PIN_SPI_SS2
  #define PIN_SPI_SS2           PB0
#endif
#ifndef PIN_SPI_SS3
  #define PIN_SPI_SS3           PNUM_NOT_DEFINED
#endif
#ifndef PIN_SPI_MOSI
  #define PIN_SPI_MOSI          PA7
#endif
#ifndef PIN_SPI_MISO
  #define PIN_SPI_MISO          PA6
#endif
#ifndef PIN_SPI_SCK
  #define PIN_SPI_SCK           PA1
#endif

// Timer Definitions
// Use TIM6/TIM7 when possible as servo and tone don't need GPIO output pin
#ifndef TIMER_TONE
  #define TIMER_TONE            TIM6
#endif
#ifndef TIMER_SERVO
  #define TIMER_SERVO           TIM7
#endif
*/
// UART Definitions
#ifndef SERIAL_UART_INSTANCE
  #define SERIAL_UART_INSTANCE  4
#endif

// Default pin used for generic 'Serial' instance
// Mandatory for Firmata
#ifndef PIN_SERIAL_RX
  #define PIN_SERIAL_RX         PC11
#endif
#ifndef PIN_SERIAL_TX
  #define PIN_SERIAL_TX         PC10
#endif

// Extra HAL modules
#if !defined(HAL_DAC_MODULE_DISABLED)
  #define HAL_DAC_MODULE_ENABLED
#endif
#if !defined(HAL_OSPI_MODULE_DISABLED)
  #define HAL_OSPI_MODULE_ENABLED
#endif
#if !defined(HAL_SD_MODULE_DISABLED)
  #define HAL_SD_MODULE_ENABLED
#endif

// Alternate SYS_WKUP definition
#define PWR_WAKEUP_PIN1_1
#define PWR_WAKEUP_PIN2_1
#define PWR_WAKEUP_PIN3_1
#define PWR_WAKEUP_PIN4_1
#define PWR_WAKEUP_PIN4_2
#define PWR_WAKEUP_PIN5_1
#define PWR_WAKEUP_PIN5_2
#define PWR_WAKEUP_PIN6_1
#define PWR_WAKEUP_PIN7_1
#define PWR_WAKEUP_PIN8_1

/*----------------------------------------------------------------------------
 *        Arduino objects - C++ only
 *----------------------------------------------------------------------------*/
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

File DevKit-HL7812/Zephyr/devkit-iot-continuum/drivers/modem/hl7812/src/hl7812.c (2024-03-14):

/*
 * Copyright (c) 2020 Laird Connectivity
 *
 * SPDX-License-Identifier: Apache-2.0
 */

#define DT_DRV_COMPAT swir_hl7812

#include <zephyr/logging/log.h>
#include <zephyr/logging/log_ctrl.h>
#define LOG_MODULE_NAME modem_hl7812
LOG_MODULE_REGISTER(LOG_MODULE_NAME, CONFIG_MODEM_LOG_LEVEL);

#include <zephyr/types.h>
#include <stddef.h>
#include <stdlib.h>
#include <ctype.h>
#include <errno.h>
#include <zephyr/kernel.h>
#include <zephyr/drivers/gpio.h>
#include <zephyr/device.h>
#include <zephyr/init.h>

#include <zephyr/pm/device.h>
#include <zephyr/drivers/uart.h>

#include <zephyr/net/net_context.h>
#include <zephyr/net/net_if.h>
#include <zephyr/net/net_offload.h>
#include <zephyr/net/net_pkt.h>
#include <zephyr/net/dns_resolve.h>
#if defined(CONFIG_NET_IPV6)
   #include "ipv6.h"
#endif
#if defined(CONFIG_NET_IPV4)
   #include "ipv4.h"
#endif
#if defined(CONFIG_NET_UDP)
   #include "udp_internal.h"
#endif

#ifdef CONFIG_MODEM_HL7812_FW_UPDATE
   #include <zephyr/fs/fs.h>
#endif

#include <modem_receiver.h>
#include <hl7812.h>

#define PREFIXED_SWITCH_CASE_RETURN_STRING(prefix, val) \
   case prefix##_##val:                                 \
      {                                                 \
         return #val;                                   \
      }

/* Uncomment the #define below to enable a hexdump of all incoming
 * data from the modem receiver
 */
/* #define HL7812_ENABLE_VERBOSE_MODEM_RECV_HEXDUMP 1 */

#define HL7812_LOG_UNHANDLED_RX_MSGS 1

/* Uncomment the #define(s) below to enable extra debugging */
/* #define HL7812_RX_LOCK_LOG 1 */
/* #define HL7812_TX_LOCK_LOG 1 */
#define HL7812_IO_LOG                1

#define HL7812_RX_LOCK_DBG_LOG(fmt, ...) \
   do                                    \
   {                                     \
      if(IS_ENABLED(HL7812_RX_LOCK_LOG)) \
      {                                  \
         LOG_DBG(fmt, ##__VA_ARGS__);    \
      }                                  \
   }                                     \
   while(false)

#define HL7812_TX_LOCK_DBG_LOG(fmt, ...) \
   do                                    \
   {                                     \
      if(IS_ENABLED(HL7812_TX_LOCK_LOG)) \
      {                                  \
         LOG_DBG(fmt, ##__VA_ARGS__);    \
      }                                  \
   }                                     \
   while(false)

#define HL7812_IO_DBG_LOG(fmt, ...)   \
   do                                 \
   {                                  \
      if(IS_ENABLED(HL7812_IO_LOG))   \
      {                               \
         LOG_DBG(fmt, ##__VA_ARGS__); \
      }                               \
   }                                  \
   while(false)

#if((LOG_LEVEL == LOG_LEVEL_DBG) && defined(CONFIG_MODEM_HL7812_LOW_POWER_MODE))
   #define PRINT_AWAKE_MSG     LOG_WRN("awake")
   #define PRINT_NOT_AWAKE_MSG LOG_WRN("NOT awake")
#else
   #define PRINT_AWAKE_MSG
   #define PRINT_NOT_AWAKE_MSG
#endif

enum tcp_notif
{
   HL7812_TCP_NET_ERR,
   HL7812_TCP_NO_SOCKS,
   HL7812_TCP_MEM,
   HL7812_TCP_DNS,
   HL7812_TCP_DISCON,
   HL7812_TCP_CONN,
   HL7812_TCP_ERR,
   HL7812_TCP_CLIENT_REQ,
   HL7812_TCP_DATA_SND,
   HL7812_TCP_ID,
   HL7812_TCP_RUNNING,
   HL7812_TCP_ALL_USED,
   HL7812_TCP_TIMEOUT,
   HL7812_TCP_SSL_CONN,
   HL7812_TCP_SSL_INIT
};

enum udp_notif
{
   HL7812_UDP_NET_ERR  = 0,
   HL7812_UDP_NO_SOCKS = 1,
   HL7812_UDP_MEM      = 2,
   HL7812_UDP_DNS      = 3,
   HL7812_UDP_CONN     = 5,
   HL7812_UDP_ERR      = 6,
   HL7812_UDP_DATA_SND = 8, /* this matches TCP_DATA_SND */
   HL7812_UDP_ID       = 9,
   HL7812_UDP_RUNNING  = 10,
   HL7812_UDP_ALL_USED = 11
};

enum socket_state
{
   SOCK_IDLE,
   SOCK_RX,
   SOCK_TX,
   SOCK_CONNECTED,
};

enum hl7812_lpm
{
   HL7812_LPM_NONE,
   HL7812_LPM_EDRX,
   HL7812_LPM_PSM,
};

/* pin settings */
enum mdm_control_pins
{
   MDM_RESET = 0,
   MDM_WAKE,
   MDM_PWR_ON,
   MDM_FAST_SHUTD,
   MDM_VGPIO,
   MDM_UART_DSR,
   MDM_UART_CTS,
   MDM_GPIO6,
   MAX_MDM_CONTROL_PINS,
};

enum net_operator_status
{
   NO_OPERATOR,
   REGISTERED
};

enum device_service_indications
{
   WDSI_PKG_DOWNLOADED = 3,
};

#ifdef CONFIG_MODEM_HL7812_FW_UPDATE
enum XMODEM_CONTROL_CHARACTERS
{
   XM_SOH    = 0x01,
   XM_SOH_1K = 0x02,
   XM_EOT    = 0x04,
   XM_ACK    = 0x06, /* 'R' */
   XM_NACK   = 0x15, /* 'N' */
   XM_ETB    = 0x17,
   XM_CAN    = 0x18,
   XM_C      = 0x43
};

   #define XMODEM_DATA_SIZE   1024
   #define XMODEM_PACKET_SIZE (XMODEM_DATA_SIZE + 4)
   #define XMODEM_PAD_VALUE   26

struct xmodem_packet
{
   uint8_t preamble;
   uint8_t id;
   uint8_t id_complement;
   uint8_t data[XMODEM_DATA_SIZE];
   uint8_t crc;
};
#endif

#define MDM_UART_DEV              DEVICE_DT_GET(DT_INST_BUS(0))

#define MDM_SEND_OK_ENABLED       0
#define MDM_SEND_OK_DISABLED      1

#define MDM_CMD_SEND_TIMEOUT      K_SECONDS(6)
#define MDM_IP_SEND_RX_TIMEOUT    K_SECONDS(62)
#define MDM_SOCK_NOTIF_DELAY      K_MSEC(150)
#define MDM_CMD_CONN_TIMEOUT      K_SECONDS(31)

#define MDM_MAX_DATA_LENGTH       1500
#define MDM_MTU                   1500
#define MDM_MAX_RESP_SIZE         128
#define MDM_IP_INFO_RESP_SIZE     256

#define MDM_HANDLER_MATCH_MAX_LEN 100

#define MDM_MAX_SOCKETS           6

/* Special value used to indicate that a socket is being created
 * and that its actual ID hasn't been assigned yet.
 */
#define MDM_CREATE_SOCKET_ID      (MDM_MAX_SOCKETS + 1)

#define MDM_HTTP_SOCKET_ID        1

#define BUF_ALLOC_TIMEOUT         K_SECONDS(1)

#define SIZE_OF_NUL               1

#define SIZE_WITHOUT_NUL(v)       (sizeof(v) - SIZE_OF_NUL)

#define CMD_HANDLER(cmd_, cb_)                                                 \
   {                                                                           \
      .cmd = cmd_, .cmd_len = (uint16_t)sizeof(cmd_) - 1, .func = on_cmd_##cb_ \
   }

#define MDM_MANUFACTURER_LENGTH        16
#define MDM_MODEL_LENGTH               7
#define MDM_SN_RESPONSE_LENGTH         (MDM_HL7812_SERIAL_NUMBER_SIZE + 7)
#define MDM_NETWORK_STATUS_LENGTH      45

#define MDM_TOP_BAND_SIZE              4
#define MDM_MIDDLE_BAND_SIZE           8
#define MDM_BOTTOM_BAND_SIZE           8
#define MDM_TOP_BAND_START_POSITION    2
#define MDM_MIDDLE_BAND_START_POSITION 6
#define MDM_BOTTOM_BAND_START_POSITION 14
#define MDM_BAND_BITMAP_STR_LENGTH_MAX (MDM_TOP_BAND_SIZE + MDM_MIDDLE_BAND_SIZE + MDM_BOTTOM_BAND_SIZE)
#define MDM_BAND_BITMAP_STR_LENGTH_MIN 1

#define MDM_DEFAULT_AT_CMD_RETRIES     3
#define MDM_WAKEUP_TIME                K_SECONDS(12)
#define MDM_BOOT_TIME                  K_SECONDS(12)
#define MDM_WAKE_TO_CHECK_CTS_DELAY_MS K_MSEC(20)

#define MDM_WAIT_FOR_DATA_TIME         K_MSEC(50)
#define MDM_RESET_LOW_TIME             K_MSEC(50)
#define MDM_RESET_HIGH_TIME            K_MSEC(10)
#define MDM_WAIT_FOR_DATA_RETRIES      3
#define MDM_WAIT_FOR_HTTP_GET_TIME     K_SECONDS(5)

#define RSSI_UNKNOWN                   -999
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

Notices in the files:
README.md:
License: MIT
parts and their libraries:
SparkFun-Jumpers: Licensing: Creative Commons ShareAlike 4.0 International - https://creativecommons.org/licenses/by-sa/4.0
